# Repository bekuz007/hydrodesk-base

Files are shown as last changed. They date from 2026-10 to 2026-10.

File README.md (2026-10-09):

# 💧 HydroDesk Base

**Smarter Trinkmengen-Untersetzer für den Schreibtisch** – ESP32 mit Touch-Display, Wägezelle und LED-Lichtlinie.
Schulprojekt im Ausbildungsberuf Fachinformatiker/-in für Anwendungsentwicklung (FI-AE), 2 Auszubildende.

HydroDesk Base ist ein flaches, rechteckiges Gerät (180 × 100 × 25 mm), auf das man **jede beliebige Wasserflasche** stellt.
Eine 5-kg-Wägezelle misst das Gewicht und rechnet es in getrunkene Milliliter um.
Das eingebaute 2,8"-Touch-Display zeigt Tagesziel, Fortschritt und Erinnerungen – eine gleichmäßig leuchtende Lichtlinie an der Vorderkante (COB-LED-Streifen hinter einem gedruckten Diffusor) erinnert ans Trinken.

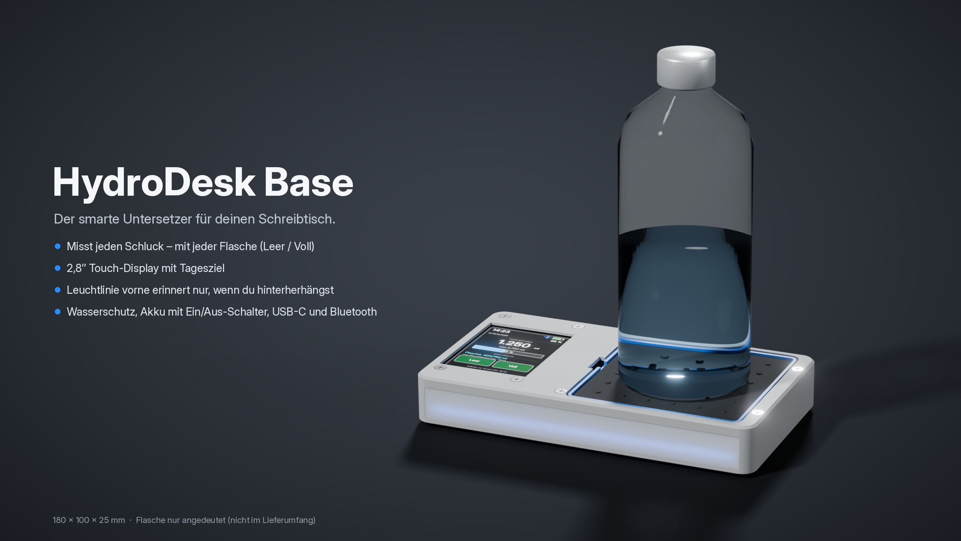
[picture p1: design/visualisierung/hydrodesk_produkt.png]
HydroDesk Base – Produktbild


## ✨ Funktionen

- **Jede Flasche passt** – keine teure Smart-Flasche nötig
- **Gewicht → ml**: 5-kg-Wägezelle + HX711 unter einem schwimmend gelagerten 90 × 90 mm Flaschen-Pad
- **Flaschen-Kalibrierung per Touch-Tasten „Leer“ und „Voll“**: leere Flasche auflegen → Leer, volle Flasche → Voll; Inhalt = aktuelles Gewicht − Leergewicht
- **Tagesziel, Fortschritt und nächste Erinnerung** immer sichtbar auf dem Display
- **LED-Lichtlinie** an der Vorderkante: COB-LED-Streifen WS2812B (26 einzeln ansteuerbare LEDs, 5 mm breit) hinter einer gedruckten Diffusor-Leiste – keine einzelnen Lichtpunkte, sondern eine durchgehende Linie:
  - 🔵 blau = trinken
  - 🟢 grün = Ziel erreicht
  - 🔴 rot = Akku niedrig / Fehler
  - bei Wasser bleibt der Streifen dunkel (ab V4 ohne Strom)
- **Wasser-Sicherheitsabschaltung**: Regensensor erkennt Nässe, ein P-MOSFET (AO3401A, High-Side) schaltet die 5 V des LED-Streifens ab → Sperrbildschirm **„WASSER ERKANNT · STROM AUS“**
- **Akkubetrieb**: LiPo 2000 mAh, Laden per USB-C (TC4056), 5-V-Wandler Pololu S13V10F5
- **Ein/Aus-Schalter (V4)** in der linken Wand (Gravur AN/AUS): schaltet über einen zweiten AO3401A den Akku wirklich ab; Laden geht in beiden Stellungen
- **Stromsparmodus (Firmware V4)**: Display dimmt nach 30 s und geht nach 2 min aus (nachts nach 15 s),
  Light-Sleep, Bluetooth nur in kurzen Fenstern, WLAN nur zum Uhr-Abgleich, Akku-Schutz bei 3,30 V;
  der LED-Streifen bekommt nur Strom, wenn er leuchtet
- **Akkulaufzeit (geschätzt, noch nicht gemessen)**: ca. 27–54 h im 24-h-Tag (vorher ca. 6–12 h) – Rechnung und Messplan im [Stromsparplan](doku/Stromsparplan_HydroDesk.md)
- **Optional: Telegram-Bot** für Erinnerungen und Status (`/status`, `/ziel`, `/hilfe`)
- **3D-gedrucktes Gehäuse** (OpenSCAD, parametrisch, sechs Druckdateien: Bodenwanne, Deckel, Pad, steckbare USB-Abdeckkappe, Diffusor-Leiste, 2 Klemmkeile für den Schalter; ohne Stützmaterial druckbar)
- **Android-App** ([`app-android/`](app-android/)): Login (Supabase), Bluetooth-LE-Verbindung zum Gerät,
  Tagesziel aus Körperdaten, Verlauf mit Wochendiagramm, offline-fähig mit Sync, Admin-Übersicht, Demo-Modus

## 📐 Aufbau / Layout

```
+----------------------------------------------------------+
|  [ DISPLAY  ]  |  Mittel-  |  [                       ]  |
|  [ Hochform.]  |  streifen |  [   FLASCHEN-PAD 90x90  ]  |
|  [  2,8"    ]  |           |  [   (schwimmend auf der ]  |
|  [  Touch   ]  |           |  [    Wägezelle)         ]  |
+----------------------------------------------------------+
|  Lichtlinie vorne: COB-LED-Streifen (26 LEDs) + Diffusor |
```

- **Links:** ESP32-Touch-Display („Cheap Yellow Display“ ESP32-2432S028R) im Hochformat, darunter Akku und 5-V-Wandler (Pololu S13V10F5)
- **Mitte:** TC4056-USB-C-Lader an der Rückwand, FET-Platine (30 × 24,5 mm, 2 × AO3401A + BC547B), Auswertemodul des Regensensors
- **Links außen:** Ein/Aus-Schiebeschalter (C&K OS102011MS2QN1) in einer Tasche der Seitenwand, gehalten von 2 Klemmkeilen
- **Rechts:** 90 × 90 mm Flaschen-Pad, liegt nur auf der Wägezelle (1 mm Spalt rundherum); darunter Wägezelle, HX711 und Regensensor
- **Hinten:** USB-Öffnungen – Programmier-Öffnung des CYD mit **steckbarer Abdeckkappe**, USB-C zum Laden offen; **vorne:** Lichtkammer über fast die ganze Breite – der COB-Streifen klebt an ihrer Rückwand, davor sitzt die 1 mm dünne Diffusor-Leiste in einem Falz

| Explosionsansicht | Innenansicht ohne Deckel |
|---|---|
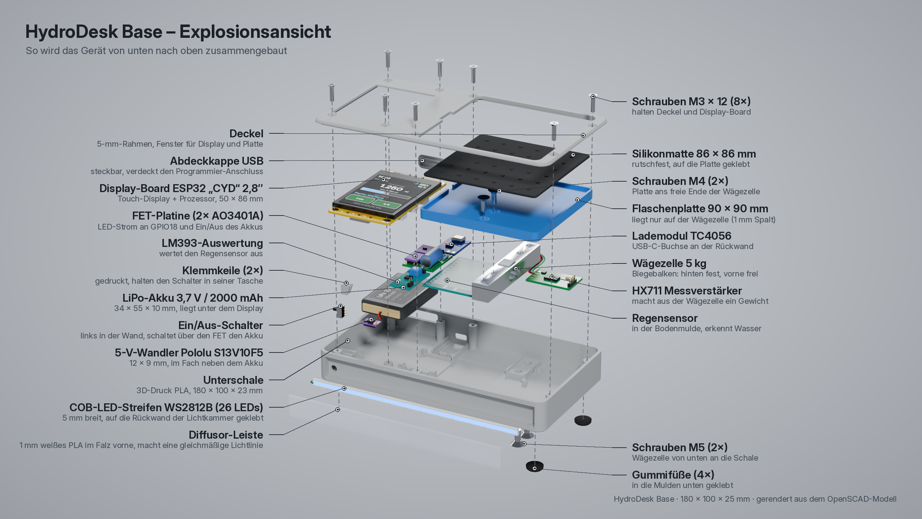
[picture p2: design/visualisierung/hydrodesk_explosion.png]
Explosionsansicht
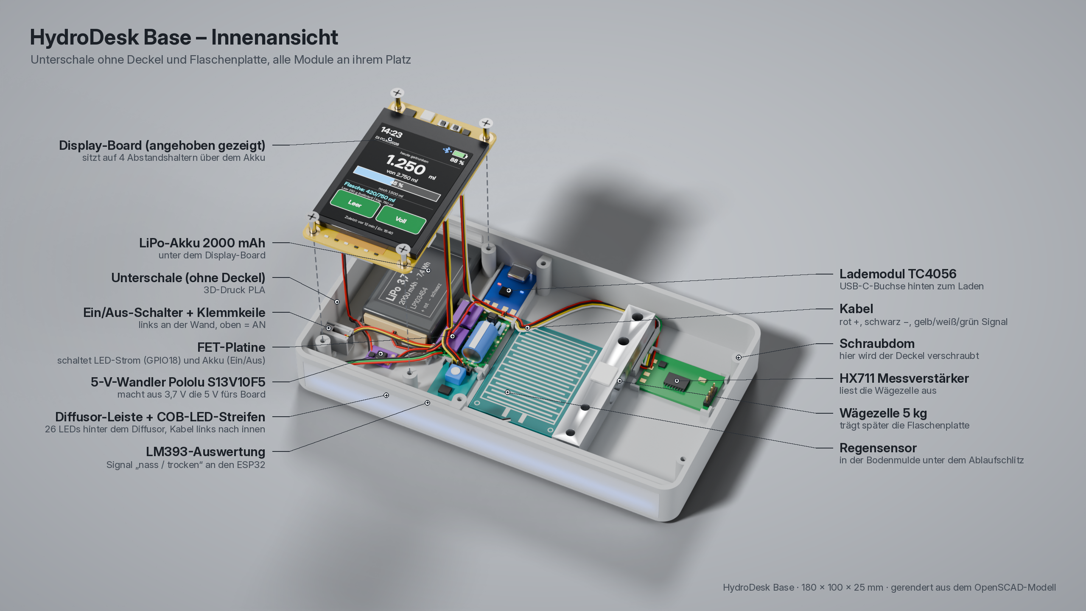
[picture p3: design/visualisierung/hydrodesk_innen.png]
Innenansicht ohne Deckel
|  |  |

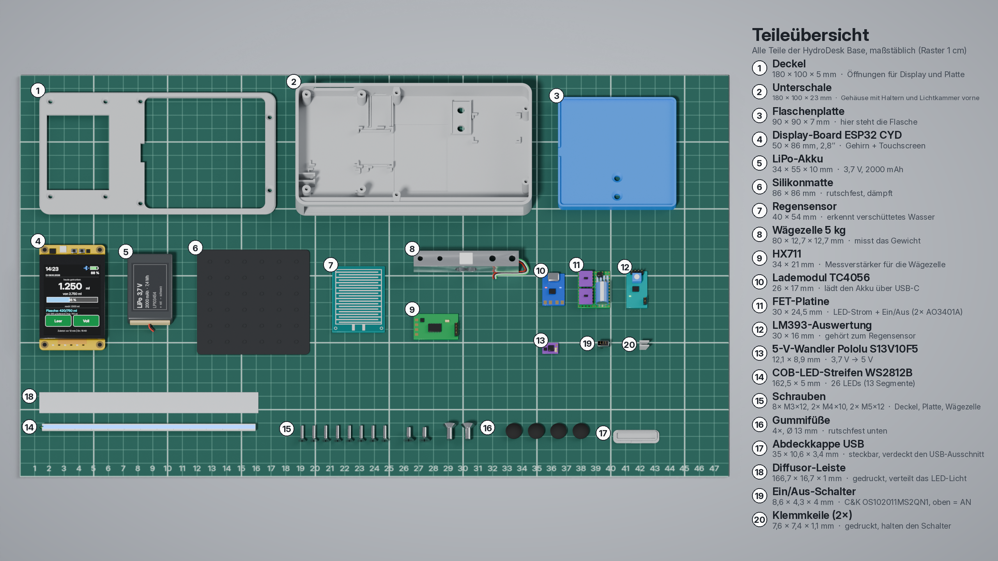
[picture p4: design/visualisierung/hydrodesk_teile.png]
Alle Einzelteile


| Abdeckkappe eingesteckt | Abdeckkappe herausgezogen |
|---|---|
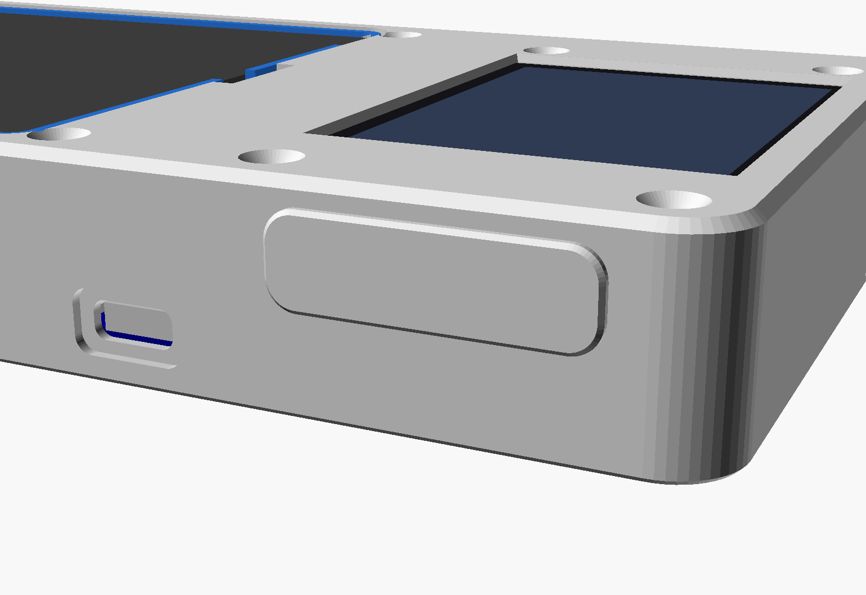
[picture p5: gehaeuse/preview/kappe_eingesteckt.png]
Abdeckkappe eingesteckt
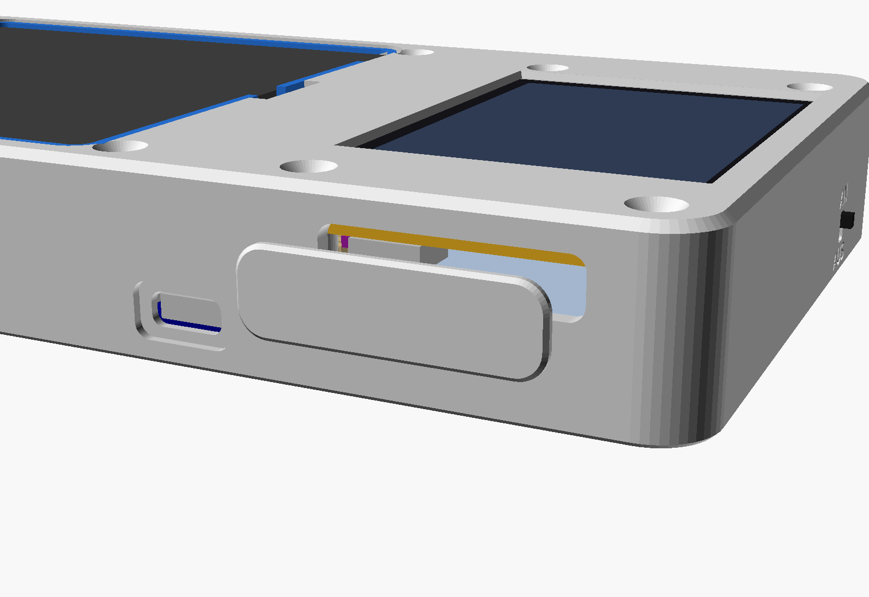
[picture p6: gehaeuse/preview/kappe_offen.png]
Abdeckkappe offen
|  |  |

| Diffusor-Leiste herausgezogen (COB-Streifen dahinter) | Schnitt durch die Lichtkammer |
|---|---|
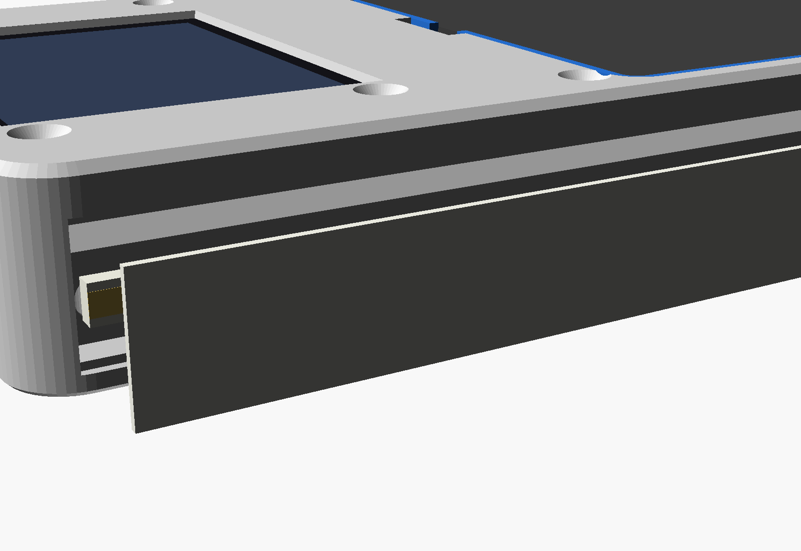
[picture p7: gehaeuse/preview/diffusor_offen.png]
Diffusor offen
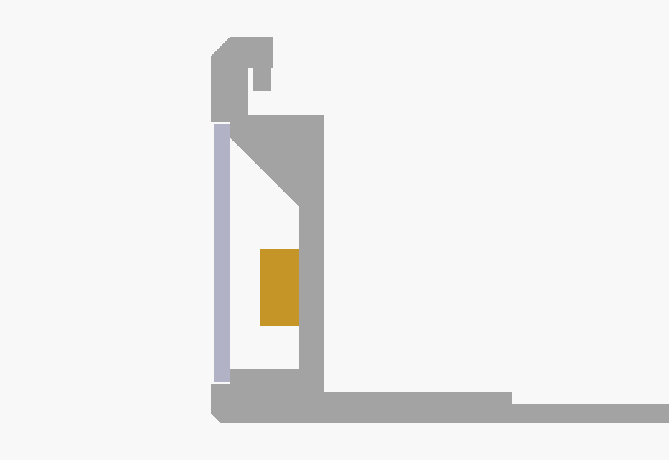
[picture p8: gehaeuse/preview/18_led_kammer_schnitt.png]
Schnitt Lichtkammer
|  |  |

| Ein/Aus-Schalter links (V4) | FET-Platine (V4) |
|---|---|
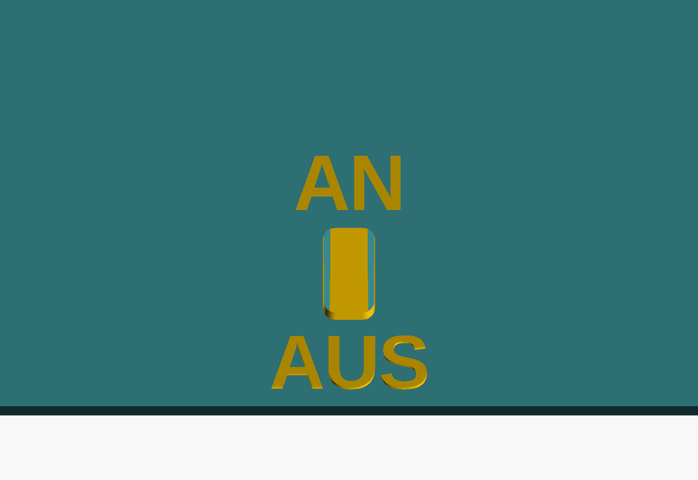
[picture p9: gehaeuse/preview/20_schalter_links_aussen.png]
Ein/Aus-Schalter
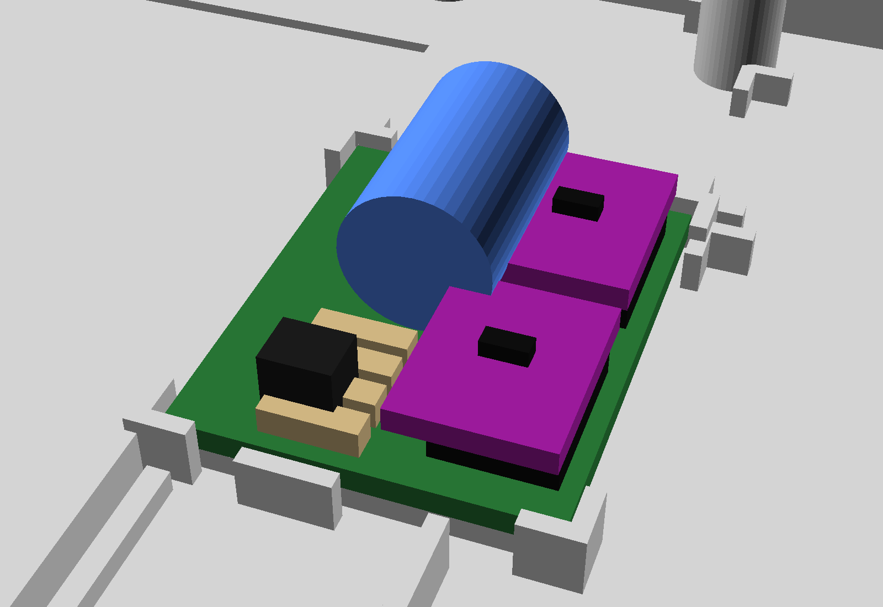
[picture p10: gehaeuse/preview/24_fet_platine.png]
FET-Platine
|  |  |

Renderbilder: [`design/visualisierung/`](design/visualisierung/) · 3D-Modell zum Drehen (GLB/STL/3MF): [`design/3d_modell/`](design/3d_modell/) · technische OpenSCAD-Vorschauen: [`gehaeuse/preview/`](gehaeuse/preview/)

Details zu Druck, Schrauben und Zusammenbau: [`gehaeuse/ANLEITUNG.md`](gehaeuse/ANLEITUNG.md)

## 🧰 Hardware / Stückliste

Zusammenfassung aus der [Vorkalkulation](doku/Vorkalkulation_HydroDesk_Base.xlsx). Die Preise sind inkl. MwSt. von Amazon.de, Berrybase.de, Reichelt.de, alleschrauben.de und AliExpress, Stand 08.10.2026 (neue V4-Teile Pos. 5 und 24–34: 09.10.2026), und können sich ändern. Der Preisvergleich mit allen Alternativen steht in der [Einkaufsliste](doku/Einkaufsliste_HydroDesk_guenstig.xlsx).

| Pos. | Bauteil | Produkt | Shop | Packung | Preis |
|---:|---|---|---|---|---:|
| 1 | ESP32 + Touch-Display | Fastsaw ESP32 mit 2,8" ILI9341 Touch (ESP32-2432S028R, ASIN B0G1N16Q16) | Amazon | 1 Stk. | 17,99 € |
| 2 | Wägezelle + Verstärker | DIYmalls Wägezelle 5 kg + HX711 | Amazon | 1 Set | 8,97 € |
| 3 | LED-Streifen (COB) | BTF-LIGHTING WS2812B FCOB, 1 m, 160 LED/m, 5 V, 5 mm (ASIN B0H41MCVSW; 26 LEDs werden gebraucht) | Amazon | 1 m | 16,99 € |
| 4 | Feuchtigkeitssensor | Regensensor LM393 (digital + analog) | Berrybase | 1 Set | 1,80 € |
| 5 | LED-Strom + Ein/Aus (P-MOSFET) | Alpha & Omega AO3401A, P-Kanal, −30 V, −4 A, SOT-23 | Reichelt | 2 Stk. | 0,34 € |
| 6 | Akku | EEMB LiPo 3,7 V 2000 mAh (LP103454) | Amazon | 1 Stk. | 10,99 € |
| 7 | Lademodul | TC4056 USB-C Lademodul mit Schutz | Amazon | 10 Stk. | 6,99 € |
| 8 | 5-V-Wandler | Pololu S13V10F5, 5 V 1 A Step-Up/Step-Down | Berrybase | 1 Stk. | 9,95 € |
| 9 | Gummifüße | FIX&FASTEN Ø10 mm, selbstklebend | Berrybase | 4 Stk. | 0,60 € |
| 10 | Flaschen-Pad | FICOFISE Silikonmatte 40 × 30 cm (auf 86 × 86 mm zuschneiden) | Amazon | 1 Stk. | 7,59 € |
| 11 | Schrauben | Senkkopf M3×12 DIN 7991 A2 | alleschrauben.de | 10 Stk. | 2,50 € |
| 12 | Schrauben | Senkkopf M4×10 DIN 7991 A2 | alleschrauben.de | 2 Stk. | 1,12 € |
| 13 | Schrauben | Senkkopf M5×12 DIN 7991 A2 | alleschrauben.de | 2 Stk. | 1,24 € |
| 14 | Widerstände | 10 kΩ Metallschicht (Akku-Spannungsteiler) | Berrybase | 2 Stk. | 0,10 € |
| 15 | Litze | Vierlingslitze 4 × 0,14 mm² | Berrybase | 5 m | 3,50 € |
| 16 | Schrumpfschlauch | Set 100-teilig | Berrybase | 1 Set | 2,80 € |
| 17 | Klebeband | TESA doppelseitig 12 mm | Berrybase | 1 Rolle | 2,90 € |
| 18 | Kabelbinder | 100 × 2,5 mm | Berrybase | 100 Stk. | 0,60 € |
| 19 | JST-Kabel CYD | Micro JST 1,25 mm, 4-polig (**nur AliExpress**, ab-Preis) | AliExpress | 1 Set | 1,49 € |
| 20 | microSD-Sniffer | für GPIO 18/19/23 am SD-Slot (**nur AliExpress**, ab-Preis) | AliExpress | 1 Stk. | 2,39 € |
| 21 | Gehäuse-Material | SUNLU PLA 1,75 mm | Amazon | 1 kg | 14,99 € |
| 22 | Abdeckkappe | gedruckt aus Pos. 21 (ca. 1 g) | – | 1 Stk. | 0,00 € |
| 23 | Diffusor-Leiste | gedruckt aus weißem PLA oder naturfarbenem PETG (ca. 4 g, 1 mm, 100 % Füllung) | – | 1 Stk. | 0,00 € |
| 24 | Treiber-Transistor | BC547B, NPN, TO-92 | Berrybase | 1 Stk. | 0,17 € |
| 25 | Widerstand | 470 Ω Metallschicht (Datenleitung DIN) | Berrybase | 1 Stk. | 0,05 € |
| 26 | Widerstand | 4,7 kΩ Metallschicht (GPIO18 → Basis) | Berrybase | 1 Stk. | 0,06 € |
| 27 | Widerstände | 47 kΩ Metallschicht (Basis→GND, Gate→Source Q2) | Berrybase | 2 Stk. | 0,10 € |
| 28 | Widerstand | 10 kΩ Metallschicht (Gate→Source Q1) | Berrybase | 1 Stk. | 0,05 € |
| 29 | SOT-23-Adapter | SMD-Breakout-Adapter SOT23/SSOP10/MSOP10 | Berrybase | 2 Stk. | 0,64 € |
| 30 | Elko | 470 µF / 25 V, radial Ø 10 × 16 mm | Berrybase | 1 Stk. | 0,10 € |
| 31 | Lochrasterplatine | einseitig Kupfer, auf 30 × 24,5 mm zuschneiden | Berrybase | 1 Stk. | 1,10 € |
| 32 | Ein/Aus-Schalter | Schiebeschalter C&K OS102011MS2QN1 (ON-ON, Printmontage) | Berrybase | 1 Stk. | 0,70 € |
| 33 | Klemmkeile | gedruckt aus Pos. 21 (unter 1 g) | – | 2 Stk. | 0,00 € |
| 34 | Stiftleiste | 1 × 20-polig, RM 2,54 mm (für die SOT-23-Adapter) | Berrybase | 1 Stk. | 0,20 € |
| | **Summe Bauteile** | | | | **119,01 €** |
| | Versand (Amazon 0,00 € ab 49 €, Berrybase 4,95 €, Reichelt 5,95 €) | | | | 10,90 € |
| | Puffer 10 % (Verschnitt, Ersatz, unbekannter Versand) | | | | 11,90 € |
| | **Gesamt geplant** | | | | **141,81 €** |
| | Gesamt ohne PLA (falls die Schule druckt) | | | | 125,32 € |

**Hinweise zur Stückliste**

- **Versand:** Die Versandkosten von alleschrauben.de und AliExpress werden erst im Warenkorb angezeigt und sind noch nicht eingepreist. Der Puffer deckt sie ab.
- **AliExpress-Teile (Pos. 19/20):** Lieferzeit 1–3 Wochen. Pos. 19 entfällt, wenn beim CYD Kabel dabei sind. Pos. 20 entfällt, wenn direkt an die Lötpunkte gelötet wird.
- **LED-Streifen (Pos. 3):** Seit 08.10.2026 ein COB-Streifen statt des WS2812-ECO-Streifens mit sichtbaren Einzelpunkten (9,49 €, jetzt in der Vorkalkulation unter „Gestrichen“). Bei Amazon die Variante „1M 160LEDs/m 5mm“ wählen. Günstigste Alternative: AliExpress ab 7,59 € (Preis der Variante nicht lesbar). In die Datenleitung gehört ein Widerstand 330–470 Ω direkt am Streifen.
- **V4 (Pos. 5, 24–34):** Das GERUI-FET-Modul (Low-Side, 6,49 €) ist gestrichen. Stattdessen eine kleine FET-Platine mit 2 × AO3401A: Q1 schaltet die 5 V des LED-Streifens (über BC547B an GPIO18), Q2 ist der Akku-Schalter. Berrybase führt keinen P-MOSFET, deshalb kommt der AO3401A von Reichelt (eigener Versand 5,95 €). Schaltplan und Aufbau: [`gehaeuse/ANLEITUNG.md`](gehaeuse/ANLEITUNG.md) Kapitel 7b/7c.
- **Einkaufskörbe** (Einkaufsliste): schnell (DE-Shops) **111,04 €** + Versand alleschrauben.de, günstig (mit AliExpress) **94,98 €** – jeweils inkl. bekanntem Versand, ohne Puffer.
- **Widerstände (Pos. 14):** 2 × 10 kΩ statt 100 kΩ, weil 100 kΩ bei Berrybase nicht lieferbar ist. Das Teilerverhältnis ist gleich, die Firmware muss nicht angepasst werden.
- **Optional, nicht in der Summe:**
  - Elegoo Jumperkabel-Set (6,99 €), nur für einen Testaufbau auf dem Breadboard.
  - JST-PH-Verlängerung für den Akku (0,90 €).
- Weitere Kleinteile stehen in der [Anleitung](gehaeuse/ANLEITUNG.md#4-einkaufsliste-schrauben-und-kleinteile).

## 📁 Ordnerstruktur

```
hydrodesk-base/
├── doku/
│   ├── Steckbrief_HydroDesk_Base.docx      # Projekt-Steckbrief
│   ├── Einkaufsliste_HydroDesk_guenstig.xlsx  # Preisvergleich DE-Shops / AliExpress
│   ├── Stromsparplan_HydroDesk.md          # Stromsparen: Plan, Umsetzung V4, Laufzeit, Messplan
│   └── Vorkalkulation_HydroDesk_Base.xlsx  # Kostenkalkulation / Stückliste
├── design/
│   ├── claude_design_prompt_aufbau.md      # Prompt für Aufbau-/Teile-Illustrationen
│   ├── visualisierung/                     # Gerenderte Bilder: Explosion, Innen, Teile, Produkt
│   └── 3d_modell/                          # Komplettes 3D-Modell (GLB/STL/3MF) zum Anschauen
├── gehaeuse/
│   ├── hydrodesk_base.scad                 # Parametrisches OpenSCAD-Modell
│   ├── ANLEITUNG.md                        # Druck- und Montageanleitung
│   ├── QUELLEN.md                          # Quellen der Bauteil-Maße
│   ├── render.sh                           # Erzeugt die Vorschaubilder neu
│   ├── stl/                                # Druckfertige Teile: base, cover, pad, kappe_usb, diffusor_led, schalter_keile
│   └── preview/                            # Vorschaubilder
├── firmware/                               # PlatformIO-Firmware (folgt)
│   └── secrets.example.h                   # Vorlage für Zugangsdaten
├── wokwi/                                  # Wokwi-Simulation (Sketch, Diagramm, Anleitung)
├── app-android/                            # Android-App (Kotlin, Compose) – eigene Anleitung
│   ├── README.md                           # Einrichtung Schritt für Schritt (Supabase, Android Studio)
│   └── supabase/schema.sql                 # Datenbank-Schema mit Row Level Security
├── LICENSE
└── README.md
```

## 🗺️ Status / Roadmap

| Schritt | Status |
|---|---|
| Steckbrief | ✅ fertig |
| Vorkalkulation | ✅ fertig |
| Gehäuse-CAD (OpenSCAD, STL) | ✅ Version 4 (Ein/Aus-Schalter, FET-Platine) |
| Wokwi-Simulation | ✅ Version 4 fertig (alle Varianten kompiliert, PC-Logiktest OK, auf wokwi.com testen) – inkl. Bluetooth-Symbol, LED-Status und Stromsparmodus |
| Android-App (Kotlin, Compose, Supabase) | ✅ Version 1.0 – baut (`assembleDebug`), Unit-Tests grün, Demo-Modus; BLE mit echtem Gerät noch zu testen – siehe [`app-android/README.md`](app-android/README.md) |
| Firmware (PlatformIO) | ⏳ offen |
| Bau / Integration / Tests | ⏳ offen (Strommessungen nach Stromsparplan stehen noch aus) |

## 🔐 Zugangsdaten

WLAN-Daten und der optionale Telegram-Bot-Token kommen in `firmware/secrets.h` – diese Datei ist per `.gitignore` ausgeschlossen.
Als Vorlage dient [`firmware/secrets.example.h`](firmware/secrets.example.h).

Supabase-URL und -Key der App kommen in `app-android/local.properties` (ebenfalls nicht im Git),
Vorlage: [`app-android/local.properties.example`](app-android/local.properties.example).

## 👥 Team

| Person | Schwerpunkt |
|---|---|
| Person A | Hardware, Verkabelung, Wägezelle (HX711), Feuchtigkeitssensor, Stromversorgung, Gehäuse (CAD + 3D-Druck), Zustandsautomat |
| Person B | Touch-Display und Bedienoberfläche, WLAN/NTP, optionale Telegram-Anbindung, Kalibrierungs- und Preset-Logik, Doku-Leitung |

Gemeinsam: Planung, Integration, Tests, Bericht, Präsentation.

## 📄 Lizenz




© 2026 bekuz007 – **nur für nicht-kommerzielle Nutzung**. Übersicht in [`LICENSE`](LICENSE).

| Teil | Lizenz |
|---|---|
| Code: Firmware (`wokwi/sketch.ino`, `firmware/`), Android-App (`app-android/`), Skripte (`.py`, `.sh`) | [PolyForm Noncommercial 1.0.0](LICENSE-CODE.md) |
| Hardware, Design und Doku: Gehäuse (`gehaeuse/`, `.scad`, STL), 3D-Modell, Renders, Texte und Bilder | [CC BY-NC-SA 4.0](LICENSE-HARDWARE-DOCS.md) |

- Nachbauen, Lernen und Verändern für private Zwecke, Schule und Forschung ist erlaubt – mit Nennung „HydroDesk Base von bekuz007“ und Link auf dieses Repository.
- **Kommerzielle Nutzung** (z. B. Verkauf von Geräten, Teilen, Druckdateien oder Code) nur mit vorheriger schriftlicher Erlaubnis – Kontakt über [GitHub](https://github.com/bekuz007).
- Fassungen bis Commit `e5ad237` (09.10.2026) wurden unter MIT veröffentlicht; wer sie schon hat, darf genau diese Fassung weiter nach MIT nutzen.

Die Maßzeichnungen und Datenblätter Dritter, die für die Konstruktion verwendet wurden, sind nicht Teil dieses Repositorys – siehe [`gehaeuse/QUELLEN.md`](gehaeuse/QUELLEN.md).

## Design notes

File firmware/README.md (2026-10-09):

# Firmware

> **Folgt.** Die Firmware wird mit **PlatformIO** (Arduino-Framework) für das ESP32-2432S028R
> („Cheap Yellow Display“) entwickelt.

Geplante Module:

* Wägezelle über HX711 (Tara, Kalibrierung, Umrechnung Gewicht → ml)
* Touch-Oberfläche (ILI9341, 320 × 240): Presets Leer / 300 / 500 / 750 / 1000 / 1500 ml / Voll, Tagesziel, Fortschritt
* COB-LED-Streifen WS2812B (26 LEDs) hinter der gedruckten Diffusor-Leiste (blau = trinken, grün = Ziel, rot = Akku/Fehler).
  Seit V4 bekommt der Streifen nur Strom, wenn er leuchtet (P-MOSFET AO3401A an GPIO18), bei Wasser ist er dunkel
* Nässe-Erkennung (Regensensor) → LED-Strom-FET aus, Sperrbildschirm „WASSER ERKANNT · STROM AUS“
* WLAN/NTP (V4: nur kurz zum Uhr-Abgleich), optional Telegram-Bot (`/status`, `/ziel`, `/hilfe`)
* Bluetooth Low Energy (BLE): Gerät „HydroDesk“, Status-Symbol neben dem Akku, LEDs weiß blinkend
  beim Suchen und 2× lila beim Verbinden (Logik schon fertig in [`../wokwi/sketch.ino`](../wokwi/sketch.ino), Version 4)
* Stromsparmodus (V4): Display dimmen/aus, Light-Sleep, Bluetooth in Fenstern, Akku-Schutz (siehe unten)

## Bluetooth (BLE) – Hinweise für die echte Firmware

Stand aus der Wokwi-Simulation V4 (dort hinter dem Schalter `#define HYDRO_BLE 1`):

* **Bibliothek:** [NimBLE-Arduino](https://github.com/h2zero/NimBLE-Arduino) (getestet 2.5.1 mit
  Arduino-ESP32-Kern 3.3.12). PlatformIO: `lib_deps = h2zero/NimBLE-Arduino@^2.5.1`.
  Die eingebaute Bluedroid-BLE-Bibliothek ist zu groß (schon ein Minimal-Test mit WLAN + BLE:
  1,62 MB = 123 % der Standard-App-Partition).
* **Partition (Pflicht seit V4):** WLAN + NimBLE + Display + Waage + Stromsparen ist **682 Byte
  zu groß** für die Standard-Partition (1 311 402 B von 1 310 720 B). Darum die Partition
  **Huge APP** nehmen (dann 41 %):
  * PlatformIO: `board_build.partitions = huge_app.csv`
  * Arduino-IDE: *Werkzeuge → Partition Scheme → Huge APP (3MB No OTA/1MB SPIFFS)*
  * Mit OTA-Updates: `min_spiffs.csv` (1,9 MB App)
* **GATT:** Dienst `4f9a0001-6c1e-4b8e-9d6a-2b7c1e0a4d10`, Characteristic
  `4f9a0002-6c1e-4b8e-9d6a-2b7c1e0a4d10` (lesen + notify, Text „heute/Ziel ml“, z. B. `1250/2750 ml`).
* **Ablauf (V4, Option A):** Bluetooth ist nur in **Fenstern** sichtbar: beim Start 2 min
  (`BT_SUCH_TIMEOUT_MS`), nach **Antippen des Bluetooth-Symbols** 2 min und **60 s still** nach jedem
  erkannten Trinken/Nachfüllen (`BT_SYNC_FENSTER_MS`). Bei Trennung startet ein Fenster derselben
  Art. Danach Werbung aus und **`NimBLEDevice::deinit(true)`**; das nächste Fenster legt Server,
  Dienst und Werbung neu an (nach `deinit(false)` registriert NimBLE 2.5.1 den GATT-Dienst nicht neu).
  Die Callbacks setzen nur einen Merker, ausgewertet wird im `loop()`.
  **Für die App:** verbinden, sobald „HydroDesk“ in der Werbung auftaucht, Wert lesen, wieder trennen.
* **Noch auf echter Hardware zu testen:** Verbinden mit Handy (z. B. nRF Connect), Notify, WLAN +
  BLE gleichzeitig (Coexistence), 20× `deinit`/`init` im Wechsel, Stromverbrauch.

## Stromsparen (V4) – Hinweise für die echte Firmware

Vollständig beschrieben in [`../wokwi/README.md`](../wokwi/README.md), Kapitel 18, und im
Stromsparplan (`doku/Stromsparplan_HydroDesk.md`). Kurz:

* **Kein automatischer Light-Sleep:** Der Arduino-Kern 3.3.12 ist ohne `CONFIG_PM_ENABLE` gebaut.
  Der Sketch schläft darum **von Hand** (`esp_light_sleep_start()`), nur in RUHE und nur mit
  `HYDRO_CYD 1` (`HYDRO_LIGHTSLEEP`). Vorher sind WLAN und BLE aus. Wecken: Timer bis zur nächsten
  Waagen-Messung (≤ 100 ms, die Waage misst weiter 10×/s), GPIO19 LOW (Nässe), GPIO36 LOW (Touch).
* **Pins im Schlaf:** GPIO18 (LED-Strom-FET), 21 (Licht), 22 (HX711-SCK), 23 (DIN) werden mit
  `gpio_hold_en()` gehalten (`RUHE_PINS_HALTEN`), nach dem Wecken freigegeben.
* **Display:** Licht per LEDC-PWM an GPIO21 (255 / 40 / 0), in RUHE `DISPOFF` + `SLPIN`.
* **Touch:** Die XPT2046-Bibliothek läuft **ohne** IRQ-Pin (`XPT2046_Touchscreen touch(33)`). Der
  Sketch liest GPIO36 selbst (HIGH = sicher nicht berührt) und bestätigt per Druckmessung (Errata
  GPIO36). Die erste Berührung im gedimmten/dunklen Zustand weckt nur.
* **WLAN:** nur zum Uhr-Abgleich (Start, alle 6 h, Befehl `sync`, Timeout 20 s), Abweichung im Protokoll.
  Telegram später: kurz verbinden, senden, wieder aus.
* **CPU:** 80 MHz (`setCpuFrequencyMhz(80)`).
* **Akku:** Prozent per LiPo-Tabelle (typische Kurve, nach eigener Entlademessung ersetzen),
  Schutz: 60 s unter 3,30 V → Meldung → Tiefschlaf (15-min-Timer), Neustart erst ab 3,60 V.
* **Hardware dazu:** LED-Strom-Schalter (AO3401A + BC547B an GPIO18) und Ein/Aus-Schalter in der
  Akku-Leitung, siehe `../gehaeuse/ANLEITUNG.md`.
* `stromsparen 0` (Serial) bzw. `#define STROMSPAREN 0` = Verhalten wie V3 zum Vergleichen.

## Zugangsdaten

Zugangsdaten gehören **niemals** ins Repository.
`secrets.example.h` nach `secrets.h` kopieren und dort die echten Werte eintragen –
`secrets.h` ist per `.gitignore` ausgeschlossen.

```bash
cp secrets.example.h secrets.h
```

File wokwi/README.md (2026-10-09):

# HydroDesk Base – Wokwi-Simulation (ESP32) · Version 4

Mit dieser Simulation könnt ihr die komplette Logik von **HydroDesk Base** im Browser testen,
**bevor** ihr Teile kauft. Ihr braucht nur einen Browser und die Seite **wokwi.com**.

**Neu in Version 4 (Stromsparen, Details in [Kapitel 18](#18-stromsparen-neu-in-version-4)):**

- **Display:** nach 30 s ohne Aktivität **gedimmt**, nach 2 min **aus** (RUHE), nachts (22–7 Uhr)
  schon nach 15 s aus. Die erste Berührung im gedimmten/dunklen Zustand **weckt nur** (sie löst
  keine Taste aus). In Wokwi zeigt die neue Hilfs-LED **„LICHT“** an GPIO21 die Helligkeit.
- **WLAN nur zum Uhr-Abgleich** (beim Start, alle 6 h, Befehl `sync`, höchstens 20 s), danach aus.
  Die Abweichung der Uhr steht im Protokoll.
- **Bluetooth nur in Fenstern:** beim Start 2 min, **Antippen des Bluetooth-Symbols** 2 min
  (behebt: Gerät war nach der Suche nicht mehr sichtbar zu machen), 60 s still nach jedem Trinken.
- **LED-Streifen:** bekommt nur Strom, wenn er leuchtet (P-MOSFET an GPIO18). Die Erinnerung
  leuchtet 2 min voll blau, danach ruhiges **Sparblau**. Bei Wasser ist der Streifen **dunkel**
  (kein Bernstein mehr, er hat dann keinen Strom).
- **CPU 80 MHz**, auf dem echten CYD **Light-Sleep** in RUHE (Waage weiter 10×/s).
- **Akku-Prozent per LiPo-Tabelle** (typische Kurve) und **Schutzabschaltung** bei leerem Akku.
- Serieller Befehl **`stromsparen 0`** = Verhalten wie Version 3 (zum Vergleichen).

**Neu in Version 3 (Erinnerung + Flaschen-Kalibrierung):**

- **Erinnerungslogik:** Nach einem Schluck von ≥100 ml (im ~10-min-Fenster) startet eine
  **75-min-Pause** (keine Erinnerung, kein blaues LED, kein Telegram-Stub). Schlucke unter
  40 ml zählen zum Tagesstand, setzen die Pause aber nicht. Erinnerung nur, wenn ihr
  **hinter dem Tagesplan** liegt, die Pause vorbei ist, der Mindestabstand (90 min) eingehalten
  ist, höchstens 6×/Tag, und **außerhalb der Ruhezeit 22:00–07:00**. Plan: bis 12:00 ≈40 %,
  bis 16:00 ≈70 %, bis 20:00 (ca. 2 h vor Ruhezeit) 100 % des Ziels.
- **Wokwi-Demo-Zeiten:** `#define WOKWI_DEMO_ERINNERUNG 1` (Standard in der Simulation) nutzt
  kurze Zeiten (Pause 90 s, Abstand 60 s, Fenster 20 s), damit Tests machbar sind. Auf dem
  echten Gerät: `WOKWI_DEMO_ERINNERUNG 0` → lange Zeiten. Der alte ~30-s-Trigger ist entfernt.
- **Flaschen-Kalibrierung mit sichtbaren Touch-Tasten „Leer“ und „Voll“** (Hauptbildschirm
  und Kalibrier-Bildschirm, FT6206). Ablauf: leere Flasche aufstellen → **Leer** tippen
  (Gewicht ~1 s ruhig) → volle Flasche → **Voll** tippen → Kapazität = voll − leer (1 g ≈ 1 ml).
  Anzeige „Flasche x/y ml“. Fehler (kein Leer, Voll ≤ Leer, unruhig) erscheinen **auf dem
  Display** auf Deutsch. Serial `kalib` / `leer` / `voll` funktioniert weiter. Werte in Preferences.
- **Bluetooth-Symbol** und LED-Status wie bisher (Suchen weiß, verbunden 2× lila). Wokwi:
  `bt suchen` / `bt verbunden` / `bt getrennt` / `bt aus`. Echtes BLE: `HYDRO_BLE 1`.

**Neu in Version 2:**

- Den Flascheninhalt rechnet das Gerät selbst aus; das Leergewicht **lernt** es automatisch,
  oder ihr kalibriert es mit den Tasten **Leer** / **Voll**.
- Das **Tagesziel** wird aus Körpergewicht und Körpergröße berechnet (Mosteller-Formel).
- **Neues Hochformat-Layout** mit Uhrzeit, Datum, Akku, Menge, Fortschritt, Flasche und Erinnerung.
- **Echte Uhrzeit** über WLAN + NTP, mit automatischem Reset um Mitternacht.
- **LEDs ruhig:** im Normalbetrieb aus, bei Ereignissen Dauerlicht. Nur die Akku-Warnung
  blitzt kurz (2× oder 4× rot). (Seit Version 3 blinken außerdem Bluetooth-Suche und -Verbindung.)
- Die Wasser-Sperre hebt sich nach **5 s trocken** von selbst auf. Die Flaschen-Kalibrierung
  läuft über die sichtbaren Tasten **Leer** / **Voll** (optional Langdruck → Kalibrier-Bildschirm).

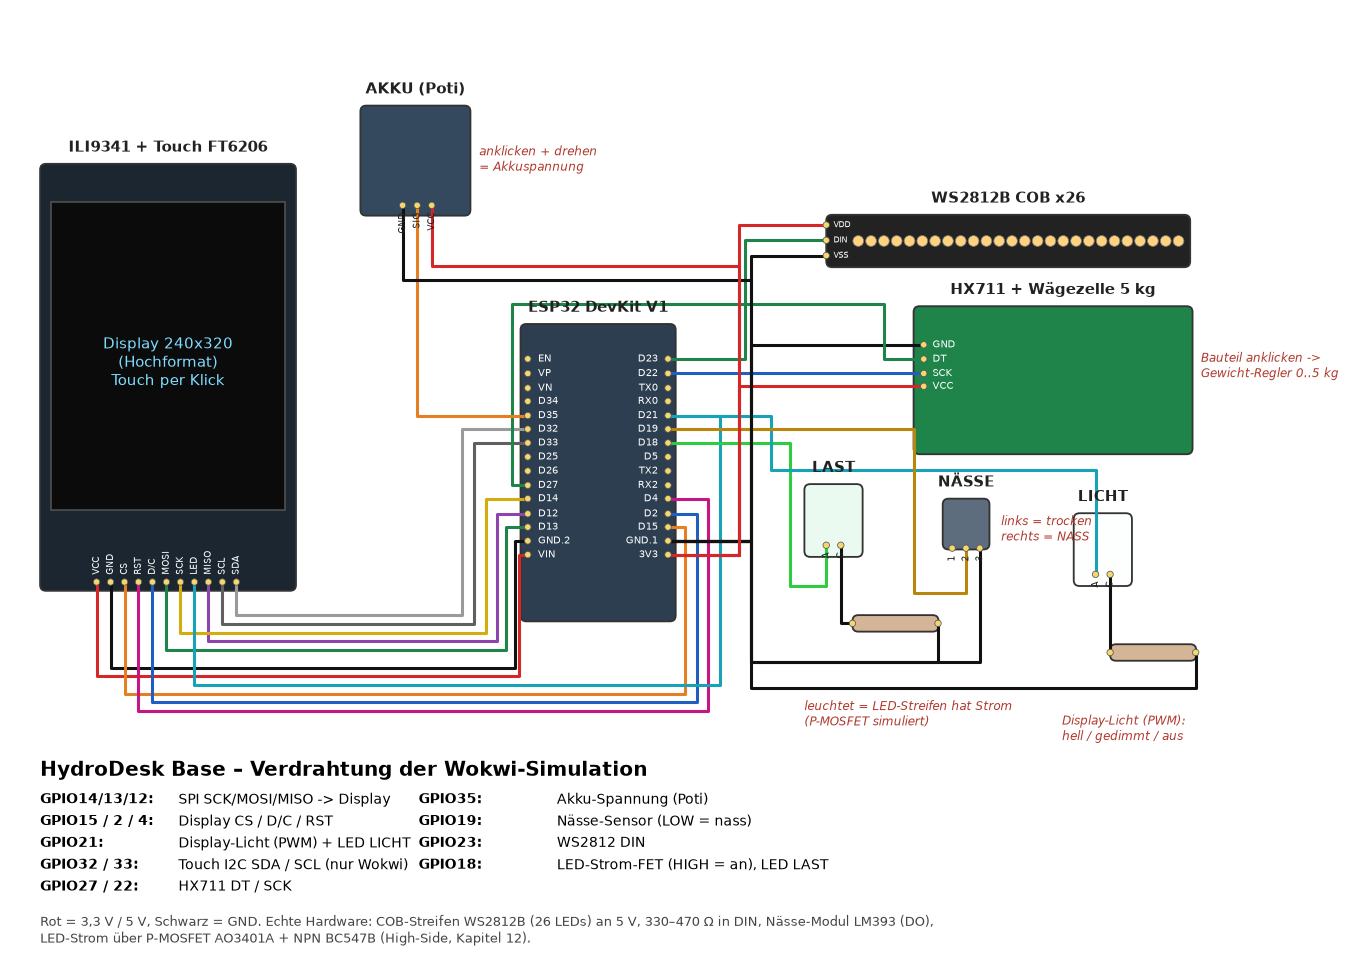
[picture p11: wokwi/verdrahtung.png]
Verdrahtung


---

## 1. Was zeigt die Simulation?

| Echtes Gerät | In der Simulation |
|---|---|
| CYD-Board (ESP32-2432S028R) mit 2,8"-Touch-Display | ESP32 DevKit + ILI9341-Display mit **kapazitivem** Touch (FT6206) |
| Wägezelle 5 kg + HX711 unter dem Flaschen-Pad | HX711-Bauteil, Gewicht per **Schieberegler** (0–5 kg) |
| Nässe-/Regensensor (LM393-Modul, Ausgang DO) | **Schiebeschalter** „NÄSSE“ (links = trocken, rechts = nass) |
| P-MOSFET AO3401A, schaltet die 5 V des LED-Streifens (GPIO18) | grüne **LED „LAST“** (leuchtet = Streifen hat Strom) |
| Hintergrundlicht des Displays (PWM an GPIO21) | weiße **LED „LICHT“** (hell / gedimmt / aus), neu in V4 |
| Akku-Spannung über Spannungsteiler 2 × 10 kΩ | **Drehregler** (Potentiometer) „AKKU“ (ganz links = 3,0 V, ganz rechts = 4,2 V) |
| COB-LED-Streifen WS2812B (BTF-LIGHTING FCOB, 26 LEDs, hinter der Diffusor-Leiste) | LED-Streifen mit 26 kleinen LEDs (`wokwi-led-strip`, `pixels` 26) |
| Heim-/Schul-WLAN + NTP | Wokwi-Gast-WLAN **„Wokwi-GUEST“** + `pool.ntp.org` |
| Telegram-Nachricht | nur Text im Seriellen Monitor: `[TELEGRAM-STUB] würde senden: ...` |

---

## 2. Der Bildschirm (240 × 320, Hochformat)

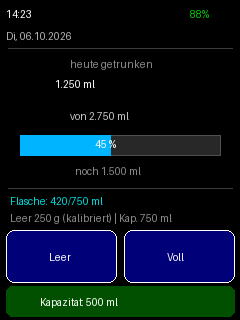
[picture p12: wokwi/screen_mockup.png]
Bildschirm-Entwurf


```
┌──────────────────────────────┐
│ 14:23             BT [▮▮▮ ]  │  Uhrzeit groß   Bluetooth + Akku-Symbol
│ Di, 06.10.2026          88%  │  Datum                Akku in %
│──────────────────────────────│
│        heute getrunken       │
│        1.250 ml              │  größtes Element
│        von 2.750 ml          │  Tagesziel
│ [██████████░░░░░░░░░] 45 %   │  Fortschrittsbalken
│         noch 1.500 ml        │  bzw. grün „Ziel erreicht ✓“
│──────────────────────────────│
│ Flasche: 420/750 ml          │  oder „Keine Flasche“ / ohne Kap. nur ml
│ Leer 250 g (kalibriert) | Kap. 750 ml │  oder „(gelernt)“ / „(Schätzwert)“
│ ┌──────────┐  ┌──────────┐   │
│ │   Leer   │  │   Voll   │   │  große Touch-Tasten (FT6206 / Wokwi)
│ └──────────┘  └──────────┘   │
│ ┌──────────────────────────┐ │
│ │ Zuletzt: vor 12 min | …  │ │  Status: Kalib-Meldung / Erinnerung / Warnung
│ └──────────────────────────┘ │
└──────────────────────────────┘
```

- **Uhrzeit:** weiß = NTP-Zeit, **gelb** = Ersatzuhr (ohne Internet), grau „--:--“ = noch keine Zeit.
  Bei der Ersatzuhr steht hinter dem Datum „(ohne NTP)“.
- **Akku oben rechts:** grün = ok, **orange unter 20 %**, **rot unter 10 %**.
  Seit V4 kommt die Prozentzahl aus einer **LiPo-Tabelle** (typische Kurve, Kapitel 18), nicht mehr
  aus einer geraden Linie 3,0–4,2 V.
- **Bluetooth-Symbol** (neu in V3) direkt **links neben dem Akku-Symbol**, aus Linien gezeichnet
  (klassische Bluetooth-Rune, 11 × 19 Pixel):

  | Zustand | Symbol |
  |---|---|
  | aus (`bt aus`) | wird **nicht gezeichnet** |
  | sucht | **blinkt** weiß/blau im Takt der LEDs (500 ms) |
  | stilles Sync-Fenster nach dem Trinken (V4) | **fest blau**, ohne Punkte |
  | verbunden | **fest blau**, links und rechts ein kleiner Punkt (siehe Bild oben) |
  | nicht verbunden (Suche nach 2 min beendet) | **grau** |

  Platz in der oberen Zeile: Uhrzeit x 6–126, Bluetooth x 168–191, Akku-Symbol x 196–231,
  Prozent darunter (y 28–43). Nichts überlappt, auch nicht bei „100%“ oder dem längsten Datum
  „Di, 06.10.2026 (ohne NTP)“ (endet bei x 158).

  **Antippen des Symbols** (Fläche x 162–193, y 0–29) macht das Gerät **2 min sichtbar** (V4).
- **Touch-Tasten „Leer“ / „Voll“** immer sichtbar auf dem Hauptbildschirm (große Treffflächen).
- **Statusfeld unten**, wichtigste Meldung zuerst:
  1. Kalibrier-Feedback / Fehler (z. B. „Zuerst Leer kalibrieren“, „Gewicht unruhig …“)
  2. „Kalib-Screen: noch X s“ (während des optionalen Langdrucks)
  3. roter Balken **„Bitte laden“**, solange der Akku unter 10 % ist (bleibt stehen)
  4. „Fehler: Waage antwortet nicht“ / „Gewicht negativ: Kalibrierung!“
  5. blau „Zeit zu trinken!“ (Erinnerung)
  6. orange „Akku unter 20 %“ (5 s nach dem Unterschreiten)
  7. sonst: zuletzt getrunken | Erinnerungs-Kurzinfo
- Es wird **nur neu gezeichnet, was sich geändert hat** (jeder Bereich merkt sich seinen letzten Text).
  Das verhindert Flackern.
- Bei Wasser erscheint weiterhin das **rote Vollbild** „WASSER ERKANNT · STROM AUS“, nach dem
  Abtrocknen mit dem Countdown „Freigabe in X s“.

---

## 3. Tagesziel aus Körpergewicht und Körpergröße

Das Tagesziel ist **nicht mehr fest**. Das Gerät berechnet es aus der **Körperoberfläche (KOF)**
nach der Formel von **Mosteller**:

```
KOF [m²]  = √( Größe [cm] × Gewicht [kg] / 3600 )
Ziel [ml] = KOF × 1500 ml/m²   → auf 50 ml gerundet → begrenzt auf 1500 … 3500 ml
```

**Beispiel (Standardwerte im Sketch: 70 kg, 175 cm):**

```
KOF  = √(175 × 70 / 3600) = √3,403 = 1,845 m²
Ziel = 1,845 × 1500 = 2767 ml  → gerundet 2750 ml
```

Weitere Beispiele (genau so im PC-Test geprüft):

| Gewicht | Größe | KOF | Ziel |
|---|---|---|---|
| 70 kg | 175 cm | 1,845 m² | **2750 ml** |
| 80 kg | 180 cm | 2,000 m² | **3000 ml** |
| 45 kg | 150 cm | 1,369 m² | **2050 ml** |
| 30 kg | 120 cm | 1,000 m² | **1500 ml** (Untergrenze) |
| 200 kg | 210 cm | 3,416 m² | **3500 ml** (Obergrenze) |

Werte ändern:
- dauerhaft im Sketch: `KOERPERGEWICHT_KG` und `KOERPERGROESSE_CM`, ganz oben;
- im laufenden Betrieb über den Seriellen Monitor: `gewicht 75` und `groesse 180`.
  Die Werte werden in `Preferences` gespeichert, das Ziel wird sofort neu berechnet.

> **Hinweis:** Das ist ein **Richtwert** für ein Schulprojekt und **keine medizinische Empfehlung**.
> Hitze, Sport, Krankheit oder ärztliche Vorgaben ändern den Bedarf.

---

## 4. Flascheninhalt und automatisch gelerntes Leergewicht

```
Flascheninhalt [ml] = ruhiges Gewicht auf dem Pad − Leergewicht der Flasche   (1 g Wasser ≈ 1 ml)
```

Das Leergewicht kennt das Gerät am Anfang nicht. Es startet mit **150 g**
(`LEERGEWICHT_START_G`; übliche Trinkflaschen wiegen leer etwa 100–400 g).
**Besser:** im Service-Modus kalibrieren (leere + volle Flasche). Kalibrierte Werte aus dem
Flash haben Vorrang; das automatische Lernen ist nur Fallback, solange nie kalibriert wurde.
Danach lernt es selbst:

| Regel | Was passiert |
|---|---|
| **1. Nachfüllen** | Wird nachgefüllt, war die Flasche davor meist (fast) leer. Das ruhige Gewicht **direkt vor dem Nachfüllen** ist ein Kandidat. Das Gerät nimmt den **kleinsten** Kandidaten als Leergewicht (Anzeige „(gelernt)“). |
| **2. Untergrenze** | Steht die Flasche einmal **leichter** da als das Leergewicht, ist dieses zu hoch. Es wird auf das gemessene Gewicht gesenkt. |
| **3. Andere Flasche** | Ist das Pad **länger als 60 s leer** und steht danach ein **deutlich anderes** Gewicht da (≥ 250 g Unterschied oder klar unter dem Leergewicht), gilt das als neue Flasche. Das Leergewicht geht zurück auf 150 g, die Referenz wird neu gesetzt, und es wird **nichts** als getrunken gezählt. |

Beispiel (echte Flasche wiegt leer 230 g, enthält 500 ml):
Abstellen 730 g → Anzeige „Flasche: 580 ml“ (mit dem Schätzwert 150 g, noch ungenau).
Austrinken bis 250 g, dann nachfüllen auf 780 g. Das Gerät lernt **250 g**, die Anzeige zeigt
„Flasche: 530 ml“. Später einmal bis 240 g ausgetrunken: Das Leergewicht sinkt auf **240 g**.

### Wie wird „getrunken“ berechnet? (unverändert)

Das Programm merkt sich das letzte **ruhige** Gewicht der Flasche („Referenz“). Wird die Flasche
abgehoben (Gewicht fast 0), werden alle Änderungen **ignoriert**. Steht sie wieder da und ist das
Gewicht **1,5 s ruhig**, wird verglichen:

- leichter als vorher (mind. 15 g) → Differenz zählt als **getrunken**
- schwerer als vorher (mind. 20 g) → **nachgefüllt**, zählt **nicht** (nicht negativ) → Regel 1
- kleine Schwankungen → werden ignoriert

---

## 5. LEDs (COB-LED-Streifen WS2812B, 26 LEDs)

Im Normalbetrieb sind **alle LEDs aus**. Sie leuchten in ruhigen Farben mit mittlerer Helligkeit
(`LED_HELLIGKEIT = 60` von 255, **höchstens 80** – Strombudget, siehe unten), immer **alle 26 gleich**.
**Dauerlicht, kein Blinken** – geblinkt wird **nur** in drei Fällen: Akku-Warnung (rot),
Bluetooth sucht (weiß) und Handy verbunden (2× lila). In der **Pause** eines Blinkmusters sind die
LEDs aus (keine Mischfarbe).

| Priorität | Farbe | Wann | Wie lange |
|---|---|---|---|
| 1 (höchste) | **aus, Streifen ohne Strom** (V4, vorher bernstein) | Wasser erkannt (`NAESSE_SPERRE`) | solange die Sperre aktiv ist |
| 2 | **rot, 2× blitzen** (300 ms an / 300 ms aus) | Akku fällt **unter 20 %** | einmal, dann aus |
| 2 | **rot, 4× blitzen** (650 ms an / 650 ms aus) | Akku fällt **unter 10 %** | einmal, dann aus (langsamer/normaler Takt) |
| 3 | **lila, 2× blinken** (300 ms an / 300 ms aus) | Handy hat sich per Bluetooth verbunden | einmal, dann normal |
| 4 | **weiß blinken, gedimmt** (500 ms an / 500 ms aus) | Bluetooth sucht das Handy (Start, `bt suchen`, Symbol antippen) | bis verbunden, höchstens **2 min**. Das stille 60-s-Fenster nach dem Trinken blinkt **nicht** |
| 5 | rot (Dauerlicht) | Fehler beginnt (Waage antwortet nicht / Gewicht negativ) | 5 s, dann aus |
| 6 | **blau**, nach 2 min **Sparblau** (V4: Helligkeit 15 statt 60) | Erinnerung („trink was!“) | bis getrunken wurde |
| 7 | **grün** | Tagesziel erreicht | 10 s, dann aus |
| – | aus | sonst | – |

**Akku-Warnung genauer:**

- Sie kommt **einmal beim Unterschreiten** der Schwelle, nicht dauernd.
- **Hysterese 2 %:** „unter 20 %“ gilt erst ab **22 %** als vorbei, „unter 10 %“ ab **12 %**.
  Wackelt der Wert um die Schwelle, blitzt es also nicht ständig.
- Solange der Akku unter der Schwelle bleibt, wiederholt sich das Blinkmuster **alle 10 min**
  (`AKKU_WIEDERHOLUNG_MS`, `0` = nie wiederholen).
- **Display unter 20 %:** Akku-Anzeige orange und 5 s lang ein oranger Hinweis „Akku unter 20 %“.
- **Display unter 10 %:** Akku-Anzeige rot und unten **dauerhaft** ein roter Balken
  **„Bitte laden“**. Er verschwindet erst, wenn der Akku wieder über 12 % liegt (geladen).
  Die 4 roten Blitze laufen im **normalen** Takt (650 ms an / 650 ms aus), nicht im schnellen
  300-ms-Takt der 20-%-Warnung.
- Fällt der Akku direkt von „ok“ auf unter 10 %, blitzt es nur **4×**, nicht 2× + 4×.
- Wasser hat Vorrang: Während der Sperre ist der Streifen dunkel (ohne Strom), das Blinkmuster läuft unsichtbar weiter.

**Bluetooth-Blinken genauer (neu in V3):**

- **Akku vor Bluetooth:** Während die Akku-Warnung blitzt, gibt es kein Weiß und kein Lila.
  Verbindet sich das Handy genau dann, **wartet** das 2× Lila, bis das Rot fertig ist.
- **Wasser vor allem:** Während der Wasser-Sperre ist der Streifen dunkel (ohne Strom). Danach
  blinkt er wieder weiß, falls die Suche noch läuft.
- **Weiß verdeckt blau/grün/rot (Fehler):** Solange die Suche läuft, sieht man die ruhigen Farben
  nicht. Darum endet die Suche nach `BT_SUCH_TIMEOUT_MS` (2 min). Danach erscheinen z. B. die
  blaue Erinnerung oder das Grün wieder.
- Das Weiß ist **gedimmt**: Farbwert `BT_WEISS_WERT = 90` je Kanal, zusätzlich `LED_HELLIGKEIT`.
- Der Serielle Monitor meldet nur, **wer** die LEDs gerade steuert (z. B.
  `[LED] weiß blinken (Bluetooth sucht)`), nicht jedes einzelne An/Aus.

### Echter Streifen: Bauteil, Verdrahtung, Strom

**Streifen:** BTF-LIGHTING WS2812B **FCOB** (COB = LEDs dicht unter einer durchgehenden Silikonschicht),
5 V, 160 LEDs/m, 5 mm breit, jede LED mit eigenem IC (einzeln ansteuerbar wie normale WS2812B, gleiche
Bibliothek Adafruit NeoPixel, `NEO_GRB + NEO_KHZ800`). Teilbar alle 12,5 mm (= 2 LEDs).
Verbaut: **13 Segmente = 162,5 mm = 26 LEDs** (`LED_ANZAHL = 26`), auf die Rückwand der Lichtkammer vorne
im Gehäuse geklebt. Davor sitzt die gedruckte **Diffusor-Leiste** (1 mm weißes PLA) – so sieht man eine
gleichmäßige Lichtlinie statt einzelner Punkte.

**Verdrahtung (echt):**

| Streifen | an | Hinweis |
|---|---|---|
| `5V` / `+` | **Drain** des P-MOSFET AO3401A (V4, H1). Source an 5 V vom Pololu S13V10F5 | nicht an 3,3 V |
| `GND` / `−` | GND | gemeinsame Masse mit dem CYD |
| `DIN` | GPIO23 | **330–470 Ω in Reihe** (verbaut: 470 Ω), direkt am Streifen-Eingang (DIN) eingelötet |
| – | Elko 470 µF/25 V zwischen 5 V und GND **vor** dem FET (Dauer-5-V-Seite) | fängt Lastsprünge ab, lädt nicht bei jedem Einschalten neu |

**LED-Strom-Schalter (V4, H1):** GPIO18 → 4,7 kΩ → Basis NPN **BC547B** (47 kΩ Basis→GND),
Emitter an GND, Kollektor an das **Gate** des P-MOSFET **AO3401A**. Gate→Source 10 kΩ (Pull-up
= standardmäßig **aus**). GPIO18 HIGH → Streifen hat 5 V, LOW/hochohmig (Reset, Booten, Flashen)
→ aus. Vor dem Ausschalten sendet der Sketch Schwarz (DIN danach LOW), nach dem Einschalten wartet
er 10 ms und sendet die Farbe neu. Details und Datenblattwerte: `gehaeuse/ANLEITUNG.md`.

Den **Eingang** des Streifens benutzen (Pfeil auf dem Streifen zeigt vom Eingang weg). Die Kabel gehen
am linken Streifenende durch das kleine Loch ins Gehäuse.

**Strom (Schätzung):** 26 LEDs voll weiß (255) ca. **0,49 A** – kommt im Programm nie vor.
Mit `LED_HELLIGKEIT = 60` höchstens ca. **0,12 A**, mit 80 ca. 0,15 A. Zusammen mit dem CYD
(ca. 0,25–0,35 A) bleibt das unter 0,5 A, der Pololu-Wandler liefert bis 1 A.
Darum `LED_HELLIGKEIT` **nicht über 80** stellen – der Sketch bricht das Kompilieren sonst mit
einer Meldung ab (`static_assert`).
In Wokwi wird kein Strom simuliert, und der Streifen hängt dort an 3,3 V.
**Ruhestrom (V4):** Ohne FET ziehen die 26 FCOB-Chips auch „schwarz“ dauernd Strom (Schätzung
ca. 12–16 mA, Stromsparplan). Mit dem FET ist der Streifen stromlos, solange er nicht leuchtet.

---

## 6. Bluetooth (neu in Version 3)

### Zustände

| Zustand | Bedeutung | Symbol | LEDs |
|---|---|---|---|
| `aus` | Bluetooth ausgeschaltet (`bt aus`) | nicht gezeichnet | – |
| `suchen` | Gerät ist sichtbar und wartet auf das Handy | blinkt weiß/blau | **weiß blinken** |
| `verbunden` | Handy verbunden | fest blau + 2 Punkte | **2× lila**, dann normal |
| `nicht verbunden` | Fenster vorbei, niemand hat sich verbunden | grau | – |

```
Start / "bt suchen" / Symbol antippen ──► suchen (laut, 2 min) ──Handy verbindet──► verbunden
Trinken/Nachfüllen erkannt (V4) ────────► suchen (still, 60 s)  ◄──Handy getrennt──┘ (gleiche Art)
                         │
       Fenster vorbei    ▼
                  nicht verbunden ──(V4: BLE-Stack aus)
jeder Zustand ──"bt aus"──► aus      (Symbol antippen schaltet wieder ein)
```

- Beim Einschalten sucht das Gerät sofort (`BT_START_SUCHEN = true`, für die Vorführung).
- Trennt sich das Handy, sucht das Gerät **wieder**, und zwar in **derselben Art** wie vorher:
  nach einer lauten Suche wieder weiß blinken (2 min), nach einem stillen Fenster wieder still (60 s).
- **V4 (Stromsparen, Option A):** Nach jedem erkannten Trinken oder Nachfüllen ist das Gerät
  **60 s still sichtbar** (kein Blinken, Symbol fest blau), damit die App den neuen Stand abholen
  kann. Läuft schon ein Fenster, wird es höchstens verlängert.
- **V4:** Ist kein Fenster offen und kein Handy verbunden, schaltet der Sketch den ganzen
  BLE-Stack aus (`NimBLEDevice::deinit(true)`). Erst dann darf das CYD in den Light-Sleep.
- `bt suchen` startet die Suche neu, auch wenn sie schon läuft (der 2-min-Timer beginnt von vorn).

### Simulation (Wokwi, `HYDRO_BLE 0` = Standard)

Wokwi kann **kein Bluetooth** simulieren. Den Zustand stellt ihr im Seriellen Monitor ein:

| Befehl | Wirkung |
|---|---|
| `bt suchen` | Suche starten (sichtbar, weiß blinken, max. 2 min) |
| `bt verbunden` | so tun, als hätte sich ein Handy verbunden → 2× lila, Symbol blau. Geht nur, wenn gerade gesucht wird. |
| `bt getrennt` | Handy weg → wieder suchen |
| `bt aus` | Bluetooth aus, Symbol weg |

`status` zeigt am Ende z. B. `BT=suchen (noch 87 s) [simuliert]`.

### Echtes Gerät (`HYDRO_BLE 1`)

- Bibliothek **NimBLE-Arduino** (h2zero, getestet mit 2.5.1) im Library Manager installieren.
  Sie braucht viel weniger Flash als die eingebaute ESP32-BLE-Bibliothek (Bluedroid).
- Ganz oben im Sketch `#define HYDRO_BLE 1` setzen (für das CYD zusätzlich `HYDRO_CYD 1`).
- Das Gerät wirbt als **„HydroDesk“** (Name in der Scan-Antwort) mit einem eigenen Dienst:

  | | UUID | Eigenschaft | Inhalt |
  |---|---|---|---|
  | Dienst | `4f9a0001-6c1e-4b8e-9d6a-2b7c1e0a4d10` | – | HydroDesk |
  | Werte | `4f9a0002-6c1e-4b8e-9d6a-2b7c1e0a4d10` | lesen + notify | Text, z. B. `1250/2750 ml` (heute/Ziel) |

  Testen z. B. mit der App **nRF Connect**: „HydroDesk“ verbinden, Werte lesen, Notify
  einschalten, trinken → der neue Wert kommt (höchstens 1× pro Sekunde, `BT_NOTIFY_MS`).
- Verbinden und Trennen melden die NimBLE-**Callbacks** (`onConnect`/`onDisconnect`). Sie laufen
  in einer eigenen Task und setzen nur einen Merker. Ausgewertet wird er in `btVerwalten()` im
  `loop()`. Am Fensterende wird die Werbung (Advertising) gestoppt und (V4) der Stack beendet.
- **V4:** `bleStarten()` legt bei **jedem** Fenster Server, Dienst und Werbung neu an. Grund:
  Nach `deinit(false)` würde NimBLE 2.5.1 den GATT-Dienst nicht neu registrieren, darum
  `deinit(true)` und alles neu. **Auf Hardware testen** (Stromsparplan Test H7: 20× im Wechsel).
- `bt suchen` und `bt aus` gehen auch am echten Gerät, `bt verbunden`/`bt getrennt` nicht
  (das meldet das Handy selbst).
- **Speicher / Partition (V4):** Mit WLAN + NimBLE + Stromsparen ist das echte Gerät (CYD + BLE)
  **682 Byte zu groß** für die Standard-Partition „Default 4MB with spiffs (1.2MB APP)“ (100 %).
  Fürs echte Gerät ist darum **„Huge APP (3MB No OTA/1MB SPIFFS)“ Pflicht** (dann 41 %).
  Die Wokwi-Display-Variante mit BLE passt noch knapp (99 %). Partition wählen:
  - Arduino-IDE: *Werkzeuge → Partition Scheme → Huge APP (3MB No OTA/1MB SPIFFS)*
  - arduino-cli: `-b esp32:esp32:esp32:PartitionScheme=huge_app`
  - PlatformIO: `board_build.partitions = huge_app.csv`
  - Wer Updates über WLAN (OTA) behalten will: „Minimal SPIFFS (1.9MB APP with OTA)“ (`min_spiffs`).

  Zum Vergleich: Mit der eingebauten Bluedroid-BLE-Bibliothek ist schon ein kleiner Test (nur
  WLAN + BLE-Dienst) **1,62 MB groß (123 %)** und passt nicht in die Standard-Partition.
- WLAN und Bluetooth teilen sich am ESP32 **eine Antenne** (Coexistence). Das geht, beide werden
  aber etwas langsamer. Am echten Gerät testen!

## 7. Uhrzeit, WLAN und Tageswechsel

- Der ESP32 verbindet sich mit **„Wokwi-GUEST“** (kein Passwort, Kanal 6) und holt die Zeit von
  `pool.ntp.org`. Die Zeitzone ist `CET-1CEST,M3.5.0,M10.5.0/3`, also Deutschland mit
  automatischer Sommer-/Winterzeit.
- **V4: WLAN nur zum Abgleich.** Nach dem NTP-Empfang schaltet der Sketch das WLAN aus
  (`WiFi.disconnect(true)` + `WIFI_OFF`). Neuer Abgleich alle **6 h** (`WLAN_ABGLEICH_ALLE_MS`),
  solange noch nie NTP kam alle **30 min**, und per Befehl `sync`. Nach **20 s** ohne NTP gibt
  er auf (`WLAN_ABGLEICH_TIMEOUT_MS`). Beim Abgleich steht im Protokoll z. B.
  `[UHR] Abgleich: Abweichung 1.8 s in 6.0 h (Uhr ging nach)`. Mit `stromsparen 0` bleibt das
  WLAN wie in V3 dauerhaft an.
- Die Zugangsdaten stehen in der Simulation als Konstanten im Sketch. **Beim echten Gerät** gehören
  sie in eine Datei `secrets.h`, die **nicht** ins Git kommt (`.gitignore`):
  ```cpp
  // secrets.h
  #define WLAN_SSID_GEHEIM "MeinWLAN"
  #define WLAN_PASS_GEHEIM "geheim"
  ```
- **Ohne NTP:** Kommt nach ca. **10 s** keine Zeit, startet eine **Ersatzuhr um 12:00**. Das Datum
  ist dann der Tag, an dem der Sketch kompiliert wurde. Die Uhrzeit ist gelb, hinter dem Datum
  steht „(ohne NTP)“. Bis dahin zeigt das Display „--:--“. Kommt NTP später doch noch, wird die
  Uhr korrigiert.
- **Mitternacht:** Beim Datumswechsel setzt sich der Tageszähler **automatisch auf 0**. Der Befehl
  `reset` geht weiterhin.
- Nach einem Neustart am **selben Tag** zählt das Gerät mit dem gespeicherten Stand weiter
  (Preferences-Schlüssel `heuteMl`/`heuteTag`).

---

## 8. Bedienung in der Simulation

| Was | Wie |
|---|---|
| **Gewicht** ändern (Flasche abstellen / abheben) | Auf das **HX711-Bauteil** klicken → Schieberegler. 0,70 kg = 700 g. **0 kg = Flasche abgehoben.** |
| **Touch / Kalibrierung** | Große Tasten **„Leer“** und **„Voll“** auf dem Hauptbildschirm. Leere Flasche → **Leer** tippen (Gewicht ~1 s ruhig) → volle Flasche → **Voll**. Optional: **3 s** Langdruck oder Serial `kalib` öffnet den Kalibrier-Bildschirm (gleiche Tasten + „Fertig“). |
| **Kalibrier-Bildschirm** | Tasten „Leer“, „Voll“, „Fertig“. Fehler/Erfolg auf Deutsch auf dem Display. |
| **Wasser** simulieren | Schiebeschalter **NÄSSE** nach **rechts** = nass. Nach links = trocken, nach **5 s** trocken gibt das Gerät **von selbst** frei (kein Quittieren mehr). |
| **Akku** | Auf den Drehregler **AKKU** klicken und drehen: ganz links = 3,0 V, ganz rechts = 4,2 V. Wegen der LiPo-Tabelle (V4) liegen 0–20 % eng beieinander: 20 % ≈ 3,73 V ≈ 61 % aufgedreht, 10 % ≈ 3,69 V ≈ 57 %. Genauer Wert: `status` (`Akku=3.72 V, 18 %`). **Unter 3,30 V (≈ 25 % aufgedreht) schaltet das Gerät nach 60 s ab** (Kapitel 18). |
| **Display-Licht** (V4) | Hilfs-LED **LICHT**: hell = AKTIV, schwach = GEDIMMT, aus = RUHE (Display dann schwarz). Erste Berührung weckt nur. |
| **Befehle** | Im Seriellen Monitor eintippen + Enter (siehe Tabelle) |

**Serielle Befehle (115200 Baud):**

| Befehl | Wirkung |
|---|---|
| `status` | eine Zeile mit allen Werten (inkl. Soll-Plan, Erinnerungen, leer/voll/Kapazität) |
| `reset` | Tageszähler auf 0 (auch Erinnerungszähler) |
| `gewicht 75` | Körpergewicht in kg (30–250, Komma oder Punkt), Ziel neu, wird gespeichert |
| `groesse 180` | Körpergröße in cm (120–230), Ziel neu, wird gespeichert |
| `zeit 23:59` | Uhr von Hand stellen, z. B. um den Mitternachts-Reset / die Ruhezeit zu testen |
| `kalib` | Service-Modus Flaschen-Kalibrierung öffnen |
| `leer` | leere Flasche bestätigen (speichert Leergewicht) |
| `voll` | volle Flasche bestätigen (Kapazität = voll − leer) |
| `bt suchen` | Bluetooth-Suche starten (weiß blinken, max. 2 min), siehe Abschnitt 6 |
| `bt verbunden` | (nur Simulation) Handy verbunden → 2× lila, Symbol fest blau |
| `bt getrennt` | (nur Simulation) Handy getrennt → wieder suchen |
| `bt aus` | Bluetooth aus, Symbol verschwindet |
| `sync` | (V4) Uhr-Abgleich: WLAN an, NTP holen, Abweichung protokollieren, WLAN aus |
| `stromsparen 0` / `stromsparen 1` | (V4) Stromsparen aus (wie Version 3) / wieder an; nicht gespeichert |
| `hilfe` | Befehlsliste |

**Erinnerung in Wokwi:** Mit `WOKWI_DEMO_ERINNERUNG 1` sind Pause **90 s** und Mindestabstand
**60 s** (echt: 75 min / 90 min). Zusätzlich müsst ihr **hinter dem Plan** liegen (z. B. mittags
mit 0 ml) und außerhalb 22:00–07:00. Nach ≥100 ml im Fenster startet die Pause.

### Simulation auf wokwi.com starten

1. **https://wokwi.com/projects/new/esp32** öffnen.
2. Tab `sketch.ino`: alles ersetzen durch unsere `sketch.ino`.
3. Tab `diagram.json`: alles ersetzen durch unsere `diagram.json` (LED-Streifen jetzt mit 26 Pixeln).
4. **Library Manager** → „+“ → `Adafruit GFX Library`, `Adafruit ILI9341`, `Adafruit FT6206 Library`,
   `Adafruit BusIO`, `Adafruit NeoPixel`, `HX711` (wie `libraries.txt`). WLAN und Zeit sind im
   ESP32-Kern enthalten, dafür braucht ihr **keine** weitere Bibliothek. NimBLE-Arduino braucht
   Wokwi **nicht** (nur das echte Gerät mit `HYDRO_BLE 1`).
5. ▶ drücken. Der Waagen-Regler muss beim Start auf **0** stehen (automatische Tara).
6. Im Seriellen Monitor erscheint u. a.:
   ```
   === HydroDesk Base – Wokwi-Simulation (V4) ===
   [+00:00] [ZIEL] Profil 70.0 kg, 175 cm -> KOF 1.845 m² -> Tagesziel 2750 ml (Richtwert)
   [+00:00] [UHR] Abgleich: WLAN an (Start), höchstens 20 s
   [+00:00] [UHR] Verbinde mit WLAN "Wokwi-GUEST" ...
   [+00:00] [BT] Bluetooth wird nur simuliert (Befehle: bt suchen | bt verbunden | bt getrennt | bt aus)
   [+00:00] [BT] aus -> suchen  (Start, max. 120 s)
   [+00:00] [ENERGIE] Stromsparen an: CPU 80 MHz, dimmen nach 30 s, Display aus nach 2 min (nachts 15 s), Wokwi: ohne echten Schlaf
   [+00:00] [LED] weiß blinken (Bluetooth sucht)
   [+00:00] [LAST] LED-Strom AN (weiß blinken (Bluetooth sucht))
   [+00:02] [UHR] WLAN verbunden
   [+00:02] [UHR] NTP-Anfrage an pool.ntp.org
   [14:23:05] [UHR] NTP-Zeit empfangen
   [14:23:05] [UHR] WLAN aus (Uhr abgeglichen)
   ```

---

## 9. Testfälle (zum Abhaken und für die Doku)

Startzustand: Simulation neu gestartet, Waage 0 kg, NÄSSE links, AKKU-Regler wie geladen
(Stellung 900 von 1023 = 4,06 V, seit V4 mit der LiPo-Tabelle **83 %**).

> **Seit V4 (Stromsparen):** Nach 30 s ohne Aktivität wird das Display gedimmt, nach 2 min
> schwarz. Die **erste Berührung weckt nur**, erst die zweite zählt als Taste. Wer T1–T36 ohne
> diese Pausen durchgehen will, gibt vorher `stromsparen 0` ein (Verhalten wie V3). Die neuen
> Stromspar-Tests stehen in Kapitel 18 (S1–S14).

> **Wichtig seit V3:** Nach dem Start sucht Bluetooth 2 min lang und die LEDs blinken weiß. Das
> Weiß verdeckt Blau, Grün und das Fehler-Rot. Für **T1–T24** deshalb zuerst `bt aus` eingeben
> (oder 2 min warten). Die Bluetooth-Tests stehen in **T25–T36**.

| Nr. | Aktion | Erwartet (Display / LEDs / Serieller Monitor) |
|---|---|---|
| T1 | Start abwarten | `Tagesziel 2750 ml`, `WLAN verbunden`, `NTP-Zeit empfangen`, oben links echte Uhrzeit (weiß) + Datum. LEDs **aus**. |
| T2 | (ohne Internet) 10 s warten | `keine NTP-Zeit nach 10 s -> Ersatzuhr ab 12:00`, Uhrzeit **gelb**, „(ohne NTP)“ |
| T3 | `gewicht 80`, dann `groesse 180` | `Tagesziel 3000 ml`, Anzeige „von 3.000 ml“. Danach `gewicht 70` + `groesse 175` → 2750 |
| T4 | Waage **0,73 kg** | `Flasche steht`, Anzeige „Flasche: 580 ml“, „Leer 150 g (Schätzwert)“ |
| T5 | Waage 0, dann **0,53 kg** | `+200 ml getrunken`, „200 ml“, „Zuletzt getrunken: vor 0 s“ |
| T6 | Waage 0 → 0,33 → 0 → **0,25 kg** | insgesamt ca. 480 ml getrunken (±2 g Auflösung der Wokwi-Waage) |
| T7 | Waage 0, dann **0,78 kg** (nachgefüllt) | `Nachgefüllt ... zählt nicht`, `Leergewicht gelernt: 250 g`, „Flasche: 530 ml“, „(gelernt)“ |
| T8 | Waage 0, dann **0,24 kg** | `Flasche leichter als Leergewicht -> Leergewicht = 240 g` |
| T9 | `bt aus`, Uhr z. B. 12:00, 0 ml, **>90 s** warten (Demo-Pause/Abstand) | `-> ERINNERUNG` (hinter Plan), LEDs **blau**, Status „Zeit zu trinken!“ |
| T10 | ≥100 ml trinken (z. B. zwei Schlucke ≥40 ml) | Pause startet, `ERINNERUNG -> MESSEN`, LEDs aus; für ~90 s (Demo) keine neue Erinnerung |
| T10b | nur ~30 ml trinken während Erinnerung | zählt zum Tag, **keine** Pause; Erinnerung endet trotzdem |
| T11 | `gewicht 30` + `groesse 120` (Ziel 1500) und trinken, bis Ziel erreicht | `-> ZIEL_ERREICHT`, LEDs **grün 10 s, dann aus**, grün „Ziel erreicht ✓“, Balken grün |
| T12 | Waage 0, **> 60 s warten**, dann **1,10 kg** | `andere Flasche, Leergewicht zurück auf 150 g`, nichts gezählt |
| T13 | NÄSSE **rechts** | sofort `NAESSE_SPERRE`, LED „LAST“ aus, LEDs **dunkel** (V4: Streifen ohne Strom, kein Bernstein mehr), rotes Vollbild. Langdruck tut nichts. |
| T14 | NÄSSE **links** | „Freigabe in 5 s ...“, nach 5 s automatisch `-> IDLE`, LEDs aus. V4: `[LAST] wieder freigegeben (5 s trocken) - Strom nur, wenn die LEDs leuchten` (LAST bleibt aus, bis etwas leuchtet); mit `stromsparen 0`: `[LAST] wieder AN` |
| T15 | AKKU auf **19 %** drehen (≈ 3,73 V, `status` zeigt den Wert) | `[AKKU] NIEDRIG ... -> LEDs 2x rot`: genau **2 rote Blitze**, dann aus. Akku-Anzeige **orange**, 5 s oranger Hinweis „Akku unter 20 %“ |
| T16 | AKKU bei 18–21 % hin und her | **keine** weiteren Blitze (Hysterese bis 22 %) |
| T17 | AKKU auf **9 %** | `KRITISCH ... -> LEDs 4x rot (650/650 ms)`: genau **4 rote Blitze** (langsamer Takt), dann aus. Akku **rot**, unten dauerhaft roter Balken **„Bitte laden“** |
| T18 | AKKU auf 11 %, dann 12 % | bei 11 % bleibt „Bitte laden“; ab 12 % verschwindet der Balken (ohne Blitzen) |
| T19 | 10 min unter 20 % lassen | Blinkmuster wiederholt sich (2× bzw. 4× unter 10 %) |
| T20 | AKKU auf 30 % | `wieder ok`, Akku-Anzeige grün |
| T21 | 1 s aufs Display (nicht auf Leer/Voll) drücken | unten „Kalib-Screen: noch 2 s“ |
| T22 | leere Flasche → Taste **Leer** → volle Flasche → Taste **Voll** (oder Serial `leer`/`voll` / 3 s → Kalib-Screen) | Leer/Voll gespeichert, „Flasche: x/y ml“, Status z. B. „Kapazität: 500 ml“; Fehler auf Display (z. B. „Zuerst Leer kalibrieren“) |
| T23 | etwas trinken, dann `zeit 23:59` und 1 min warten | um 00:00 `Tageszähler auf 0 (neuer Tag)`, Datum springt weiter |
| T24 | `status` | eine Zeile mit allen Werten |
| T25 | Simulation neu starten, nichts tun | `[BT] aus -> suchen  (Start, max. 120 s)`, Bluetooth-Symbol links neben dem Akku **blinkt weiß/blau**, LEDs **blinken weiß (gedimmt)** 500 ms an / 500 ms aus |
| T26 | `bt verbunden` | `suchen -> verbunden`, Symbol **fest blau mit 2 Punkten**, LEDs **genau 2× lila**, dann aus |
| T27 | `bt getrennt` | `verbunden -> suchen`, Symbol blinkt wieder, LEDs blinken wieder weiß |
| T28 | 2 min warten, ohne zu verbinden | `120 s kein Handy -> Suche beendet`, `suchen -> nicht verbunden`, Symbol **grau**, LEDs aus (oder blau, falls inzwischen die Erinnerung läuft) |
| T29 | `bt verbunden` (Suche ist beendet) | Meldung „Nicht sichtbar - erst "bt suchen" …“, nichts ändert sich |
| T30 | `bt suchen`, 1 min warten, nochmal `bt suchen`, `status` | `Suche neu gestartet`, `status` zeigt z. B. `BT=suchen (noch 118 s) [simuliert]` (Timer wieder fast 120 s) |
| T31 | während der Suche AKKU auf **19 %** | genau **2 rote Blitze ohne Weiß** dazwischen, danach wieder weiß blinken. AKKU zurück auf 88 %. |
| T32 | während der Suche AKKU auf **9 %**, sofort `bt verbunden` | erst **4× rot**, danach **2× lila**, dann aus. Unten „Bitte laden“. AKKU zurück auf 88 %. |
| T33 | `bt getrennt`, dann NÄSSE **rechts** | LEDs **durchgehend dunkel** (V4, kein Weiß). NÄSSE links: nach 5 s Freigabe, danach wieder weiß blinken |
| T34 | `bt aus` | `-> aus`, Symbol **verschwindet**, LEDs aus. `status` endet mit `BT=aus [simuliert]` |
| T35 | `hilfe` | zweite Zeile: `Bluetooth (simuliert):  bt suchen \| bt verbunden \| bt getrennt \| bt aus` |
| T36 | **nur echtes Gerät** (`HYDRO_BLE 1`): Handy-App nRF Connect, „HydroDesk“ verbinden, Werte lesen, Notify an, trinken, trennen | verbinden: 2× lila + Symbol blau. Werte `1250/2750 ml`, nach dem Trinken neuer Wert per Notify. Trennen: wieder weiß blinken. Nach 2 min ohne Handy: grau, „HydroDesk“ verschwindet aus der Liste. V4: Symbol antippen → wieder 2 min sichtbar; trinken → 60 s still sichtbar. |

---

## 10. Der Zustandsautomat

| Zustand | Bedeutung | LEDs |
|---|---|---|
| `IDLE` | Keine Flasche auf dem Pad (oder gerade abgehoben). Änderungen werden ignoriert. | aus |
| `MESSEN` | Flasche steht, Trinken wird gezählt. | aus |
| `ERINNERUNG` | Hinter Plan, Pause/Abstand ok, max. 6/Tag, nicht Ruhezeit, Ziel offen. | blau (Dauerlicht) |
| `ZIEL_ERREICHT` | Tagesziel erreicht, keine Erinnerungen mehr (zählt weiter). | 10 s grün, dann aus |
| `NAESSE_SPERRE` | Wasser erkannt: LED-Strom aus, Touch gesperrt, Display bleibt hell. | aus (ohne Strom) |
| `KALIBRIERUNG` | Service-Modus: leere → volle Flasche → Kapazität. Messung pausiert. | aus |

Akku-Warnung und Fehler sind **keine eigenen Zustände**. Auch der **Energie-Zustand** (V4:
AKTIV / GEDIMMT / RUHE, Kapitel 18) ist ein eigener kleiner Automat neben dem Haupt-Zustand. Sie werden zusätzlich angezeigt, weil
das Gerät dabei weiter messen soll. **Bluetooth** hat einen eigenen kleinen Automaten
(`btZustand`: aus / suchen / verbunden / nicht verbunden, siehe Abschnitt 6). Er läuft unabhängig
vom Haupt-Zustand weiter, auch während der Wasser-Sperre.

```mermaid
stateDiagram-v2
    [*] --> IDLE
    IDLE --> MESSEN : Flasche steht ruhig
    MESSEN --> IDLE : Flasche abgehoben
    IDLE --> ERINNERUNG : hinter Plan + Pause/Abstand ok
    MESSEN --> ERINNERUNG : hinter Plan + Pause/Abstand ok
    ERINNERUNG --> MESSEN : Schluck erkannt
    MESSEN --> ZIEL_ERREICHT : getrunken >= Ziel
    ZIEL_ERREICHT --> MESSEN : Ziel höher / neuer Tag
    IDLE --> KALIBRIERUNG : 3 s Langdruck
    MESSEN --> KALIBRIERUNG : 3 s Langdruck
    KALIBRIERUNG --> IDLE : Taste Fertig
    IDLE --> NAESSE_SPERRE : Wasser
    MESSEN --> NAESSE_SPERRE : Wasser
    ERINNERUNG --> NAESSE_SPERRE : Wasser
    ZIEL_ERREICHT --> NAESSE_SPERRE : Wasser
    KALIBRIERUNG --> NAESSE_SPERRE : Wasser
    NAESSE_SPERRE --> IDLE : 5 s trocken
```

Ablauf in `loop()` (Sicherheit zuerst):
`naesseLesen()` → `akkuLesen()` → `waageLesen()` → `uhrVerwalten()` → `btVerwalten()` → `touchAuswerten()` →
`zustandAktualisieren()` → `energieVerwalten()` (V4) → `ledsAktualisieren()` → `drawUI()` → `serielleBefehle()` →
`wlanVerwalten()` (V4) → auf dem CYD in RUHE `leichtSchlafen()`, sonst `delay(5)`.

---

## 11. Pin-Tabelle (V4: GPIO18 schaltet den LED-Strom, GPIO21 per PWM, GPIO36 als Weckquelle)

| Signal | Bauteil in Wokwi (Pin) | Wokwi-Pin (ESP32) | Vorschlag CYD-Pin | Bemerkung |
|---|---|---|---|---|
| Display SCK | Display `SCK` | GPIO14 | GPIO14 (fest verdrahtet) | gleich wie CYD |
| Display MOSI | Display `MOSI` | GPIO13 | GPIO13 (fest) | gleich wie CYD |
| Display MISO | Display `MISO` | GPIO12 | GPIO12 (fest) | gleich wie CYD |
| Display CS | Display `CS` | GPIO15 | GPIO15 (fest) | gleich wie CYD |
| Display D/C | Display `D/C` | GPIO2 | GPIO2 (fest) | gleich wie CYD |
| Display Reset | Display `RST` | GPIO4 | – (an EN, `TFT_RST = -1`) | am CYD ist GPIO4 die rote RGB-LED |
| Hintergrundlicht | Display `LED` + LED „LICHT“ | GPIO21 | GPIO21 (fest) | am CYD **belegt** (Backlight), obwohl auf P3 herausgeführt; V4: PWM (LEDC 5 kHz, 8 Bit) |
| Touch SDA | Display `SDA` | GPIO32 | – | nur Wokwi (FT6206 über I2C) |
| Touch SCL | Display `SCL` | GPIO33 | – | nur Wokwi |
| Touch (CYD) | – | – | CLK 25, MOSI 32, MISO 39, CS 33, IRQ 36 (fest) | XPT2046, eigener SPI-Bus; V4: IRQ (GPIO36) liest der Sketch selbst und nutzt ihn als Weckquelle |
| HX711 DT | HX711 `DT` | GPIO27 | **GPIO27** (Stecker CN1) | |
| HX711 SCK | HX711 `SCK` | GPIO22 | **GPIO22** (CN1 / P3) | |
| Akku-Spannung | Poti `SIG` | GPIO35 | **GPIO35** (P3) | nur Eingang, ADC1 (geht auch mit WLAN); echt über Spannungsteiler 2 × 10 kΩ |
| Nässe-Sensor DO | Schalter Mitte (`2`), rechts (`3`) an GND | GPIO19 | **GPIO19** (SD-Slot MISO) | LOW = nass; nur wenn SD-Karte nicht benutzt wird |
| WS2812 DIN | Streifen `DIN` | GPIO23 | **GPIO23** (SD-Slot MOSI) | nur ohne SD-Karte; COB-Streifen (26 LEDs) echt an **5 V**, **330–470 Ω in Reihe direkt am Streifen-DIN** |
| LED-Strom (FET) | LED „LAST“ (Anode) | GPIO18 | **GPIO18** (SD-Slot SCK) | HIGH = Streifen hat 5 V (über BC547B → AO3401A); kein Strapping-Pin, beim Reset hochohmig → Streifen aus; nur ohne SD-Karte |
| 3,3 V | HX711 VCC, Poti VCC, Streifen VDD | 3V3 | 3,3 V (CN1) | Streifen nur in Wokwi an 3,3 V, echt an 5 V |
| 5 V | Display VCC | VIN | 5 V (P1 VIN) | |
| GND | alle GND | GND.1 / GND.2 | GND | |
| Serieller Monitor | – | TX0/RX0 (GPIO1/3) | GPIO1/3 (P1) | |

**Hinweis CYD-Pins:** Frei herausgeführt sind am CYD nur GPIO22, GPIO27 (CN1) und GPIO35 (P3).
GPIO21 auf P3 ist das Display-Licht. Für die restlichen drei Signale (Nässe, WS2812, MOSFET)
nutzen wir die **SD-Karten-Pins 19/23/18** (z. B. mit einem microSD-„Sniffer“-Adapter im SD-Slot
oder an den Lötpunkten). GPIO5 (SD-CS) lassen wir frei, weil er beim Booten HIGH sein muss.
Alternativen: GPIO16/17 (RGB-LED-Pads, die LED leuchtet dann mit) oder RX/TX (dann kein Serieller Monitor).
In Wokwi sind die Pin-Nummern **gleich** gewählt wie am CYD (außer Display-RST und Touch).

---

## 12. Unterschiede zur echten Hardware (CYD ESP32-2432S028R)

| Thema | Simulation | Echt (CYD) |
|---|---|---|
| Touch | kapazitiv, FT6206 über **I2C** (`Adafruit_FT6206`), liefert direkt Pixel | **resistiv**, XPT2046 über eigenen **SPI-Bus**, liefert Rohwerte 0–4095 → muss **kalibriert** werden |
| Display-Bibliothek | `Adafruit_ILI9341` | meist `TFT_eSPI` (schneller, Pins in `User_Setup.h`) |
| Display-Reset | GPIO4 | an EN, also `TFT_RST = -1` |
| Waage | Rohwert 0–2100 für 0–5 kg (0,42 pro Gramm, ca. 2,4 g Auflösung), kein Rauschen | viel größere Rohwerte (Hunderte pro Gramm), Rauschen, Temperaturdrift → **Kalibrieren** (Service-Modus) |
| Nässe | Schiebeschalter | LM393-Modul: DO an GPIO19, Empfindlichkeit am Poti des Moduls einstellen |
| LED-Strom (V4) | LED „LAST“ | P-MOSFET **AO3401A** (High-Side in der 5-V-Leitung des Streifens), Treiber NPN **BC547B** (4,7 kΩ an der Basis, 47 kΩ Basis→GND), 10 kΩ Gate→Source |
| Display-Licht (V4) | LED „LICHT“ (PWM) + Display schwarz gezeichnet | PWM am Backlight-Transistor des CYD, in RUHE zusätzlich `DISPOFF`/`SLPIN` |
| Schlaf (V4) | kein echter Schlaf (gleicher Energie-Automat) | Light-Sleep in RUHE, Wecken: Timer bis zur nächsten Waagen-Messung (≤ 100 ms), GPIO36 LOW (Touch), GPIO19 LOW (Nässe) |
| Akku | Poti 0–4095 = 3,0–4,2 V | Spannungsteiler 2 × 10 kΩ an GPIO35, `analogReadMilliVolts()` × 2 (8× gemittelt); Prozent per LiPo-Tabelle |
| LED-Streifen | `wokwi-led-strip` mit 26 Pixeln, an 3,3 V, Strom wird nicht simuliert | COB-Streifen WS2812B (26 LEDs) an 5 V vom Pololu S13V10F5: voll weiß ca. 0,49 A, mit `LED_HELLIGKEIT` 60 höchstens ca. 0,12 A (max. 80 erlaubt); 330–470 Ω in DIN, 470–1000 µF am Streifen (Abschnitt 5) |
| Uhrzeit / Tageswechsel | WLAN „Wokwi-GUEST“ + NTP (im Browser meist nach wenigen Sekunden) | Heim-/Schul-WLAN aus `secrets.h` + NTP |
| Einstellungen | werden in `Preferences` (NVS) gespeichert, gehen beim Neustart der Simulation verloren | bleiben nach Stromausfall erhalten |
| Telegram | nur `[TELEGRAM-STUB]`-Text | WLAN + Bot (z. B. Bibliothek „UniversalTelegramBot“) in `telegramSenden()` |
| Bluetooth | nicht simulierbar → Befehle `bt suchen/verbunden/getrennt/aus` (`HYDRO_BLE 0`) | echtes BLE mit NimBLE-Arduino (`HYDRO_BLE 1`), Partition „Huge APP“ **Pflicht** (V4) |

---

## 13. Umstieg auf das CYD (später)

Das Programm ist so gebaut, dass sich nur **ein Block** ändert:
„HARDWARE-ABSTRAKTION DISPLAY + TOUCH“ mit `anzeigeInit()` und `readTouch()`.
Alles andere (Zustandsautomat, Waage, LEDs, Zeichnen) bleibt gleich, weil nur Zeichenfunktionen
benutzt werden, die **Adafruit_GFX und TFT_eSPI beide** kennen
(`fillScreen`, `fillRect`, `drawRect`, `fillRoundRect`, `drawRoundRect`, `drawLine`,
`drawFastHLine`, `setCursor`, `setTextSize`, `setTextColor`, `print`).

1. In der Arduino-IDE die Bibliotheken **TFT_eSPI** und **XPT2046_Touchscreen** installieren
   (dazu HX711 und Adafruit NeoPixel wie oben).
2. In `TFT_eSPI/User_Setup.h` für das CYD einstellen:
   ```cpp
   #define ILI9341_2_DRIVER
   #define TFT_WIDTH  240
   #define TFT_HEIGHT 320
   #define TFT_MISO 12
   #define TFT_MOSI 13
   #define TFT_SCLK 14
   #define TFT_CS   15
   #define TFT_DC    2
   #define TFT_RST  -1
   #define TFT_BL   21
   #define TFT_BACKLIGHT_ON HIGH
   #define USE_HSPI_PORT
   #define LOAD_GLCD
   #define SPI_FREQUENCY  55000000
   #define SPI_READ_FREQUENCY 20000000
   #define SPI_TOUCH_FREQUENCY 2500000
   ```
   (Manche CYD-Versionen mit zwei USB-Buchsen haben einen ST7789 statt ILI9341 → dort
   `ST7789_DRIVER` und ggf. `TFT_INVERSION_ON`.)
3. Im Sketch oben `#define HYDRO_CYD 1` setzen und als Board „ESP32 Dev Module“ wählen.
4. **Touch kalibrieren:** In `readTouch()` stehen `TOUCH_X_MIN/MAX`, `TOUCH_Y_MIN/MAX`
   (Startwerte 200/3700 und 240/3800). Die vier Ecken antippen, die Koordinaten im Seriellen Monitor
   (`[TOUCH] x=.. y=..`) ansehen und die Werte anpassen, bis die Tasten im Service-Modus stimmen.
   Evtl. `touch.setRotation(...)` ändern, wenn x/y vertauscht oder gespiegelt sind.
5. **Flasche kalibrieren:** 3 s auf das Display drücken (oder Serial `kalib`) → leere Flasche
   aufstellen → bestätigen → volle Flasche aufstellen → bestätigen → Kapazität wird gespeichert.
6. **WLAN:** Zugangsdaten in `secrets.h` (siehe Abschnitt 7), nicht in den Sketch.
7. **Bluetooth:** Bibliothek **NimBLE-Arduino** installieren, `#define HYDRO_BLE 1` setzen und als
   Partition **„Huge APP (3MB No OTA/1MB SPIFFS)“** wählen (Pflicht seit V4, siehe Abschnitt 6).
8. **Stromsparen (V4):** Light-Sleep ist mit `HYDRO_CYD 1` automatisch an (`HYDRO_LIGHTSLEEP`).
   CPU-Takt setzt der Sketch selbst auf 80 MHz. Erst die Hardware-Tests aus Kapitel 18 machen.

Die CYD-Variante und die BLE-Variante wurden **nur kompiliert** (siehe Abschnitt 16), nicht auf
echter Hardware getestet.

---

## 14. Einstellungen im Sketch (ganz oben)

| Konstante | Standard | Bedeutung |
|---|---|---|
| `KOERPERGEWICHT_KG` / `KOERPERGROESSE_CM` | 70 / 175 | Profil für das Tagesziel (Serial überschreibt) |
| `ML_PRO_M2`, `ZIEL_MIN_ML` / `ZIEL_MAX_ML` | 1500, 1500 / 3500 | Formel und Grenzen für das Tagesziel |
| `WOKWI_DEMO_ERINNERUNG` | 1 (Wokwi) | 1 = kurze Demo-Zeiten, 0 = Geräte-Zeiten (75 min / 90 min) |
| `ERINNERUNG_PAUSE_MS` | 90 s / 75 min | Pause nach ≥100 ml (keine Erinnerung/LED/Telegram) |
| `ERINNERUNG_MIN_ABSTAND_MS` | 60 s / 90 min | Mindestabstand zwischen Erinnerungen |
| `TRUNK_FENSTER_MS` | 20 s / 10 min | Fenster, in dem ≥100 ml die Pause auslösen |
| `TRUNK_RESET_MIN_ML` / `SCHLUCK_OHNE_PAUSE_ML` | 100 / 40 ml | Pause-Schwelle / Schluck ohne Pause |
| `ERINNERUNG_MAX_PRO_TAG` | 6 | höchstens so viele Erinnerungen pro Tag |
| `RUHE_START_STUNDE` / `RUHE_ENDE_STUNDE` | 22 / 7 | Ruhezeit ohne Erinnerungen |
| `WLAN_SSID` / `WLAN_PASS` / `WLAN_KANAL` | Wokwi-GUEST / „“ / 6 | WLAN (echt: `secrets.h`) |
| `ZEITZONE` / `NTP_SERVER` / `NTP_WARTEZEIT_MS` | CET/CEST / pool.ntp.org / 10 s | Uhrzeit, danach Ersatzuhr |
| `LEERGEWICHT_START_G` | 150 g | Startwert Leergewicht |
| `PAD_LEER_RESET_MS` / `ANDERE_FLASCHE_G` | 60 s / 250 g | Erkennung „andere Flasche“ |
| `TROCKEN_FREIGABE_MS` | 5 s | automatische Freigabe nach Wasser |
| `AKKU_WARN_PROZENT` / `AKKU_KRITISCH_PROZENT` / `AKKU_HYSTERESE_PROZENT` | 20 / 10 / 2 % | Akku-Schwellen |
| `AKKU_BLINK_WARN` / `AKKU_BLINK_KRITISCH` | 2 / 4 | Anzahl roter Blitze |
| `AKKU_BLINK_AN_MS` / `AKKU_BLINK_AUS_MS` | 300 / 300 ms | Blinktakt unter 20 % |
| `AKKU_BLINK_KRITISCH_AN_MS` / `AKKU_BLINK_KRITISCH_AUS_MS` | 650 / 650 ms | Blinktakt unter 10 % (langsamer) |
| `AKKU_WIEDERHOLUNG_MS` | 10 min | Blinkmuster wiederholen (0 = nie) |
| `AKKU_HINWEIS_MS` | 5 s | oranger Hinweis „Akku unter 20 %“ |
| `LED_ANZAHL` | 26 | LEDs im COB-Streifen (13 Segmente à 2 LEDs) |
| `LED_HELLIGKEIT` / `LED_GRUEN_MS` / `LED_ROT_MS` | 60 (höchstens 80) / 10 s / 5 s | LED-Streifen; über 80 bricht das Kompilieren ab (Strombudget) |
| `LANGDRUCK_MS` | 3 s | Langdruck für den Service-Modus |
| `HYDRO_BLE` | 0 | 0 = Bluetooth simuliert (Wokwi), 1 = echtes BLE (NimBLE-Arduino) |
| `BT_START_SUCHEN` | true | beim Einschalten gleich suchen (Demo) |
| `BT_SUCH_TIMEOUT_MS` | 2 min | so lange suchen, dann „nicht verbunden“ (Symbol grau, LEDs aus) |
| `BT_WEISS_AN_MS` / `BT_WEISS_AUS_MS` | 500 / 500 ms | weißes Such-Blinken |
| `BT_WEISS_WERT` | 90 | Helligkeit des Weiß je Farbkanal (0–255, gedimmt) |
| `BT_LILA_ANZAHL` / `BT_LILA_AN_MS` / `BT_LILA_AUS_MS` | 2 / 300 / 300 ms | lila Blinken beim Verbinden |
| `BT_NOTIFY_MS` | 1 s | echtes BLE: Werte höchstens 1× pro Sekunde senden |
| `BT_NAME` / `BT_SERVICE_UUID` / `BT_WERTE_UUID` | HydroDesk / … | Name und UUIDs des BLE-Dienstes |
| `WOKWI_FAKTOR` | 0.42 | Rohwert pro Gramm (Wokwi-HX711 „5kg“) |
| `FLASCHE_DA_G` / `FLASCHE_WEG_G` | 40 / 25 g | ab wann die Flasche als „steht“ / „abgehoben“ gilt |
| `STABIL_MS` / `STABIL_TOLERANZ_G` | 1500 ms / 6 g | wann das Gewicht als „ruhig“ gilt |
| `MIN_SCHLUCK_G` / `MIN_NACHFUELL_G` | 15 / 20 g | Mindeständerung für „getrunken“ / „nachgefüllt“ |
| `TOUCH_SPIEGELN` | true | Touch-Koordinaten spiegeln (nur Wokwi) |
| `STROMSPAREN` | 1 | V4: 1 = Stromsparen, 0 = wie Version 3 (auch per Serial `stromsparen 0/1`) |
| `ANZEIGE_DIMMEN_NACH_MS` / `ANZEIGE_AUS_NACH_MS` / `ANZEIGE_AUS_NACH_MS_NACHT` | 30 s / 2 min / 15 s | Display gedimmt / aus / nachts (22–7 Uhr) aus |
| `LCD_HELL` / `LCD_GEDIMMT` | 255 / 40 | PWM-Wert des Display-Lichts (0–255) |
| `LCD_PWM_FREQ_HZ` / `LCD_PWM_BITS` | 5000 / 8 | LEDC an GPIO21 |
| `RUHE_WECKTAKT_MS` | 100 ms | Waage 10×/s, Light-Sleep höchstens bis zur nächsten Messung |
| `CPU_MHZ` | 80 | CPU-Takt mit Stromsparen (sonst 240) |
| `WLAN_ABGLEICH_ALLE_MS` / `WLAN_ABGLEICH_OHNE_NTP_MS` / `WLAN_ABGLEICH_TIMEOUT_MS` | 6 h / 30 min / 20 s | Uhr-Abgleich per WLAN |
| `BT_SYNC_FENSTER_MS` | 60 s | stilles Bluetooth-Fenster nach Trinken/Nachfüllen |
| `LED_ERINNERUNG_HELL_MS` / `LED_HELLIGKEIT_SPAR` | 2 min / 15 | Erinnerung voll blau, danach Sparblau |
| `LED_STROM_EINSCHWING_MS` | 10 ms | nach dem Einschalten des LED-Stroms warten, dann Farbe senden |
| `AKKU_TABELLE_V` / `AKKU_TABELLE_P` | 21 Stützstellen | LiPo-Kurve (typisch, Kapitel 18), nach der Entlademessung ersetzen |
| `AKKU_ABSCHALT_V` / `AKKU_ABSCHALT_MS` | 3,30 V / 60 s | Schutz: so lange darunter → Meldung → Tiefschlaf |
| `AKKU_LEER_MELDUNG_MS` / `AKKU_LEER_SCHLAF_MIN` / `AKKU_WIEDERANLAUF_V` | 10 s / 15 min / 3,60 V | Meldung, Prüfabstand im Tiefschlaf, Spannung für den Neustart |
| `RUHE_PINS_HALTEN` / `TOUCH_IRQ_NUTZEN` | true / true | CYD: Pins 18/21/22/23 im Light-Sleep halten / GPIO36 als Touch-Hinweis und Weckquelle |

---

## 15. Grenzen / Problemlösung

- **Andere Flasche (Regel 3) ist eine Schätzung:** Trinkt oder füllt jemand mehr als 250 g
  nach, während die Flasche länger als 60 s weg ist, hält das Gerät das für eine **andere
  Flasche**. Der Schluck wird dann **nicht** gezählt, das Leergewicht wird neu gelernt.
  Kleinere Änderungen nach langer Pause zählen normal.
- **Leergewicht vor dem ersten Nachfüllen** ist nur ein Schätzwert (150 g). Der angezeigte
  Flascheninhalt kann dann um bis zu ±250 g danebenliegen. Die **getrunkene Menge** stimmt
  trotzdem, weil sie nur aus Differenzen berechnet wird.
- Wird die Flasche nie ganz leer getrunken, ist das gelernte Leergewicht etwas zu hoch
  (Rest in der Flasche). Es wird kleiner, sobald einmal weniger drin ist.
- **Ersatzuhr:** Ohne Internet stimmt die Uhrzeit erst nach `zeit HH:MM`. Das Datum ist der
  Kompiliertag. `zeit` wird von der nächsten NTP-Meldung (SNTP-Intervall ca. 1 h) wieder
  überschrieben.
- Wechselt das Datum zwischen Ersatzuhr und später ankommender NTP-Zeit, wird der Zähler dabei
  **nicht** zurückgesetzt (nur echte Mitternacht setzt zurück).
- **Akku in Wokwi:** Das Poti liefert 3,0–4,2 V, die Prozentzahl kommt (V4) aus der LiPo-Tabelle.
  Die Tabelle ist eine **typische** Kurve aus der Literatur, nicht am eigenen Akku gemessen. Unter
  Last liegt die Spannung niedriger als in Ruhe → die Anzeige ist am echten Gerät nur grob. Die
  Hysterese von 2 % verhindert Flackern bei ADC-Rauschen.
- **Poti ganz links (< 3,30 V) in Wokwi:** nach 60 s „Akku leer“, 10 s Meldung, dann Tiefschlaf
  (15 min). Das ist gewollt (Akku-Schutz). Simulation neu starten oder Poti vorher hochdrehen.
- **Display in Wokwi „hängt schwarz“:** Das ist RUHE (V4). Einmal tippen weckt. Zum Arbeiten ohne
  Pausen: `stromsparen 0`.
- **Einstellungen (NVS)** wie Profil, Leergewicht, Faktor und Tageszähler gehen beim Neustart der
  Simulation auf wokwi.com verloren. Am echten Gerät bleiben sie erhalten.
- Wokwi-Waage: 0,42 Rohwert pro Gramm, also ca. 2,4 g Auflösung. 730 g können als 731 g angezeigt
  werden.
- **Touch reagiert im Service-Modus falsch:** `TOUCH_SPIEGELN = false` setzen. Koordinaten stehen
  im Monitor (`[TOUCH] x=.. y=..`).
- **„HX711.h not found“:** Bibliothek `HX711` im Library Manager hinzufügen (funktioniert mit
  Rob Tillaart „HX711“ und bogde „HX711 Arduino Library“).
- **„Gewicht negativ: Kalibrierung!“:** Waage auf 0, Service-Modus (3 s drücken) → „1. Pad leer: Tara“.
- Das erste Kompilieren dauert durch WLAN länger (ca. 1 min). Das Display baut sich in der
  Simulation langsamer auf als in echt.
- **Bluetooth in Wokwi:** wird nur über die `bt`-Befehle simuliert. Ob ein echtes Handy sich
  verbindet, Notify ankommt und WLAN + BLE gleichzeitig stabil laufen, kann nur das echte Gerät
  zeigen (Test T36).
- **„NimBLEDevice.h not found“** (nur mit `HYDRO_BLE 1`): Bibliothek „NimBLE-Arduino“ installieren.
  Für Wokwi (`HYDRO_BLE 0`) wird sie **nicht** gebraucht.
- **„Sketch too big“** mit `HYDRO_BLE 1`: Partition „Huge APP“ wählen (Abschnitt 6). Seit V4 ist
  das für CYD + BLE Pflicht.
- Falls `wokwi-led-strip` fehlt: in `diagram.json` durch `wokwi-led-ring` ersetzen (`VDD`→`VCC`,
  `VSS`→`GND`, `pixels` bleibt 26, `pixelSize` weglassen).

---

## 16. Nachweis: Kompilieren und PC-Test (Stand 09.10.2026, Version 4)

`arduino-cli 1.5.1`, Kern `esp32:esp32 3.3.12`, Board `esp32:esp32:esp32`, `--warnings all`:

```
Sketch uses 1044610 bytes (79%) of program storage space. Maximum is 1310720 bytes.
Global variables use 50780 bytes (15%) of dynamic memory, leaving 276900 bytes for local variables. Maximum is 327680 bytes.
```

**0 Fehler, 0 Warnungen** (Wokwi-Build, `HYDRO_BLE 0`, `STROMSPAREN 1`).

| Variante | Partition | Flash | RAM (global) | Ergebnis |
|---|---|---|---|---|
| Wokwi (Standard) | Default (1,25 MB App) | 1 044 610 B = **79 %** | 50 780 B (15 %) | ok |
| CYD (`HYDRO_CYD=1`, mit Light-Sleep) | Default | 1 057 638 B = **80 %** | 50 108 B (15 %) | ok |
| CYD + BLE (`HYDRO_CYD=1`, `HYDRO_BLE=1`) | Default | 1 311 402 B = **100 %** | 60 256 B (18 %) | **zu groß (682 B)** → Huge APP nehmen |
| CYD + BLE = **echtes Gerät** | **Huge APP** (3 MB App) | 1 311 402 B = **41 %** | 60 256 B (18 %) | ok |
| Wokwi-Display + BLE (`HYDRO_BLE=1`) | Default | 1 298 578 B = **99 %** | 60 928 B (18 %) | ok (knapp) |
| Wokwi-Display + BLE | **Huge APP** | 1 298 578 B = **41 %** | 60 928 B (18 %) | ok |

Gegenüber V3 (CYD + BLE 1 275 243 B) ist das Programm ca. 36 KB größer: Stromspar-Code im Sketch
(ca. 16 KB), LEDC-Treiber für das Display-Licht (ca. 7 KB), Light-Sleep/GPIO-Wecken
(ca. 10 KB), Rest ADC/HAL. Darum ist **„Huge APP“ für das echte Gerät jetzt Pflicht**.

Die BLE-Varianten nutzen NimBLE-Arduino 2.5.1. Sketch und NimBLE kompilieren ohne Warnungen. Bibliotheken: Adafruit GFX 1.12.6, Adafruit ILI9341 1.6.4, Adafruit FT6206 1.1.1,
Adafruit BusIO 1.17.4, Adafruit NeoPixel 1.15.5, HX711 (Rob Tillaart) 0.6.5. WiFi, Preferences,
SNTP, LEDC und Sleep gehören zum ESP32-Kern.

CYD-Variante (`HYDRO_CYD=1`, TFT_eSPI 2.5.43 + XPT2046_Touchscreen 1.4): kompiliert, keine Warnung
aus dem Sketch. Die einzige Meldung `TOUCH_CS pin not defined` kommt aus der unveränderten
`User_Setup.h` von TFT_eSPI (wir nutzen für den Touch die XPT2046-Bibliothek, nicht TFT_eSPI). Sie
verschwindet mit der CYD-`User_Setup.h` aus Abschnitt 13.

**PC-Logiktest (09.10.2026, Version 4):** Der Sketch wird auf dem PC mit nachgebauten Bauteilen
(Stubs) übersetzt, die Zeit wird simuliert (Ordner `wokwi_tools/logiktest_v4` im Arbeitsordner).

- **Teil 1 – Regression V3** (übersetzt mit `STROMSPAREN 0`): Zielformel, Leergewicht-Regeln 1–3,
  NTP vs. Ersatzuhr, Erinnerung blau, Ziel grün 10 s, Wasser (Streifen ohne Strom) + Freigabe nach
  5 s, Akku 2×/4× rot inkl. Hysterese, „Bitte laden“, 10-min-Wiederholung, Langdruck, Kalibrierung,
  Mitternacht, alle Bluetooth-Fälle. Ergebnis: **85 von 85 Prüfungen OK**.
  Angepasst gegenüber V3 (nicht die Logik, nur der Test): ADC-Werte für die LiPo-Tabelle,
  4× rot dauert 5,2 s (650/650 ms), Erinnerung erst nach der 90-s-Demo-Pause, Nässe ohne Bernstein.
- **Teil 2 – Stromsparen E1–E18** (Sketch wie ausgeliefert): Start (80 MHz, LED-Strom aus),
  Uhr-Abgleich + WLAN aus, Dimmen nach 30 s / RUHE nach 2 min / Bildschirm schwarz, Weck-Berührung
  ohne Tastenwirkung, BT-Symbol antippen (auch nach `bt aus`), Finger liegt auf, stilles
  Sync-Fenster ohne Blinken, Trennen im stillen Fenster, Erinnerung → Sparblau → RUHE erlaubt,
  Abheben weckt, Nacht 15 s, Mitternacht in RUHE, Nässe/Kalibrierung halten wach, `sync` +
  Abweichung, 6-h-Abgleich + 20-s-Timeout, `stromsparen 0/1`, LiPo-Tabelle, kurzer Einbruch ohne
  Abschaltung, Abschaltung nach 60 s + 10 s, Pins im Tiefschlaf, Neustart erst ab 3,60 V.
  Ergebnis: **101 von 101 Prüfungen OK**.

Nicht im PC-Test prüfbar: echter Light-Sleep, GPIO-Wecken, Display-Schlaf, BLE-`deinit`/`init`
(nur kompiliert) → Hardware-Tests in Kapitel 18. Ein Lauf im echten Wokwi-Simulator (wokwi-cli)
war nicht möglich (kein Wokwi-Token). Bitte einmal auf wokwi.com mit T1–T36 und S1–S14 prüfen.

---

## 17. VS Code (optional)

Mit der Erweiterung „Wokwi Simulator“: Ordner `sketch` mit `sketch.ino`, daneben `diagram.json` und
`wokwi.toml`, dann `arduino-cli compile -b esp32:esp32:esp32 --output-dir build sketch` und
F1 → „Wokwi: Start Simulator“. Das WLAN „Wokwi-GUEST“ funktioniert auch in VS Code (über das
öffentliche Wokwi-Gateway), NTP also ebenfalls.

---

## 18. Stromsparen (neu in Version 4)

Grundlage ist der freigegebene **Stromsparplan** (`Stromsparplan_HydroDesk.md`, Maßnahmen M1–M9,
Hardware H1 + H2). Alle Zeiten sind benannte Konstanten (Abschnitt 14).

### 18.1 Energie-Automat

| Zustand | Display | Wann |
|---|---|---|
| `AKTIV` | Licht 255, wird gezeichnet | nach jeder Aktivität |
| `GEDIMMT` | Licht 40 (≈ 16 %), wird gezeichnet | 30 s ohne Aktivität (nachts entfällt die Stufe) |
| `RUHE` | Licht 0, nichts wird gezeichnet (Wokwi: schwarz; CYD: `DISPOFF` + `SLPIN`) | 2 min ohne Aktivität, nachts (22–7 Uhr) 15 s |

**Aktivität** (→ `AKTIV`): Berührung, Flasche abgehoben/abgestellt, Trinken/Nachfüllen, Wechsel
nach ERINNERUNG/ZIEL_ERREICHT/NAESSE_SPERRE/KALIBRIERUNG, Handy verbindet/trennt, erste
Akku-Warnung, serieller Befehl. Der Mitternachts-Reset und Wiederholungen der Akku-Warnung wecken
**nicht**.

**Bleibt AKTIV** (kein Dimmen): Nässe-Sperre, Kalibrierung, Finger liegt noch auf.
**Kein Schlaf** (CYD), solange: Nässe, Kalibrierung, Finger auf dem Display, ein Blinkmuster
(Akku rot, lila, Bluetooth weiß), ein Bluetooth-Fenster oder eine Verbindung, der BLE-Stack noch
läuft, ein WLAN-Abgleich läuft oder Zeichen im Seriellen Puffer warten.

**Weck-Berührung (M8):** Ist das Display gedimmt oder aus, weckt die erste Berührung nur. Sie zählt
weder als Taste (Leer/Voll/Fertig/BT-Symbol) noch als Langdruck, bis der Finger wieder weg ist.

### 18.2 Was sonst noch Strom spart

| Nr. | Maßnahme | Umsetzung im Sketch |
|---|---|---|
| M1 | Display-Licht per PWM | `ledcAttach(21, 5000, 8)` nach `tft.init()`, `hintergrundlichtSetzen()` |
| M2 | WLAN nur zum Abgleich | `wlanAbgleichStarten()` / `wlanVerwalten()` / `wlanAusschalten()` (Abschnitt 7) |
| M2b | Uhr-Abweichung ins Protokoll | `ntpVerarbeiten()`: `[UHR] Abgleich: Abweichung x s in y h` |
| M3 | Display-Schlaf in RUHE | CYD: `0x28` + `0x10` (5 ms), Wecken `0x11` + 120 ms + `0x29` |
| M4 | CPU 80 MHz | `setCpuFrequencyMhz(80)` in `setup()` |
| M5 | Light-Sleep in RUHE (nur CYD) | `leichtSchlafen()`: Timer bis zur nächsten Waagen-Messung (≤ 100 ms), Wecken auch über GPIO19 LOW (Nässe) und GPIO36 LOW (Touch, nur wenn der Pin vorher HIGH war). Vorher werden GPIO18/21/22/23 gehalten (`gpio_hold_en`), danach freigegeben. Die Waage misst weiter 10×/s. |
| M6 | Bluetooth nur in Fenstern | Start 2 min, Symbol antippen 2 min, 60 s still nach Trinken/Nachfüllen; danach `deinit(true)` (Abschnitt 6) |
| M7 | Sparblau | Erinnerung 2 min voll blau, dann Blauwert 64 (= Helligkeit 15 bei `LED_HELLIGKEIT` 60), Dauerlicht |
| M8 | Touch weckt nur | siehe oben |
| M9 | Akku-Tabelle + Schutz | siehe 18.3 |
| H1 | LED-Strom per FET | `ledStromSetzen()`: an = GPIO18 HIGH + 10 ms, aus = erst Schwarz senden, dann LOW. Strom nur, solange eine LED-Quelle aktiv ist (auch in Blinkpausen). Nässe = immer aus. |

**Nicht umgesetzt** (laut Plan optional/Priorität 3): M10 (Akku seltener messen), M11
(HX711 nachts drosseln), Bluetooth-Optionen B/C, UART-Wecken.

### 18.3 Akku: Prozent-Tabelle und Schutz

Prozent aus der **Ruhespannung** einer typischen LiPo-Zelle (lineare Interpolation dazwischen).
**Quelle:** https://voltagebasics.com/lithium-polymer-battery-voltage-chart/ – das ist eine
**typische Kurve**, nicht am eigenen Akku gemessen. Nach dem Entladetest (Stromsparplan, Test H5)
ersetzen.

| % | 0 | 5 | 10 | 15 | 20 | 25 | 30 | 35 | 40 | 45 | 50 |
|---|---|---|---|---|---|---|---|---|---|---|---|
| V | 3,27 | 3,61 | 3,69 | 3,71 | 3,73 | 3,75 | 3,77 | 3,79 | 3,80 | 3,82 | 3,84 |

| % | 55 | 60 | 65 | 70 | 75 | 80 | 85 | 90 | 95 | 100 |
|---|---|---|---|---|---|---|---|---|---|---|
| V | 3,85 | 3,87 | 3,91 | 3,95 | 3,98 | 4,02 | 4,08 | 4,11 | 4,15 | 4,20 |

**Echt (CYD):** Teiler 2 × 10 kΩ an GPIO35, 8× `analogReadMilliVolts()` gemittelt, × 2, leicht
geglättet (80 % alt / 20 % neu).

**Schutz:** Liegt die Spannung **60 s** ununterbrochen unter **3,30 V** (`AKKU_ABSCHALT_V`, Schätzwert),
dann: Telegram-Stub, LED-Strom aus, WLAN aus, BLE aus, Bildschirm „Akku leer – bitte laden“ für
10 s, Licht aus, Tiefschlaf mit **15-min-Timer**. GPIO18 (FET), GPIO23 (DIN) und GPIO21 (Licht)
bleiben dabei LOW gehalten. Nach jedem Timer-Wecken prüft `setup()` die Spannung: unter **3,60 V**
sofort wieder schlafen, sonst normal starten. Kurze Einbrüche (< 60 s) lösen nichts aus.
**Grenze:** Im Tiefschlaf laufen Pololu-Ruhestrom und CYD-Grundlast weiter. Wirklich „aus“ ist das
Gerät nur mit dem neuen **Ein/Aus-Schalter** (H2, `gehaeuse/ANLEITUNG.md`).

### 18.4 `stromsparen 0` (zum Vergleichen)

Schaltet zurück auf das Verhalten von Version 3: Display immer hell, kein Dimmen/RUHE/Schlaf, WLAN
dauerhaft an, BLE-Stack dauerhaft an (nur die Werbung endet nach 2 min), keine stillen Fenster,
kein Sparblau, CPU 240 MHz, LED-Strom dauerhaft an (außer bei Nässe).
**Bleibt auch mit `stromsparen 0` wie in V4:** Akku-Tabelle und -Schutz, BT-Symbol antippen,
Nässe ohne Bernstein (der Streifen hat dann keinen Strom). Die Einstellung wird nicht gespeichert;
dauerhaft: `#define STROMSPAREN 0`.

### 18.5 Testfälle Stromsparen (Wokwi, `WOKWI_DEMO_ERINNERUNG 1`)

| Nr. | Aktion | Erwartet |
|---|---|---|
| S1 | Start, 30 s nichts tun | `[ENERGIE] AKTIV -> GEDIMMT  (30 s ohne Aktivität)`, LED „LICHT“ deutlich dunkler |
| S2 | weitere 90 s warten | `-> RUHE  (120 s ohne Aktivität)`, Display **schwarz**, LICHT aus |
| S3 | in RUHE auf die Taste **Leer** tippen | `[TOUCH] ... (nur Wecken)`, Display wieder an, **keine** Kalibrier-Meldung, Leergewicht unverändert |
| S4 | in RUHE Flasche abheben (Waage 0), leichter zurückstellen | Display wird beim Abheben AKTIV, Schluck wird gezählt (wie immer) |
| S5 | Uhr 12:00 (hinter Plan), Erinnerung abwarten, nichts tun | Display AKTIV, LEDs **blau**; nach 2 min `Sparblau`, Display aus, Sparblau bleibt |
| S6 | in RUHE NÄSSE **rechts** | sofort NAESSE_SPERRE, LAST aus, Display hell; bleibt hell, solange nass |
| S7 | Start mit Wokwi-GUEST | `NTP-Zeit empfangen`, gleich danach `[UHR] WLAN aus (Uhr abgeglichen)` |
| S8 | `sync` | `Abgleich: WLAN an (Befehl sync)`, NTP, `Abgleich: Abweichung x s in y h`, `WLAN aus` |
| S9 | `zeit 23:00`, 15 s warten | ohne Dimmstufe direkt `-> RUHE  (15 s ohne Aktivität (Nacht))` |
| S10 | `zeit 23:59`, Display aus lassen | um 00:00 `Tageszähler auf 0`, Display bleibt aus |
| S11 | Flasche trinken (nach Ende der Start-Suche) | `suchen ... 60 s, still (ohne Blinken)`, Symbol **fest blau**, LEDs **kein** Weiß, LAST bleibt aus; nach 60 s `Sync-Fenster vorbei`, Symbol grau |
| S12 | Display wach: Bluetooth-Symbol antippen; dann `bt aus` und Symbol erneut antippen | jeweils `suchen (Bluetooth-Symbol angetippt, max. 120 s)`, LEDs blinken weiß |
| S13 | `stromsparen 0`, 3 min warten; `stromsparen 1` | kein Dimmen, LAST an, `status`: `WLAN=dauerhaft`, `CPU=240 MHz`; danach wieder 80 MHz, WLAN aus, dimmt nach 30 s |
| S14 | AKKU-Poti auf ca. 20 % Drehung (< 3,30 V), 70 s warten | nach 60 s „Akku leer – bitte laden“ (10 s), dann Tiefschlaf (Serieller Monitor still). Poti zurückdrehen, Simulation neu starten |

### 18.6 Tests auf der echten Hardware (noch offen, Messung nötig)

Aus dem Stromsparplan Kapitel 9.2 (H1–H8): Strom in AKTIV / GEDIMMT / RUHE / RUHE+BLE / Abgleich
messen (USB-Messgerät 5 V und Multimeter am Akku), Ruhestrom von FCOB-Streifen (mit und ohne FET),
HX711 und Nässe-Modul, 50× Touch-Wecken und 20× Trinken in RUHE (keine verpasste Menge, keine
Fehl-Taste), Entladetest für die echte Akku-Tabelle, Uhr-Drift über 24 h, 20× BLE `deinit`/`init`,
Pin-Pegel im Light-Sleep (GPIO18 bleibt HIGH, wenn die LEDs leuchten; DIN LOW), Abschaltspannung
3,30 V prüfen. Erst danach steht eine **gemessene** Laufzeit fest. Schätzung laut Plan mit H1:
**ca. 27–54 h** im 24-h-Tag.

---

## Dateien

| Datei | Inhalt |
|---|---|
| `sketch.ino` | Programm (Arduino, ESP32), Version 4 (Stromsparen), mit deutschen Kommentaren |
| `diagram.json` | Schaltung für Wokwi (LED-Streifen mit 26 Pixeln; V4: Hilfs-LED „LICHT“ an GPIO21 mit 220 Ω) |
| `libraries.txt` | Bibliotheksliste für den Wokwi Library Manager |
| `wokwi.toml` | nur für Wokwi in VS Code |
| `verdrahtung.png` | Verdrahtungsplan als Bild |
| `screen_mockup.png` | Entwurf des Hauptbildschirms (mit Bluetooth-Symbol „verbunden“) |
| `README.md` | diese Anleitung |

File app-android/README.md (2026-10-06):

# 📱 HydroDesk App (Android)

Begleit-App zum **HydroDesk Base**: Das ESP32-Gerät misst mit einer Wägezelle, wie viel du aus deiner
Flasche trinkst, und schickt den Tagesstand per **Bluetooth Low Energy (BLE)** ans Handy.
Die App speichert jeden Schluck, zeigt Fortschritt und Verlauf und synchronisiert alles mit **Supabase**
(Login + Cloud-Datenbank).

> Schulprojekt FI-AE · Kotlin · Jetpack Compose (Material 3) · MVVM · Room · WorkManager · Supabase

---

## Inhalt

1. [Was kann die App?](#1-was-kann-die-app)
2. [Architektur](#2-architektur)
3. [Projektstruktur](#3-projektstruktur)
4. [Einrichtung Schritt für Schritt](#4-einrichtung-schritt-für-schritt)
5. [Testen mit dem ESP32](#5-testen-mit-dem-esp32)
6. [Testen ohne Hardware: Demo-Modus](#6-testen-ohne-hardware-demo-modus)
7. [Admin: zentrale Verwaltung](#7-admin-zentrale-verwaltung)
8. [So funktioniert es (Erklärungen)](#8-so-funktioniert-es-erklärungen)
9. [Test-Checkliste](#9-test-checkliste)
10. [Fehlerbehebung](#10-fehlerbehebung)
11. [Versionen](#11-versionen)

---

## 1. Was kann die App?

| Bildschirm | Inhalt |
|---|---|
| **Anmelden / Registrieren** | E-Mail + Passwort (Supabase Auth). Die Sitzung bleibt gespeichert – nach dem Neustart ist man weiter angemeldet. Zusätzlich „Ohne Konto testen“ (nur lokal, ohne Supabase). |
| **Heute** | Große Anzeige *heute getrunken / Tagesziel* mit Fortschrittsring, „noch … ml“ bzw. „Ziel erreicht ✓“, Bluetooth-Status (**Suchen … / Verbunden / Getrennt**), Taste *Verbinden/Trennen*, letzter Schluck und Liste der heutigen Schlucke, Sync-Status. |
| **Verlauf** | Balkendiagramm der letzten 7 Tage (selbst gezeichnet mit Compose `Canvas`, gestrichelte Ziel-Linie) und Liste pro Tag (30 Tage) mit Summe, Anzahl Schlucke, Fortschrittsbalken. |
| **Profil** | Name, Gewicht (kg), Größe (cm) → **Tagesziel wird live berechnet** (gleiche Formel wie die Firmware). Demo-Modus-Schalter, „Jetzt synchronisieren“, Abmelden. |
| **Admin** (nur Rolle `admin`) | Alle Nutzer mit heutiger Trinkmenge und Ziel. |

**Tagesziel** (wie in `wokwi/sketch.ino`, Funktion `zielBerechnen()`):

```
Körperoberfläche (Mosteller)  KOF = √(cm × kg / 3600)
Tagesziel                    = KOF × 1500 ml, auf 50 ml gerundet, Grenzen 1500 … 3500 ml
Beispiel: 70 kg, 175 cm  →  KOF 1,845 m²  →  2767 ml  →  2750 ml
```

*Richtwert, keine medizinische Empfehlung.*

---

## 2. Architektur

Einfaches **MVVM** (Model – View – ViewModel) mit Repositories und „manueller Dependency Injection“
(`AppContainer` erzeugt alle Objekte genau einmal – kein Hilt nötig).

```mermaid
flowchart LR
    ESP["ESP32 HydroDesk<br/>BLE notify: 1250/2750 ml"] -- Bluetooth LE --> BLE[HydroBleManager]
    DEMO[DemoGeraet<br/>simuliert Werte] -. Demo-Modus .-> GM
    BLE --> GM[GeraeteManager]
    GM --> DR["DrinkRepository<br/>Schluck-Erkennung"]
    DR --> ROOM[("Room<br/>hydrodesk.db")]
    ROOM --> VM[ViewModels]
    VM --> UI["Compose UI<br/>Heute · Verlauf · Profil · Admin"]
    DR -- SyncWorker / WorkManager --> SB[("Supabase<br/>Postgres + RLS")]
    AUTH[AuthRepository] -- Login --> SB
    PR[ProfileRepository] -- profiles --> SB
    AR[AdminRepository] -- View user_today --> SB
```

**Datenfluss bei einem Schluck:**

```mermaid
sequenceDiagram
    participant G as HydroDesk (ESP32)
    participant B as HydroBleManager
    participant R as DrinkRepository
    participant DB as Room (Handy)
    participant W as SyncWorker
    participant S as Supabase
    G->>B: notify "1450/2750 ml"
    B->>R: DeviceReading(heute=1450)
    R->>R: 1450 − letzter Wert 1250 = +200 ml
    R->>DB: DrinkEntry(200 ml, synced=false)
    R->>W: Sync anstoßen
    W->>S: upsert drink_entries (sobald Internet da ist)
    W->>DB: synced = true
```

---

## 3. Projektstruktur

```
app-android/
├── README.md                     ← diese Anleitung
├── local.properties.example      ← Vorlage für Supabase-URL + Key
├── supabase/schema.sql           ← Tabellen, RLS, Trigger, Views (im SQL Editor ausführen)
├── build.gradle.kts, settings.gradle.kts, gradle/libs.versions.toml  ← Build + Versionen
├── gradlew, gradle/wrapper/      ← Gradle-Wrapper (Android Studio nutzt ihn automatisch)
└── app/
    ├── build.gradle.kts          ← liest local.properties → BuildConfig
    └── src/main/java/de/hydrodesk/app/
        ├── HydroDeskApp.kt       ← Application, erzeugt den AppContainer
        ├── AppContainer.kt       ← „manuelle DI“: alle Repositories an einer Stelle
        ├── MainActivity.kt
        ├── domain/               ← GoalCalculator (Tagesziel), Formatierung
        ├── ble/                  ← BLE-Verbindung, Parser, Demo-Gerät, Berechtigungen
        ├── data/local/           ← Room: DrinkEntry, DailySummary, DrinkDao, AppDatabase
        ├── data/remote/          ← Supabase-Client + DTOs
        ├── data/repository/      ← Auth-, Profile-, Drink-, Admin-Repository
        ├── data/settings/        ← kleine Einstellungen (SharedPreferences)
        ├── sync/SyncWorker.kt    ← Hochladen im Hintergrund (WorkManager)
        └── ui/                   ← Compose-Bildschirme + ViewModels (auth, today, history, profile, admin)
    └── src/test/                 ← Unit-Tests (Tagesziel, BLE-Parser)
```

---

## 4. Einrichtung Schritt für Schritt

### Voraussetzungen

* **Android Studio** in einer aktuellen Version (mindestens **Quail 4 | 2026.1.4**, empfohlen die neueste),
  Download: <https://developer.android.com/studio> – auf dem MacBook Air M2 die Version **„Mac with Apple chip“**.
  Ein JDK ist in Android Studio schon enthalten.
* Ein **echtes Android-Handy** (Android 8.0 oder neuer) mit USB-Kabel.
  ⚠️ Der Android-Emulator kann **kein Bluetooth LE** – dort nur der Demo-Modus.
* Ein kostenloses **Supabase**-Konto: <https://supabase.com>

### Schritt 1 – Supabase-Projekt anlegen

1. Auf <https://supabase.com> anmelden (z. B. mit GitHub) → **New project**.
2. Name z. B. `hydrodesk`, ein **Datenbank-Passwort** vergeben (gut aufheben), Region **Frankfurt (eu-central-1)**.
3. **Create new project** – nach ca. 1–2 Minuten ist das Projekt bereit.

### Schritt 2 – Datenbank-Schema einspielen

1. Im Projekt links **SQL Editor** öffnen → **New query**.
2. Den kompletten Inhalt von [`supabase/schema.sql`](supabase/schema.sql) hineinkopieren → **Run**.
3. Kontrolle: links **Table Editor** → es gibt die Tabellen `profiles` und `drink_entries`
   (beide mit „RLS enabled“) und die Views `daily_totals` und `user_today`.

Das Skript darf man gefahrlos mehrmals ausführen.

### Schritt 3 – E-Mail-Bestätigung (wichtig!)

Supabase verlangt standardmäßig, dass neue Nutzer ihre E-Mail über einen Link bestätigen.

* **Für das Schulprojekt / Tests einfacher:** *Authentication → Sign In / Providers → Email* →
  **„Confirm email“ ausschalten** → Save. Dann ist man nach dem Registrieren sofort angemeldet.
* **Lässt man es an:** Nach dem Registrieren zeigt die App „Bitte den Bestätigungslink in der E-Mail öffnen“.
  Link öffnen (die Seite danach darf ruhig „localhost“ anzeigen), dann in der App **anmelden**.
  Hinweis: Der kostenlose Supabase-Mailversand ist auf wenige Mails pro Stunde begrenzt.

### Schritt 4 – URL und Key in `local.properties` eintragen

1. In Supabase: **Project Settings → API Keys** (bzw. **Data API**):
   * **Project URL**, z. B. `https://abcdefghijkl.supabase.co`
   * **anon / public** Key (beginnt mit `eyJ…`) **oder** der neue **Publishable key** (`sb_publishable_…`) – beide funktionieren.
   * ⚠️ **Niemals** den `service_role`- bzw. *Secret*-Key in die App eintragen!
2. Im Ordner `app-android/` die Datei `local.properties.example` kopieren und `local.properties` nennen:

   ```bash
   cd app-android
   cp local.properties.example local.properties
   ```
3. `local.properties` öffnen und die Werte eintragen:

   ```properties
   SUPABASE_URL=https://abcdefghijkl.supabase.co
   SUPABASE_ANON_KEY=eyJhbGciOi...
   ```

`local.properties` steht in der `.gitignore` und landet **nicht** auf GitHub. Android Studio ergänzt dort
beim ersten Öffnen selbst die Zeile `sdk.dir=…` – die eigenen Zeilen bleiben erhalten.
Nach jeder Änderung an `local.properties` die App **neu bauen** (die Werte werden beim Bauen in `BuildConfig` geschrieben).

### Schritt 5 – Projekt in Android Studio öffnen

1. Android Studio starten → **Open** → den Ordner **`app-android`** auswählen (nicht den ganzen Repo-Ordner!).
2. Android Studio führt automatisch den **Gradle Sync** aus (beim ersten Mal einige Minuten, lädt Gradle und Bibliotheken).
3. Falls Android Studio fehlende SDK-Pakete meldet (z. B. *Android SDK Platform 37*): auf den Link
   **„Install missing …“** klicken.
4. Fehlerfrei? Unten in der Leiste steht „Gradle sync finished“.

### Schritt 6 – App auf dem Handy starten

1. Am Handy die **Entwickleroptionen** freischalten: *Einstellungen → Über das Telefon → 7× auf „Build-Nummer“ tippen*.
2. *Einstellungen → System → Entwickleroptionen →* **USB-Debugging** einschalten.
3. Handy per USB an den Mac, Abfrage „USB-Debugging zulassen?“ mit **Zulassen** bestätigen.
4. In Android Studio oben das Handy auswählen und auf ▶ **Run 'app'** klicken.
5. In der App **Registrieren** (Name, E-Mail, Passwort ≥ 6 Zeichen).
6. **Profil** öffnen: Gewicht und Größe eintragen → **Speichern** → das Tagesziel erscheint auf „Heute“.

Alternativ ohne Android Studio: `./gradlew assembleDebug` erzeugt `app/build/outputs/apk/debug/app-debug.apk`.

---

## 5. Testen mit dem ESP32

1. Firmware mit **echtem BLE** bauen: in `wokwi/sketch.ino` (bzw. der späteren PlatformIO-Firmware)
   `HYDRO_CYD 1` und `HYDRO_BLE 1`, Bibliothek **NimBLE-Arduino**, Partition **Huge APP**
   (Details: [`../firmware/README.md`](../firmware/README.md)).
2. ESP32 einschalten – er ist **2 Minuten lang sichtbar** (LEDs blinken weiß, BT-Symbol blinkt).
3. In der App auf **Heute → Verbinden**. Beim ersten Mal fragt Android nach der Berechtigung
   **„Geräte in der Nähe“** (Android 12+) bzw. **Standort** (Android 8–11) → erlauben.
   Bei Android 8–11 muss außerdem der **Standort (GPS) eingeschaltet** sein, sonst findet der Scan nichts.
4. Status wechselt **Suchen … → Verbinden … → Verbunden**, der ESP32 blinkt 2× lila.
5. Flasche anheben, trinken, zurückstellen → nach ca. 2 s erscheint der Schluck in der App.

**Technische Daten (müssen zur Firmware passen):**

| | Wert |
|---|---|
| Gerätename | `HydroDesk` |
| Dienst (Service) UUID | `4f9a0001-6c1e-4b8e-9d6a-2b7c1e0a4d10` |
| Characteristic UUID | `4f9a0002-6c1e-4b8e-9d6a-2b7c1e0a4d10` (read + notify) |
| Inhalt | Text `heute/Ziel ml`, z. B. `1250/2750 ml` – notify bei Änderung, höchstens 1× pro Sekunde |
| Ebenfalls verstanden | JSON `{"heute":1250,"ziel":2750,"akku":88}` (für eine mögliche spätere Firmware) |

Die App scannt nach der Dienst-UUID **oder** dem Namen. Wird nichts gefunden, versucht sie es alle 15 s
erneut; nach einer Trennung verbindet sie nach 3 s automatisch neu (solange man nicht „Trennen“ gedrückt hat).
Ist das 2-Minuten-Fenster des ESP32 abgelaufen: ESP32 kurz neu starten oder per Serial `bt suchen` senden.

---

## 6. Testen ohne Hardware: Demo-Modus

Für Vorführungen in der Schule oder im Emulator:

1. **Profil → Demo-Modus** einschalten.
2. Auf **Heute** steht „Verbunden (Demo)“. Alle 15–40 s wird zufällig ein Schluck (50–300 ml) simuliert,
   zusätzlich gibt es die Taste **„Schluck simulieren (+200 ml)“**.
3. Die Demo-Werte laufen durch **denselben Parser und dieselbe Schluck-Erkennung** wie echte BLE-Daten
   und werden mit Quelle `Demo` gespeichert und synchronisiert.

Ganz ohne Supabase: auf dem Login-Bildschirm **„Ohne Konto testen“** – dann werden die Daten nur
auf dem Handy gespeichert (kein Sync, kein Admin).

---

## 7. Admin: zentrale Verwaltung

**Alles verwalten im Supabase-Dashboard:**

* **Table Editor → `profiles`**: Nutzer, Körperdaten, Tagesziel, Rolle ansehen und ändern.
* **Table Editor → `drink_entries`**: alle Trink-Einträge ansehen, korrigieren, löschen.
* **Authentication → Users**: Konten anlegen, sperren, löschen, Passwort-Reset schicken
  (beim Löschen eines Kontos werden Profil und Einträge automatisch mitgelöscht – `on delete cascade`).
* Das Dashboard umgeht die Row Level Security – dort sieht man immer alles.

**Sich selbst zum Admin machen** (SQL Editor, E-Mail anpassen):

```sql
update public.profiles set role = 'admin' where email = 'deine@mail.de';
```

Danach in der App unter **Profil** (evtl. App neu starten) die Taste **„Admin: alle Nutzer anzeigen“** →
Liste aller Nutzer mit heutiger Trinkmenge. Zurück zum normalen Nutzer: `set role = 'user'`.

**Sicherheit (Row Level Security, siehe `schema.sql`):**

| Wer | `profiles` | `drink_entries` |
|---|---|---|
| nicht angemeldet (`anon`) | nichts | nichts |
| Nutzer | eigene Zeile lesen/anlegen/ändern | eigene Zeilen lesen/anlegen/ändern/löschen |
| Admin | **alle lesen**, eigene ändern | **alle lesen**, eigene ändern |
| Dashboard / SQL Editor | alles | alles |

* Die Funktion `is_admin()` ist `security definer` – sonst würde die Policy auf `profiles` beim Prüfen
  der Rolle wieder `profiles` lesen (Endlos-Rekursion).
* Ein Trigger verhindert, dass sich ein Nutzer selbst `role = 'admin'` setzt.
* Die Views `daily_totals` und `user_today` sind `security_invoker` – sie halten sich an dieselben Regeln.
* Das Schema wurde vor dem Commit mit PostgreSQL 17 getestet (Supabase-`auth` nachgebildet):
  Selbst-Beförderung geblockt, fremde Einträge geblockt, doppeltes Hochladen ignoriert, Admin sieht alle.

---

## 8. So funktioniert es (Erklärungen)

### Schluck-Erkennung

Das Gerät schickt immer nur den **Tagesstand** („heute 1450 ml“). Die App merkt sich den letzten Wert:

* **Wert steigt** (1250 → 1450): neuer Eintrag mit **+200 ml**.
* **Erster Wert des Tages / nach dem Verbinden:** Vergleich mit der Summe, die für dieses Gerät heute schon
  gespeichert ist. Was ohne Verbindung getrunken wurde, wird so **als ein Eintrag nachgetragen**.
* **Wert sinkt** (Gerät zurückgesetzt, z. B. Serial-Befehl `reset`): nur neuer Ausgangswert, kein Eintrag.
* Änderungen unter 5 ml werden ignoriert.

### Offline-first + Synchronisierung

1. Jeder Schluck wird **zuerst lokal** in Room gespeichert (`synced = false`) – funktioniert auch ohne Internet.
2. Danach wird der **SyncWorker** (WorkManager) angestoßen. Er läuft, **sobald Internet da ist**, lädt alle
   offenen Einträge hoch (`upsert` mit derselben UUID → keine Duplikate) und setzt `synced = true`.
3. Außerdem holt er die Einträge der letzten 30 Tage aus Supabase (z. B. nach einem Handywechsel).
4. Zusätzlich läuft der Abgleich stündlich im Hintergrund.

Auf „Heute“ zeigt ein ⟳ hinter einem Eintrag, dass er noch nicht hochgeladen ist.

### Geheimnisse

`SUPABASE_URL` und `SUPABASE_ANON_KEY` stehen nur in `local.properties` (nicht im Git) und werden beim Bauen
nach `BuildConfig` geschrieben (`app/build.gradle.kts`). Der anon-Key darf in einer App stehen –
geschützt werden die Daten durch die **Row Level Security**, nicht durch den Key.

---

## 9. Test-Checkliste

**Build**
- [ ] Projekt in Android Studio geöffnet, Gradle Sync ohne Fehler
- [ ] `./gradlew test` – Unit-Tests (Tagesziel, BLE-Parser) grün
- [ ] App startet auf dem Handy

**Login / Konto**
- [ ] Registrieren mit neuer E-Mail → angemeldet (bzw. Bestätigungs-Hinweis)
- [ ] In Supabase *Table Editor → profiles* gibt es die neue Zeile mit Name und E-Mail
- [ ] Falsches Passwort → Meldung „E-Mail oder Passwort ist falsch.“
- [ ] App schließen und neu öffnen → weiterhin angemeldet
- [ ] Abmelden → Login-Bildschirm

**Profil**
- [ ] 70 kg / 175 cm → Vorschau „Tagesziel: 2.750 ml“
- [ ] Speichern → Meldung, Ziel erscheint auf „Heute“, in Supabase `daily_goal_ml = 2750`
- [ ] Ungültige Werte (z. B. 20 kg) → Fehlermeldung

**Demo-Modus**
- [ ] Demo an → „Verbunden (Demo)“, „Schluck simulieren“ → +200 ml auf „Heute“
- [ ] Neuer Eintrag erscheint in Supabase `drink_entries` (Quelle `Demo`)
- [ ] Flugmodus an → Schluck simulieren → ⟳ beim Eintrag → Flugmodus aus → ⟳ verschwindet

**Bluetooth (echtes Gerät)**
- [ ] Erste Verbindung fragt nach Berechtigung; nach „Zulassen“ Status „Suchen …“
- [ ] Status „Verbunden“, „Gerät meldet: …“ zeigt den Text vom ESP32
- [ ] Trinken am Gerät → neuer Eintrag mit der richtigen Menge
- [ ] ESP32 ausschalten → „Getrennt“, wieder einschalten → automatisch „Verbunden“
- [ ] Bluetooth am Handy aus → „Bluetooth ist aus“, Taste „Bluetooth einschalten“ funktioniert
- [ ] Ohne Verbindung trinken, dann verbinden → Menge wird nachgetragen

**Verlauf**
- [ ] Balken für heute passt zur Anzeige auf „Heute“, Ziel-Linie sichtbar, grün bei erreichtem Ziel
- [ ] Liste zeigt Tage mit Summe und Anzahl

**Admin**
- [ ] Normaler Nutzer: keine Admin-Taste
- [ ] Nach `update profiles set role='admin' …` + App-Neustart: Admin-Taste, Liste zeigt alle Nutzer
- [ ] Zweites Konto sieht die Einträge des ersten **nicht**

---

## 10. Fehlerbehebung

| Problem | Lösung |
|---|---|
| „Supabase ist noch nicht eingerichtet“ | `local.properties` fehlt oder enthält noch die Platzhalter. Eintragen, dann **Build → Rebuild Project**. |
| „Keine Verbindung zum Server“ | Internet am Handy prüfen; URL in `local.properties` korrekt (mit `https://`)? |
| „E-Mail noch nicht bestätigt“ | Link in der Mail öffnen oder in Supabase „Confirm email“ ausschalten (Schritt 3). |
| Profil speichern: „nicht in Supabase“ | `schema.sql` ausgeführt? Fehlermeldung genau lesen (z. B. „relation profiles does not exist“). |
| Status bleibt „Suchen …“ | ESP32 erst nach dem Einschalten 2 min sichtbar → neu starten. Firmware mit `HYDRO_BLE 1` gebaut? Android 8–11: Standort einschalten. |
| „Keine Berechtigung“ | Taste „App-Einstellungen öffnen“ → Berechtigungen → „Geräte in der Nähe“ erlauben. |
| Gradle Sync: „requires a newer Android Studio“ | Android Studio aktualisieren (mind. Quail 4 / 2026.1.4). |
| Gradle Sync: SDK fehlt | Den angebotenen Link „Install missing SDK package(s)“ anklicken. |

Logs ansehen: Android Studio → **Logcat**, Filter `tag:HydroBle | tag:DrinkRepository`.

---

## 11. Versionen

Stand Oktober 2026 (jeweils aktuelle stabile Versionen, alle in `gradle/libs.versions.toml`):

| Komponente | Version |
|---|---|
| Android Gradle Plugin | 9.4.1 (Kotlin ist eingebaut) |
| Gradle (Wrapper) | 9.8.0 |
| Kotlin / Compose-Compiler | 2.4.20 |
| KSP (für Room) | 2.3.12 |
| Compose BOM | 2026.09.00 (Material 3 1.4.0) |
| Room | 2.8.5 |
| WorkManager | 2.12.0 |
| Navigation Compose | 2.10.2 |
| Lifecycle | 2.11.0 |
| supabase-kt (auth-kt, postgrest-kt) | 3.8.0 |
| Ktor Client (OkHttp) | 3.6.0 |
| kotlinx.serialization | 1.11.0 |
| compileSdk / targetSdk / minSdk | 37 / 37 / 26 (Android 8.0) |
| JDK | 17 (oder das in Android Studio enthaltene JDK) |

### Bekannte Grenzen / Ideen für später

* Die BLE-Verbindung lebt, solange die App läuft (kein Vordergrund-Dienst). Das ist unkritisch:
  Der ESP32 zählt selbst weiter, beim nächsten Verbinden werden fehlende ml nachgetragen.
* Das Tagesziel wird (noch) nicht ans Gerät übertragen – dafür bräuchte die Firmware eine
  beschreibbare Characteristic.
* Einträge können in der App nicht gelöscht werden (geht im Supabase-Dashboard).

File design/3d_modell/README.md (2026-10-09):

# HydroDesk Base – komplettes 3D-Modell

Das ganze Gerät als 3D-Modell: Gehäuse **und** Elektronik, Schrauben, Gummifüße, COB-LED-Streifen mit Diffusor-Leiste und Silikonmatte.
Maßstab 1:1 (180 × 100 × 25 mm, mit Gummifüßen 27,2 mm hoch, mit eingesteckter Abdeckkappe 101,2 mm tief; der Schieber des Ein/Aus-Schalters steht links 1,6 mm aus der Wand).

| Datei | Inhalt |
|---|---|
| `hydrodesk_komplett.glb` | Zusammengebautes Gerät mit Farben und Display-Bild. 22 einzeln benannte Teile (Abdeckkappe eingesteckt) |
| `hydrodesk_komplett.stl` | Dasselbe Gerät als ein einziges Netz ohne Farben, Einheit mm. Nur zum Anschauen |
| `hydrodesk_komplett.3mf` | Zusammengebautes Gerät, 22 Teile, Einheit mm, Farben pro Fläche |
| `hydrodesk_explosion.glb` | Explosionsansicht (Teile auseinandergezogen wie im Bild `design/visualisierung/hydrodesk_explosion.png`, Abdeckkappe nach hinten herausgezogen) |
| `hydrodesk_explosion.stl` | Explosionsansicht als ein Netz, Einheit mm |
| `vorschau_komplett.png` | Kontrollbild: die GLB-Datei neu importiert und gerendert |

**Teile (Objektnamen):** Unterschale, Deckel, Abdeckkappe_USB, Flaschenplatte, Silikonmatte, Display-Board, Akku, Pololu-5V-Wandler, TC4056,
FET-Platine, Ein-Aus-Schalter, Klemmkeile, LM393, Regensensor, Waegezelle, HX711, COB-LED-Streifen, Diffusor, Schrauben_M3, Schrauben_M4, Schrauben_M5, Gummifuesse.

## Öffnen

- **Mac:** `.glb` und `.stl` im Finder markieren und Leertaste drücken (Quick Look), oder mit **Vorschau** öffnen.
- **Browser:** <https://gltf-viewer.donmccurdy.com>, dann die `.glb`-Datei hineinziehen. Drehen geht mit der Maus.
- **Blender:** Datei → Importieren → glTF 2.0 (`.glb`) oder STL. Jedes Teil ist ein eigenes Objekt.
- `.3mf` öffnet z. B. in PrusaSlicer, Bambu Studio oder Windows 3D-Viewer.

## Wichtig

- Die **Elektronik ist vereinfacht** nachgebaut: richtige Größe, Lage und Farbe, aber keine echten Bauteil-CAD-Daten.
  Platinenfarben sind zur Unterscheidung gewählt.
- Diese Dateien sind **keine Druckdateien**. Zum 3D-Drucken nur `gehaeuse/stl/` verwenden
  (`base.stl`, `cover.stl`, `pad.stl`, `kappe_usb.stl`, `diffusor_led.stl`, `schalter_keile.stl`, dort schon richtig auf dem Druckbett ausgerichtet).

## Neu erzeugen

```bash
cd design/visualisierung/src
HD_NO_RENDER=1 HD_OUT=../../3d_modell/hydrodesk_komplett  blender -b -P export.py -- produkt   /tmp/x.png 1 10
HD_NO_RENDER=1 HD_OUT=../../3d_modell/hydrodesk_explosion blender -b -P export.py -- explosion /tmp/x.png 1 10
python3 make_3mf.py ../../3d_modell/hydrodesk_komplett.glb ../../3d_modell/hydrodesk_komplett.3mf
```

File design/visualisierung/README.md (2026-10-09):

# HydroDesk Base – Visualisierung

Gerenderte Bilder der HydroDesk Base, im Stil einer technischen Explosionszeichnung.
Alle Maße kommen direkt aus dem OpenSCAD-Modell `gehaeuse/hydrodesk_base.scad`.

| Datei | Inhalt |
|---|---|
| `hydrodesk_explosion.png` | Explosionsansicht von unten nach oben: Gummifüße, davor Diffusor-Leiste und COB-LED-Streifen (26 LEDs) nach vorne unten herausgezogen → Unterschale → Akku + 5-V-Wandler Pololu S13V10F5 → Wägezelle, HX711, Lader, FET-Platine (2× AO3401A), LM393, Regensensor, links der Ein/Aus-Schalter mit den 2 Klemmkeilen → Display-Board (etwas höher gezeichnet, damit alle Hinweislinien frei bleiben) mit der nach hinten herausgezogenen USB-Abdeckkappe → Flaschenplatte → Silikonmatte → Deckel |
| `hydrodesk_innen.png` | Innenansicht ohne Deckel und Platte. Alle Module mit Kabeln (auch FET-Platine und Ein/Aus-Schalter in der linken Wand), das Display-Board ist angehoben gezeichnet |
| `hydrodesk_teile.png` | Teileübersicht: alle 20 Teile (inkl. USB-Abdeckkappe, Diffusor-Leiste, Ein/Aus-Schalter und Klemmkeilen) maßstäblich auf einer Schneidematte (Raster 1 cm) mit nummerierter Legende |
| `hydrodesk_produkt.png` | Produktbild: geschlossenes Gerät, Display mit Tagesfortschritt, vorne eine gleichmäßig blau leuchtende Lichtlinie (COB-LED-Streifen hinter dem milchigen Diffusor, keine einzelnen Lichtpunkte), Flasche nur angedeutet |

## So entstehen die Bilder

1. **OpenSCAD** exportiert Unterschale, Deckel, Flaschenplatte, USB-Abdeckkappe, Diffusor-Leiste und die 2 Klemmkeile des Schalters als STL in Einbaulage (`src/w_*.scad`).
2. **Blender 4.5 (Cycles)** baut die Elektronik als vereinfachte 3D-Modelle in Originalgröße nach
   (`src/scene.py`), lädt die STL-Dateien und rendert jede Ansicht.
3. **Python/PIL** setzt die Bilder auf den Hintergrund und zeichnet die deutschen Beschriftungen
   mit Hinweislinien (`src/final.py`). Die Linien zeigen genau auf die 3D-Punkte der Bauteile.

Neu rendern (nach einer Änderung am Modell):

```bash
cd design/visualisierung/src
for p in base cover pad cap diff keil; do openscad -o stl/$p.stl w_$p.scad; done   # STL in Einbaulage
./render_all.sh            # braucht Blender 4.x mit Cycles (Pfad über BLENDER=... setzen)
```

Auflösung: 2560 × 1440 px, 128 Samples. Rendern dauert auf 8 CPU-Kernen ca. 15 Minuten.

Hinweis: Elektronik-Bauteile sind vereinfacht (richtige Größe, Lage und Farbe, aber keine echten Bauteil-CAD-Daten).
Die Farben der Platinen sind zur Unterscheidung gewählt, die echten Module können andere Farben haben.

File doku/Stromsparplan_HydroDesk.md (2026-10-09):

# HydroDesk Base – Stromsparplan (umgesetzt in Version 4)

Stand: 08.10.2026 · Grundlage: `wokwi/sketch.ino` (Version 3, identisch in `/workspace/HydroDesk/wokwi` und im Repo `hydrodesk-base/wokwi`), Arduino-ESP32-Kern 3.3.12, NimBLE-Arduino 2.5.1, XPT2046_Touchscreen 1.4, HX711 (Rob Tillaart) 0.6.5.

> **Status 09.10.2026: umgesetzt (V4).** Deine Entscheidung: Software-Stromsparmodus + H1 (LED-FET, High-Side) + H2 (Schiebeschalter). Firmware: Commit `9e66c64`, Gehäuse/Schaltung: Commit `71570e4`, Doku/Kosten: siehe Kapitel 11. Was gebaut wurde und **was noch gemessen werden muss**, steht in **Kapitel 11**. Die Kapitel 0–10 sind der ursprüngliche Plan (Stand 08.10.2026) und bleiben als Begründung stehen.
>
> **Hinweis zum Plan:** Alle Stromwerte ohne Quelle sind **Schätzungen**. Alle Stromwerte ohne Quelle sind **Schätzungen** und mit „(S)“ markiert. Werte mit Quelle sind mit [Nummer] belegt (Liste am Ende). Die echten Werte liefert erst die Messung am Gerät (Kapitel 9).

---

## 0. Kurzfassung

- **Heute** laufen Display (immer volle Helligkeit), WLAN (immer verbunden) und CPU (240 MHz, kein Schlaf) ununterbrochen. Neu und grob von unten gerechnet ergibt das **ca. 6 bis 12 h** Laufzeit (S).
  - Die früheren „3–4 h“ beruhten auf 0,25–0,35 A für das CYD. Das war der **Spitzenwert fürs Strombudget** des Wandlers (WLAN-Sendespitzen eingerechnet), nicht der Durchschnitt.
  - Der einzige veröffentlichte Gesamtwert für das CYD liegt bei **ca. 115 mA** [9][10], allerdings ohne Angabe der Bedingungen.
- **Plan (nur Software):**
  - 4 Energiezustände: AKTIV → GEDIMMT (nach 30 s) → RUHE (Display aus, nach 2 min), dazu eine optionale NACHT-Variante.
  - WLAN nur noch zum Uhr-Abgleich (beim Start, dann alle 6 h).
  - Bluetooth nur in kurzen Fenstern.
  - CPU auf 80 MHz.
  - In RUHE manueller Light-Sleep mit Aufwachen alle 100 ms, damit die Waage weiter 10× pro Sekunde gelesen wird und die Trink-Erkennung **unverändert** bleibt.
  - → **ca. 18–32 h** bei Dauernutzung am Schreibtisch, **ca. 20–36 h** im 24-h-Tag (S). Damit hält das Gerät sicher einen ganzen Tag. Laden etwa jede Nacht bis jeden zweiten Tag.
- **Plan + 1 Hardware-Änderung** (5 V des LED-Streifens per FET abschalten, solange er dunkel ist): **ca. 24–47 h** bei Dauernutzung bzw. **ca. 27–54 h** im 24-h-Tag (S).
- **Wichtigste Entdeckung:** Der Pololu S13V10F5 braucht laut Hersteller selbst bei 3,7 V Eingang schon **ca. 9–10 mA ohne Last** [6]. Er hat **keinen Enable-Eingang** [6]. Ein echtes „Aus“ ist per Software also unmöglich. Dafür braucht es einen **Schalter** (offene Entscheidung, Kapitel 7).

---

## 1. Ist-Analyse: Wer verbraucht Strom und wie steuert der Sketch ihn?

| # | Verbraucher | So steuert der Sketch ihn heute (Zeilen in `sketch.ino`) | Bewertung |
|---|---|---|---|
| 1 | **Hintergrundlicht** (GPIO21) | `pinMode(21, OUTPUT); digitalWrite(21, HIGH)` in `anzeigeInit()` (Z. 498–499). **Kein PWM**, wird **nie** gedimmt oder ausgeschaltet. | größter Einzelverbraucher (S) |
| 2 | **CPU** | Keine Einstellung im Sketch → Board-Standard „ESP32 Dev Module“ = **240 MHz** (`boards.txt`: `esp32.build.f_cpu=240000000L`). `loop()` endet mit `delay(5)` (Z. 2011), **kein Schlafmodus**. | |
| 3 | **Display-Neuzeichnen** | `drawUI()` höchstens 5× pro Sekunde (Z. 1776), zeichnet nur geänderte Bereiche (`geaendert()`, Z. 1476). Läuft immer, auch wenn niemand hinschaut. | wenig Strom, aber unnötig, solange das Display aus ist |
| 4 | **WLAN** | `uhrStarten()` (Z. 646–652): `WIFI_STA` + `WiFi.begin()`, wird **nie abgeschaltet**. Standard im Kern: Modem-Sleep `WIFI_PS_MIN_MODEM` (WiFiGeneric.cpp). SNTP gleicht alle **3 h** ab (`CONFIG_LWIP_SNTP_UPDATE_DELAY=10800000`). Ohne erreichbares WLAN versucht der Kern immer wieder neu zu verbinden (Auto-Reconnect). | dauerhafter Verbrauch, ohne WLAN noch höher (S) |
| 5 | **Bluetooth (NimBLE)** | Nur bei `HYDRO_BLE 1`: `bleStarten()` beim Start (Z. 1308–1329). 120 s Werbung (Advertising) beim Start und nach jeder Trennung (Z. 1347–1358, 1389–1394). **Danach bleibt der BLE-Stack eingeschaltet**, er wirbt nur nicht mehr. | blockiert Light-Sleep (Kap. 2) |
| 6 | **Waage HX711** | `waageLesen()` liest 10× pro Sekunde (Z. 788), sobald `is_ready()`. **Nie `power_down()`**. | laut Datenblatt < 1,5 mA [7] plus Speisestrom der Wägezelle (S) |
| 7 | **LED-Streifen (26 × WS2812-COB)** | Im Normalbetrieb schwarz (`setup()` Z. 1948–1951). Sendet nur bei Farbwechsel (Z. 1465). **Erinnerung = Dauer-Blau, bis getrunken wird** (Z. 1142–1147, 1457), das kann Stunden dauern. | auch „aus“ braucht jeder LED-Chip Ruhestrom: ca. 0,45–0,6 mA pro LED [8] |
| 8 | **Akku-Messung** (GPIO35) | `analogRead` alle 500 ms (Z. 966–969). Prozent **linear** 3,0–4,2 V (Z. 973–974), dadurch kommt die Warnung „unter 20 %“ erst bei ca. 3,24 V. Echt: Teiler aus 2 × 10 kΩ (Einkaufsliste Pos. 14) zieht dauerhaft ca. 0,19 mA aus dem Akku (3,7 V / 20 kΩ). | Prozentanzeige bei LiPo zu optimistisch (Kap. 5) |
| 9 | **Nässe-Sensor** (GPIO19) | `digitalRead` in jeder Schleife (Z. 951–964). Das Modul (Komparator + Power-LED) ist immer an. | ca. 1–4 mA (S) |
| 10 | **Touch XPT2046** | `XPT2046_Touchscreen touch(33, 36)`, IRQ an **GPIO36** (Z. 484). Die Bibliothek hängt einen FALLING-Interrupt an GPIO36 und schaltet den Chip nach jeder Messung wieder in Power-down **mit aktivem PENIRQ** (letzter Befehl `0xD0`, XPT2046_Touchscreen.cpp Z. 143). | Grundlage für „Touch weckt auf“ |
| 11 | **CYD-Platine selbst** | AMS1117-3,3-V-Regler (Ruhestrom 5 mA typ., 10 mA max [11]), CH340C (USB-Seriell), Verstärker SC8002B, LDR-Teiler, Logik von ILI9341 und XPT2046 [12]. Der Sketch beeinflusst sie nicht. | Grundlast ca. 8–20 mA (S), **muss gemessen werden** |
| 12 | **Pololu S13V10F5** | – | Ruhestrom ca. 8–13 mA bei 2,8–4,0 V Eingang (Herstellergrafik) [6], Wirkungsgrad bei 3,3–5 V Eingang und 0,1–0,3 A ca. 88–93 % [6] |

**Nebenbefund, ohne Stromsparen schon ein Fehler:** Nach den 2 min Suche gibt es am echten Gerät **keinen Weg**, Bluetooth erneut sichtbar zu schalten. Das geht nur über den Seriellen Befehl `bt suchen`. Ohne Laptop kann sich die App danach nicht mehr verbinden. Der Plan löst das mit (Kap. 3, M6).
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

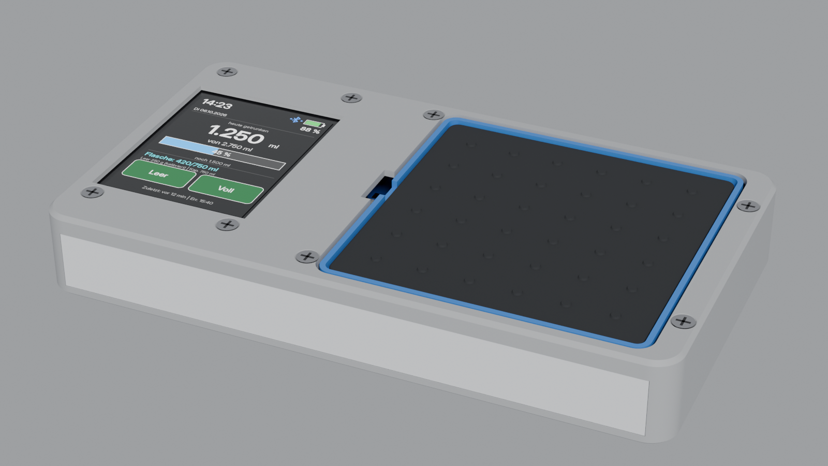
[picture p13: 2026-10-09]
design/3d_modell/vorschau_komplett.png

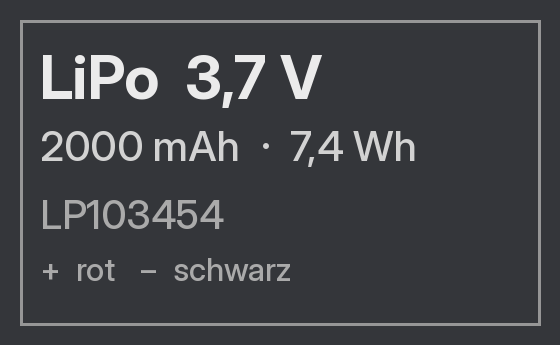
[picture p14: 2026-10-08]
design/visualisierung/src/tex/battery_label.png

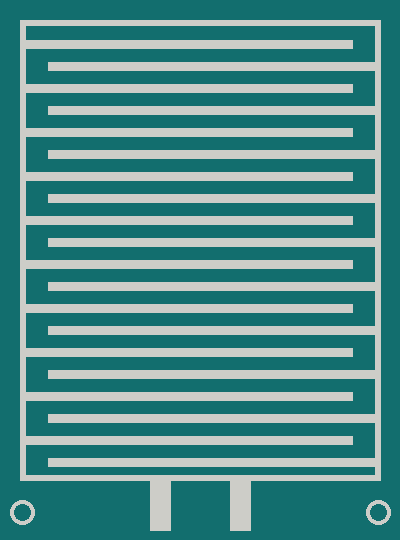
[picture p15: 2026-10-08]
design/visualisierung/src/tex/rain_plate.png

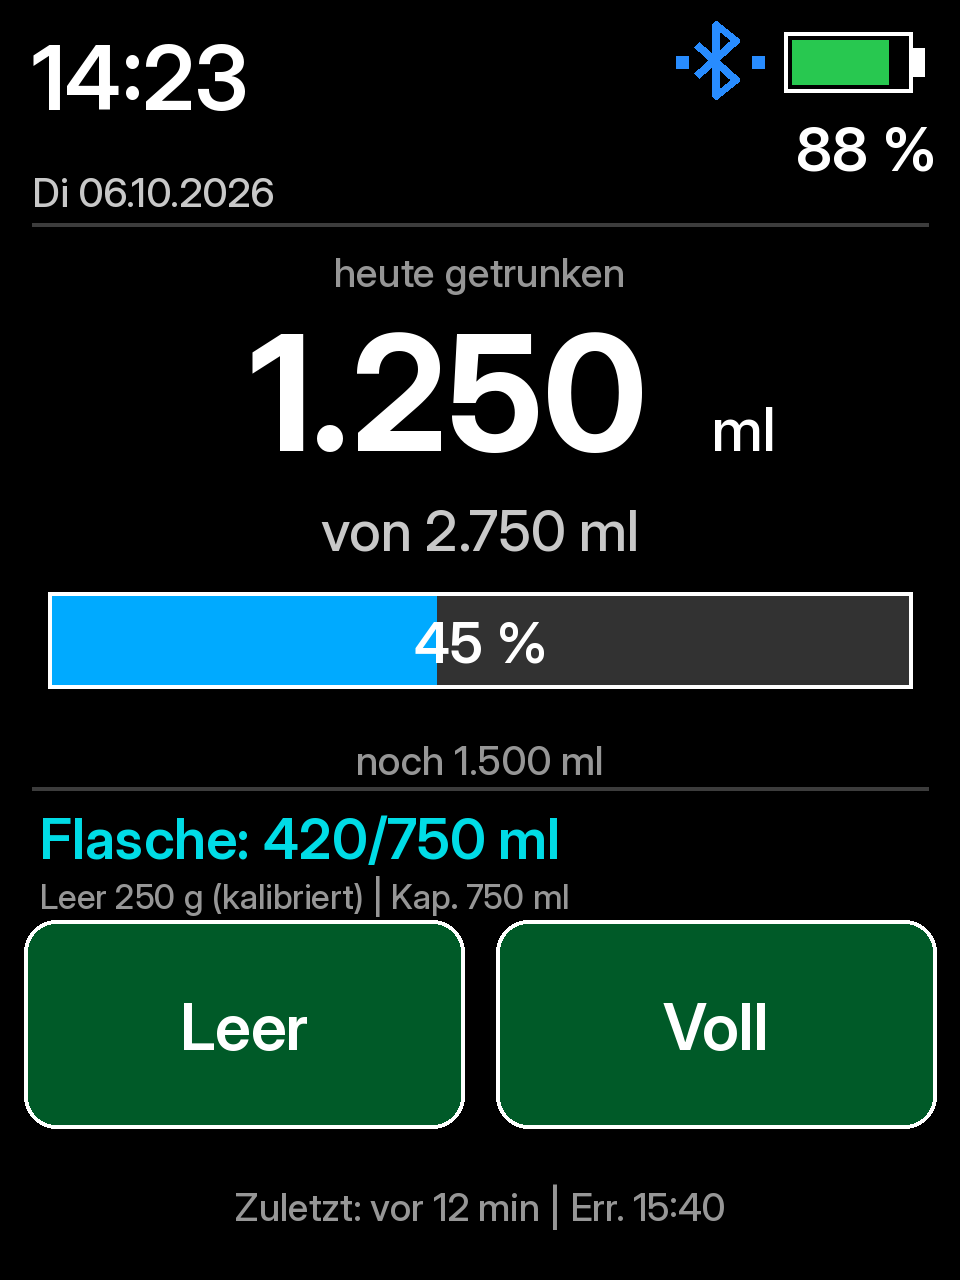
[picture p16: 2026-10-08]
design/visualisierung/src/tex/screen_ui.png

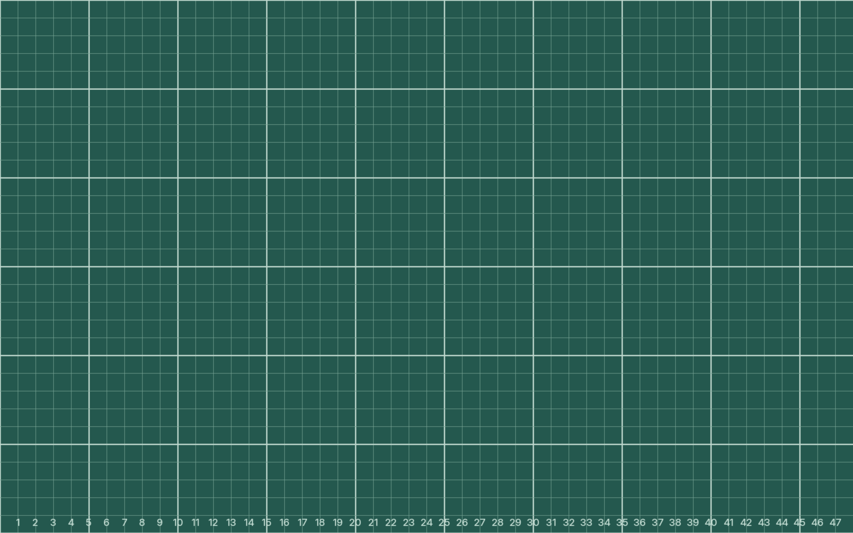
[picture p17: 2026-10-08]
design/visualisierung/src/tex/cutting_mat.png

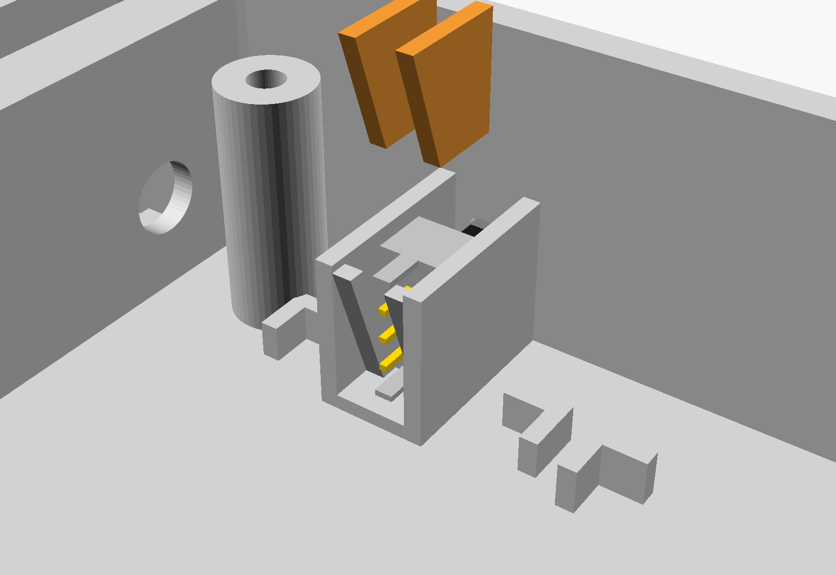
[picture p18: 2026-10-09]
gehaeuse/preview/23_schalter_einsetzen.png

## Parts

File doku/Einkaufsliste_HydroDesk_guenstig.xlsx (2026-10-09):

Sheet: Teileliste
Pos | Bauteil | benötigte Menge | Einheit | Spezifikation | Pflicht/Optional
1 | CYD ESP32-2432S028R (2,8" ILI9341, resistiver Touch) | 1 | Stk | ESP32-2432S028R, 2,8" 240×320, Touch, Platine 50×86 mm; JST-1,25-4-Pin an CN1/P3 | Pflicht
2 | Wägezelle 5 kg + HX711 | 1 | Set | Alu-Biegebalken 80×12,7×12,7 mm, 2×M4 / 2×M5 (TAL220-Bauform), HX711-Modul | Pflicht
3 | COB-LED-Streifen WS2812B (FCOB), 160 LED/m, 5 mm | 26 | LEDs | 26 LEDs = 13 Segmente à 12,5 mm = 162,5 mm; 5 V; 5 mm breit; jede LED mit eigenem IC; hinter gedruckter Diffusor-Leiste; 330–470 Ω in DIN | Pflicht
4 | Regensensor LM393 (FC-37/YL-83) | 1 | Set | Sensorplatte ca. 40×54 mm + Komparator-Modul ca. 16×30 mm | Pflicht
5 | P-MOSFET AO3401A (SOT-23): Q1 LED-Strom, Q2 Akku-Schalter | 2 | Stk | P-Kanal −30 V / −4 A, U_GS(th) −0,5…−1,3 V, High-Side; auf SOT-23-Adapter löten (V4, statt FET-Modul) | Pflicht
6 | LiPo 3,7 V (EEMB LP103454 oder gleiche Maße) | 1 | Stk | Muss in 34,5×56×10,3 mm Fach; mit Schutzschaltung (PCM); JST-PH-2.0 | Pflicht
7 | Lademodul TC4056/TP4056 USB-C mit Schutz | 1 | Stk | Fach 17×26 mm (Anschlag!), USB-C, mit DW01-Schutz, OUT+/OUT- | Pflicht
8 | 5-V-Wandler (Step-Up) | 1 | Stk | Fach 37×17 mm; Eingang 3,0–4,2 V; 5 V, ≥1 A (Last ca. 0,5–0,8 A) | Pflicht
9 | Senkkopfschraube M3×12 (DIN 7991/965) | 8 | Stk | selbstschneidend in 2,5-mm-Kernloch; Senkung Ø6,8 | Pflicht
10 | Senkkopfschraube M4×10 (DIN 7991) | 2 | Stk | Wägezelle Seite M4 | Pflicht
11 | Senkkopfschraube M5×12 (DIN 7991) | 2 | Stk | Wägezelle Seite M5 | Pflicht
12 | Gummifüße selbstklebend | 4 | Stk | Ø ≤ 13 mm (Tasche Ø13, 1 mm tief) | Pflicht
13 | Silikon-Matte (Pad) | 1 | Stk | 86×86 mm zuschneiden, 1–1,5 mm dick | Pflicht
14 | Widerstand 100 kΩ (Akku-Spannungsteiler GPIO35) | 2 | Stk | 100k/100k; Alternative 2×10 kΩ (gleiches Verhältnis, mehr Ruhestrom) | Pflicht
15 | Litze dünn (AWG 24–26) | 1 | Set | ca. 1–2 m; für 5 V/LED min. 0,14 mm² | Pflicht
16 | Kabel JST 1,25 mm 4-polig (CYD CN1/P3) | 2 | Stk | Oft liegt dem CYD 1 Kabel bei – prüfen; sonst anlöten | Pflicht*
17 | microSD-Sniffer (SD-Slot-Pins 18/19/23) | 1 | Stk | Nur nötig, wenn nicht an die SD-Pins gelötet wird | Pflicht*
18 | Schrumpfschlauch-Set | 1 | Set | für Lötstellen | Pflicht
19 | Doppelseitiges Klebeband (oder Heißkleber) | 1 | Rolle | Module fixieren | Pflicht
20 | Kabelbinder 100×2,5 | 1 | Pack | Kabel bündeln | Pflicht
21 | JST-PH-2.0-Verlängerung 2-pol. (Akku steckbar) | 1 | Stk | Optional: Akku nicht abschneiden | Optional
22 | PLA-Filament 1,75 mm | 128 | g | nur falls Schule kein PLA stellt (Base ca. 80 + Deckel 16 + Pad 27 + Kappe 1 + Diffusor ca. 4 g + 2 Klemmkeile < 1 g; Diffusor in Weiß) | Optional
23 | Jumper-Kabel-Set (Prototyp auf Breadboard) | 1 | Set | nur für Testaufbau | Optional
24 | Treiber-Transistor BC547B (NPN, TO-92) | 1 | Stk | I_C 100 mA, h_FE 200–450; zieht das Gate von Q1 auf GND | Pflicht
25 | Widerstand 470 Ω | 1 | Stk | in DIN direkt am LED-Streifen | Pflicht
26 | Widerstand 4,7 kΩ | 1 | Stk | GPIO18 → Basis BC547B | Pflicht
27 | Widerstand 47 kΩ | 2 | Stk | Basis→GND (BC547B), Gate→Source Q2 | Pflicht
28 | Widerstand 10 kΩ | 1 | Stk | Gate→Source Q1 (zusätzlich zu Pos. 14) | Pflicht
29 | SOT-23-Adapter (Breakout auf 2,54 mm) | 2 | Stk | je ein AO3401A | Pflicht
30 | Stiftleiste 1×20, RM 2,54 | 1 | Stk | für die SOT-23-Adapter | Pflicht
31 | Elko 470 µF / 25 V (Ø 10 × 16 mm) | 1 | Stk | 5 V → GND vor Q1, liegend | Pflicht
32 | Lochrasterplatine (Zuschnitt 30 × 24,5 mm) | 1 | Stk | FET-Platine | Pflicht
33 | Ein/Aus-Schiebeschalter C&K OS102011MS2QN1 | 1 | Stk | 1× Um (ON-ON), 8,6 × 4,3 × 4 mm, Schieber 2 mm, in der linken Wand | Pflicht
34 | Klemmkeile für den Schalter (3D-Druck) | 2 | Stk | aus PLA gedruckt (stl/schalter_keile.stl), 0 € | Pflicht
* Pflicht, sofern nicht gelötet wird bzw. Kabel nicht beim CYD dabei ist. Ein/Aus-Schalter ab V4 (Pos. 33, schaltet über den P-MOSFET Q2 den Akku). Keine Einpressmuttern/Muttern nötig (M3 schneidet selbst ins 2,5-mm-Loch).

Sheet: Preisvergleich
Pos | Bauteil | Shop | Produkt | Packung | Stk/Packung | Preis € (inkl. MwSt.) | Preis pro Stück € | benötigt | Kosten für Bedarf € | Versand | Lieferzeit | Link | Datum geprüft | Hinweis / Status | günstigste
1 | CYD | Amazon | Fastsaw ESP32-2432S028R 2,8" Touch, USB-C | 1 Stk | 1 | 17.99 € | 17.990 € | 1 | 17.99 € | frei ab 49 € (Versand durch Amazon), sonst 3,99 € | 1–3 Tage | https://www.amazon.de/dp/B0G1N16Q16 | 08.10.2026 | Verkauf Fastsaw, Versand durch Amazon; ILI9341, Touch geprüft
1 | CYD | AliExpress | ESP32-2432S028R 2,8" Touch ILI9341 (1/2/4 Stk) | 1 Stk | 1 | 15.39 € | 15.390 € | 1 | 15.39 € | laut Suchliste kostenlos | 1–3 Wochen | https://de.aliexpress.com/item/1005009535167188.html | 08.10.2026 | ab-Preis lt. Suchliste (günstigste Variante); Variante im Warenkorb prüfen; erst 10 verkauft | ✔ günstigste
1 | CYD | AliExpress | ESP32-2432S028R 2,8" Touch (Bestseller, 4,8★, 1.000+ verkauft) | 1 Stk | 1 | 17.89 € | 17.890 € | 1 | 17.89 € | nicht lesbar | 1–3 Wochen | https://de.aliexpress.com/item/1005007708576179.html | 08.10.2026 | ab-Preis lt. Suchliste; Versand nicht lesbar
1 | CYD | Berrybase / Reichelt / AZ-Delivery | — | — | 1 | — |  | 1 |  | — | — |  | 08.10.2026 | nicht im Sortiment
2 | Wägezelle+HX711 | Amazon | DIYmalls 5 kg Wägezelle + HX711 | 1 Set | 1 | 8.97 € | 8.970 € | 1 | 8.97 € | frei ab 49 € (Versand durch Amazon), sonst 3,99 € | 1–3 Tage | https://www.amazon.de/dp/B0B9H3YMT2 | 08.10.2026 | keine Schrauben dabei; HX711-Stiftleiste nicht gelötet
2 | Wägezelle+HX711 | AliExpress | Wägezelle 1–20 kg + HX711 (Set, Variante wählbar) | 1 Set | 1 | 4.89 € | 4.890 € | 1 | 4.89 € | AliExpress Choice: frei ab 10 € Bestellwert | 1–3 Wochen | https://de.aliexpress.com/item/1005009230467552.html | 08.10.2026 | ab-Preis = günstigste Variante; Preis der 5-kg-Variante NICHT lesbar | ✔ günstigste
2 | Wägezelle+HX711 | Berrybase | Wägezelle 5 kg (5,40 €) + HX711 (1,25 €) | 1+1 | 1 | — |  | 1 |  | 4,95 € DHL, frei ab 150 € | — | https://www.berrybase.de/dehnungsmessstreifen-waegezelle-5kg | 08.10.2026 | beide aktuell NICHT lieferbar
2 | Wägezelle+HX711 | Reichelt | Joy-IT SEN-HX711-05 | 1 Set | 1 | 6.40 € | 6.400 € | 1 | 6.40 € | 5,95 € DHL | 1–2 Tage |  | 08.10.2026 | PASST NICHT: Zelle 80×15×14,2 mm, nur M4 – Gehäuse müsste geändert werden
3 | WS2812B COB | Amazon | BTF-LIGHTING WS2812B FCOB 1 m 160 LED/m 5 V, 5 mm | 1 m | 1 | 16.99 € | 16.990 € | 1 | 16.99 € | frei ab 49 € (Versand durch Amazon), sonst 3,99 € | 1–3 Tage | https://www.amazon.de/dp/B0H41MCVSW | 08.10.2026 | GEWÄHLT (Design-Änderung): Variante „1M 160LEDs/m 5mm“ wählen; jede LED eigener IC, teilbar alle 12,5 mm → 26 LEDs (162,5 mm)
3 | WS2812B COB | AliExpress | WS2812B FCOB COB-Streifen (Variante wählbar) | Rolle (Variante) | 1 | 7.59 € | 7.590 € | 1 | 7.59 € | nicht lesbar | 1–3 Wochen | https://de.aliexpress.com/item/1005006422072860.html | 08.10.2026 | ab-Preis = günstigste Variante; Preis für 1 m / 160 LED/m / 5 mm NICHT lesbar | ✔ günstigste
3 | WS2812B (alt) | Amazon | BTF-Lighting WS2812B ECO 1 m 60 LED/m IP30, 10 mm | 1 m | 1 | 9.49 € | 9.490 € | 1 | 9.49 € | frei ab 49 € (Versand durch Amazon), sonst 3,99 € | 1–3 Tage | https://www.amazon.de/dp/B088BRY2SH | 08.10.2026 | GESTRICHEN 08.10.2026: einzelne LED-Punkte sichtbar, 10 mm breit → ersetzt durch COB-Streifen
3 | WS2812B (alt) | AliExpress | WS2812B 30/60/74/96/144 LED/m, schwarz/weiß | Rolle (Variante) | 1 | 6.19 € | 6.190 € | 1 | 6.19 € | laut Suchliste kostenlos | 1–3 Wochen | https://de.aliexpress.com/item/1005008750140385.html | 08.10.2026 | GESTRICHEN 08.10.2026: normaler Punkt-Streifen statt COB
4 | Regensensor | Berrybase | Regensensor mit digitalem und analogem Ausgang | 1 Set | 1 | 1.80 € | 1.800 € | 1 | 1.80 € | 4,95 € DHL, frei ab 150 € | 1–3 Tage | https://www.berrybase.de/regensensor-mit-digitalem-und-analogem-ausgang | 08.10.2026 | lieferbar
4 | Regensensor | Reichelt | Regentropfen-/Feuchtigkeits-Sensormodul | 1 Set | 1 | 3.15 € | 3.150 € | 1 | 3.15 € | 5,95 € DHL | 1–2 Tage | https://www.reichelt.de/de/de/shop/produkt/entwicklerboards_-_regentrofpen-_feuchtigkeits-sensormodul-282565 | 08.10.2026
4 | Regensensor | Amazon | Aihasd Regensensor (2 Stk) | 2 Sets | 2 | 5.99 € | 2.995 € | 1 | 5.99 € | frei ab 49 € (Versand durch Amazon), sonst 3,99 € | 1–3 Tage | https://www.amazon.de/dp/B017M1NJR0 | 08.10.2026 | Platte 5×4 cm; Rezensionen: Korrosion
4 | Regensensor | AliExpress | Regentropfen-Sensormodul 3,3–5 V (1/5/10 Stk) | 1 Set | 1 | 1.59 € | 1.590 € | 1 | 1.59 € | AliExpress Choice: frei ab 10 € Bestellwert | 1–3 Wochen | https://de.aliexpress.com/item/1005007987689565.html | 08.10.2026 | ab-Preis lt. Suchliste | ✔ günstigste
5 | FET-Modul (alt) | Amazon | GERUI Dual-MOS Schaltmodul (8 Stk) | 8 Stk | 8 | 6.49 € | 0.811 € | 1 | 6.49 € | frei ab 49 € (Versand durch Amazon), sonst 3,99 € | 1–3 Tage | https://www.amazon.de/dp/B0DG8B58PM | 08.10.2026 | GESTRICHEN 09.10.2026 (V4): Low-Side und mit 3,3 V am Gate unsicher → P-MOSFET AO3401A (High-Side) mit BC547B-Treiber
6 | LiPo | Amazon | EEMB LP103454 3,7 V, PCM, JST-PH 2.0 | 1 Stk | 1 | 10.99 € | 10.990 € | 1 | 10.99 € | frei ab 49 € (Versand durch Amazon), sonst 3,99 € | 1–3 Tage | https://www.amazon.de/dp/B08214DJLJ | 08.10.2026 | 34,5×56×10,6 mm → passt (ca. 1,1 mm Luft unter CYD); POLARITÄT prüfen | ✔ günstigste
6 | LiPo | Berrybase / Reichelt | — | — | 1 | — |  | 1 |  | — | — |  | 08.10.2026 | kein passendes Format gefunden
7 | TC4056 USB-C | Amazon | TC4056 USB-C Lademodul mit Schutz (10 Stk) | 10 Stk | 10 | 6.99 € | 0.699 € | 1 | 6.99 € | frei ab 49 € (Versand durch Amazon), sonst 3,99 € | 1–3 Tage | https://www.amazon.de/dp/B0F67KYB4F | 08.10.2026 | Maß 'Standard' – vor Einbau messen (Fach 26 mm); evtl. fehlende CC-Widerstände
7 | TC4056 USB-C | AliExpress | TP4056 Typ-C/Micro mit Schutz (2/5 Stk) | 2 Stk (Variante) | 2 | 1.55 € | 0.775 € | 1 | 1.55 € | nicht lesbar | 1–3 Wochen | https://de.aliexpress.com/item/1005013255677257.html | 08.10.2026 | ab-Preis = günstigste Variante (evtl. Micro-USB) – Typ-C wählen | ✔ günstigste
7 | TC4056 USB-C | Berrybase | Ladeplatine mit Ausgang, Micro-USB | 1 Stk | 1 | 1.30 € | 1.300 € | 1 | 1.30 € | 4,95 € DHL, frei ab 150 € | 1–3 Tage | https://www.berrybase.de/ladeplatine-fuer-3-7v-liion-lipo-akkus-mit-ausgang-micro-usb-loetpads-1000ma | 08.10.2026 | Micro-USB – Gehäuse ist für USB-C gebaut; USB-C-Version nicht lieferbar
8 | Step-Up 5 V | Berrybase | Pololu S13V10F5 5 V 1 A Step-Up/Step-Down | 1 Stk | 1 | 9.95 € | 9.950 € | 1 | 9.95 € | 4,95 € DHL, frei ab 150 € | 1–3 Tage | https://www.berrybase.de/pololu-s13v10f5-5v-1a-step-up-step-down-converter | 08.10.2026 | GEWÄHLT in beiden Körben (08.10.2026): fest 5 V, 1 A, UVLO, Softstart, Überstromschutz; klein (ca. 9×12 mm) → im 37×17-Fach fixieren. Vergleich: Botland 7,90 € + Versand ab 4,99 € (eigener Shop, https://botland.de/aufwarts-abwartswandler/21022-s13v10f5-aufwarts-abwartswandler-5v-1a-pololu-4083.html), Eckstein 11,80 € – Berrybase ist im Korb am günstigsten, weil der Berrybase-Versand ohnehin anfällt | ✔ günstigste
8 | Step-Up 5 V | Berrybase | Pololu S13V20F5 5 V 2 A | 1 Stk | 1 | 17.95 € | 17.950 € | 1 | 17.95 € | 4,95 € DHL, frei ab 150 € | 1–3 Tage | https://www.berrybase.de/pololu-s13v20f5-5v-2a-step-up-step-down-spannungsregler | 08.10.2026 | mehr Reserve
8 | Step-Up 5 V | AliExpress | MT3608 Step-Up einstellbar (2 Stk) | 2 Stk | 2 | 2.04 € | 1.020 € | 1 | 2.04 € | lt. Liste '3+, kein Zollaufschlag' | 1–3 Wochen | https://de.aliexpress.com/item/1005009806778521.html | 08.10.2026 | GESTRICHEN 08.10.2026 (auch im günstigen Korb): bei 3,7→5 V real nur ca. 0,5 A – zu wenig für CYD (0,25–0,35 A) + 26 COB-LEDs (bis ca. 0,49 A); Poti, Ripple, heiß
8 | Step-Up 5 V | Amazon | AZDelivery 3× MT3608 | 3 Stk | 3 | — |  | 1 |  | — | — | https://www.amazon.de/dp/B07YWKN9NW | 08.10.2026 | derzeit nicht verfügbar; außerdem zu schwach (siehe Zeile darüber)
9 | M3×12 | alleschrauben.de | Senkkopfschraube M3×12 Innensechskant DIN 7991 A2 | ab 10 Stk | 10 | 2.50 € | 0.250 € | 8 | 2.50 € | nicht lesbar (erst im Warenkorb), frei ab 79 € | 1–3 Tage | https://alleschrauben.de/Schrauben/Senkkopf/Senkkopfschrauben-DIN-7991/Senkkopfschrauben-M3x12-mit-Innensechskant-DIN-7991-Edelstahl-A2 | 08.10.2026 | 0,25 €/Stk ab 10 | ✔ günstigste
10 | M4×10 | alleschrauben.de | Senkkopfschraube M4×10 Innensechskant DIN 7991 A2 | Stück | 1 | 0.56 € | 0.560 € | 2 | 1.12 € | nicht lesbar (erst im Warenkorb), frei ab 79 € | 1–3 Tage | https://alleschrauben.de/Schrauben/Senkkopf/Senkkopfschrauben-DIN-7991/Senkkopfschrauben-M4x10-mit-Innensechskant-DIN-7991-Edelstahl-A2 | 08.10.2026 |  | ✔ günstigste
10 | M4×10 | Reichelt | Flach-Senkkopfschrauben PZD M4×10 (50 Stk) | 50 Stk | 50 | 1.85 € | 0.037 € | 2 | 1.85 € | 5,95 € DHL | 1–2 Tage | https://www.reichelt.de/de/de/shop/produkt/flach-senkkopfschrauben_kreuzschlitz_pzd_m4_10_mm_50_stueck-65750 | 08.10.2026 | nur M4 – M3/M5 dort nicht gefunden
11 | M5×12 | alleschrauben.de | Senkkopfschraube M5×12 Innensechskant DIN 7991 A2 | Stück | 1 | 0.62 € | 0.620 € | 2 | 1.24 € | nicht lesbar (erst im Warenkorb), frei ab 79 € | 1–3 Tage | https://alleschrauben.de/Schrauben/Senkkopf/Senkkopfschrauben-DIN-7991/Senkkopfschrauben-M5x12-mit-Innensechskant-DIN-7991-Edelstahl-A2 | 08.10.2026 |  | ✔ günstigste
12 | Füße | Berrybase | FIX&FASTEN Fuß rund Ø10 × 4,5 mm Gummi | Stück | 1 | 0.15 € | 0.150 € | 4 | 0.60 € | 4,95 € DHL, frei ab 150 € | 1–3 Tage | https://www.berrybase.de/fix-fasten-selbstklebender-fuss-rund-oben-9-5mm-unten-10mm-hoehe-4-5mm-gummi-schwarz | 08.10.2026 | passt in Ø13-Tasche | ✔ günstigste
12 | Füße | Amazon | InLine Gummifüße Ø12 × 3,6 mm (20 Stk) | 20 Stk | 20 | 5.45 € | 0.273 € | 4 | 5.45 € | frei ab 49 € (Versand durch Amazon), sonst 3,99 € | 1–3 Tage | https://www.amazon.de/dp/B09LDCTQGY | 08.10.2026
13 | Silikonmatte | Amazon | FICOFISE Silikonmatte 40×30 cm, 1,2 mm | 1 Stk | 1 | 7.59 € | 7.590 € | 1 | 7.59 € | frei ab 49 € (Versand durch Amazon), sonst 3,99 € | 1–3 Tage | https://www.amazon.de/dp/B0GVNMS4DZ | 08.10.2026 | Silikon klebt kaum → einlegen oder Silikonkleber | ✔ günstigste
14 | Widerstand | Reichelt | Metallschicht 100 kΩ 0207 0,6 W 1 % | Stück | 1 | 0.09 € | 0.090 € | 2 | 0.18 € | 5,95 € DHL | 1–2 Tage | https://www.reichelt.de/de/de/shop/produkt/widerstand_metallschicht_100_kohm_0207_0_6_w_1_-11458 | 08.10.2026 | Original-Wert; lohnt nur mit anderer Reichelt-Bestellung
14 | Widerstand | Berrybase | Metallschicht 100 kΩ 1/4 W | Stück | 1 | 0.05 € | 0.050 € | 2 | 0.10 € | 4,95 € DHL, frei ab 150 € | — | https://www.berrybase.de/metallschichtwiderstand-100-0-kohm-1-4w-1-0207-axial-durchsteckmontage | 08.10.2026 | nicht lieferbar
14 | Widerstand | Berrybase | Metallschicht 10 kΩ 1/4 W (Ersatz) | Stück | 1 | 0.05 € | 0.050 € | 2 | 0.10 € | 4,95 € DHL, frei ab 150 € | 1–3 Tage | https://www.berrybase.de/metallschichtwiderstand-10-0-kohm-1-4w-1-0207-axial-durchsteckmontage | 08.10.2026 | ERSATZ 2×10k: gleiches Verhältnis 1:2 (Firmware unverändert), aber ~0,2 mA Dauerstrom | ✔ günstigste
15 | Litze | Berrybase | Vierlingslitze 4×0,14 mm², 5 m | 5 m | 1 | 3.50 € | 3.500 € | 1 | 3.50 € | 4,95 € DHL, frei ab 150 € | 1–3 Tage | https://www.berrybase.de/vierlingslitze-isoliert-4x0-14mm-5m-farbe-blau-gelb-rot-gruen | 08.10.2026 | reicht für Signale + kurze 5-V-Leitungen
15 | Litze | Berrybase | Vierlingslitze 4×0,25 mm², 5 m | 5 m | 1 | 4.90 € | 4.900 € | 1 | 4.90 € | 4,95 € DHL, frei ab 150 € | 1–3 Tage | https://www.berrybase.de/vierlingslitze-isoliert-4x0-25mm-fuer-rgb-led-stripes-5m | 08.10.2026 | dicker, für LED-Strom
15 | Litze | AliExpress | Silikonlitze 30–20 AWG (Variante) | Variante | 1 | 1.09 € | 1.090 € | 1 | 1.09 € | nicht lesbar | 1–3 Wochen | https://de.aliexpress.com/item/1005008607415668.html | 08.10.2026 | ab-Preis = günstigste Variante; Länge/AWG im Warenkorb prüfen | ✔ günstigste
16 | JST 1,25 4-pol. | AliExpress | Micro JST 1,25 mm Stecker+Buchse mit Kabel 2–6P (20 Stk) | Set (Variante) | 1 | 1.49 € | 1.490 € | 1 | 1.49 € | nicht lesbar | 1–3 Wochen | https://de.aliexpress.com/item/4001171710583.html | 08.10.2026 | ab-Preis; 4P-Variante wählen; DE-Shops: kein passendes 4-pol. 1,25-mm-Kabel lieferbar gefunden | ✔ günstigste
17 | microSD-Sniffer | AliExpress | Micro SD Sniffer TF-Adapter (1–3 Stk) | 1 Stk | 1 | 2.39 € | 2.390 € | 1 | 2.39 € | nicht lesbar | 1–3 Wochen | https://de.aliexpress.com/item/1005009886368149.html | 08.10.2026 | ab-Preis lt. Suchliste; DE: Preis nicht ermittelt (Berrybase: kein Treffer) | ✔ günstigste
18 | Schrumpfschlauch | Berrybase | Schrumpfschlauch-Set 100-tlg. schwarz | Set | 1 | 2.80 € | 2.800 € | 1 | 2.80 € | 4,95 € DHL, frei ab 150 € | 1–3 Tage | https://www.berrybase.de/schrumpfschlauch-set-100-teilig-in-sortimentsbox-schwarz | 08.10.2026 |  | ✔ günstigste
19 | Klebeband | Berrybase | TESA doppelseitig 10 m × 12 mm | Rolle | 1 | 2.90 € | 2.900 € | 1 | 2.90 € | 4,95 € DHL, frei ab 150 € | 1–3 Tage | https://www.berrybase.de/tesa-doppelseitiges-klebeband-10m-x-12mm-transparent-pp-traeger-loesungsmittelfrei | 08.10.2026 | nur 1 Stk auf Lager | ✔ günstigste
20 | Kabelbinder | Berrybase | Kabelbinder UV-beständig 100×2,5 (100 Stk) | 100 Stk | 1 | 0.60 € | 0.600 € | 1 | 0.60 € | 4,95 € DHL, frei ab 150 € | 1–3 Tage | https://www.berrybase.de/kabelbinder-uv-bestaendig-nylon-100-stueck/farbe-transparent/masse-100x2-5mm | 08.10.2026 |  | ✔ günstigste
21 | JST-PH-Verl. (opt.) | Berrybase | Verlängerung 2-pol. JST-PH 2.0 Stecker/Buchse 50 cm | 1 Stk | 1 | 0.90 € | 0.900 € | 1 | 0.90 € | 4,95 € DHL, frei ab 150 € | 1–3 Tage | https://www.berrybase.de/verlaengerungskabel-2-pin-jst-ph-2.0mm-stecker-buchse-awg24-50cm | 08.10.2026 | optional | ✔ günstigste
22 | PLA (opt.) | Amazon | SUNLU PLA 1,75 mm 1 kg weiß | 1 kg | 1000 | 14.99 € | 0.015 € | 128 | 14.99 € | frei ab 49 € (Versand durch Amazon), sonst 3,99 € | 1–3 Tage | https://www.amazon.de/dp/B0BTHSVQ89 | 08.10.2026 | optional; ca. 128 g (inkl. Diffusor ca. 4 g weiß); früher 11,29 € – jetzt 14,99 € (anderer Händler auf Seite 13,99 €) | ✔ günstigste
23 | Jumper (opt.) | Amazon | ELEGOO 120 Jumper-Kabel 20 cm | 120 Stk | 1 | 6.99 € | 6.990 € | 1 | 6.99 € | frei ab 49 € (Versand durch Amazon), sonst 3,99 € | 1–3 Tage | https://www.amazon.de/dp/B01EV70C78 | 08.10.2026 | optional, nur Prototyp | ✔ günstigste
5 | P-MOSFET | Reichelt | Alpha & Omega AO3401A, P-Kanal −30 V −4 A, SOT-23 | Stück | 1 | 0.17 € | 0.170 € | 2 | 0.34 € | Versandkosten ab 5,95 € | 1–2 Tage | https://www.reichelt.de/de/de/shop/produkt/mosfet_p-ch_-30v_-4a_0_041r_sot-23-166486 | 09.10.2026 | ab Lager; Berrybase führt keinen P-MOSFET (Suche 09.10.2026) → eigener Reichelt-Versand | ✔ günstigste
24 | Treiber-Transistor | Berrybase | BC547B, NPN, 45 V, 100 mA, TO-92 | Stück | 1 | 0.17 € | 0.170 € | 1 | 0.17 € | 4,95 € DHL, frei ab 150 € | 1–3 Tage | https://www.berrybase.de/bc547b-bipolarer-transistor-npn-45v-100ma-to-92-3-pin | 09.10.2026 | schaltet das Gate von Q1 (GPIO18 → 4,7 kΩ → Basis) | ✔ günstigste
25 | Widerstand 470 Ω | Berrybase | Metallschicht 470 Ω 1/4 W 1 % | Stück | 1 | 0.05 € | 0.050 € | 1 | 0.05 € | 4,95 € DHL, frei ab 150 € | 1–3 Tage | https://www.berrybase.de/metallschichtwiderstand-470-0-ohm-1-4w-1-0207-axial-durchsteckmontage | 09.10.2026 | in DIN direkt am LED-Streifen | ✔ günstigste
26 | Widerstand 4,7 kΩ | Berrybase | Metallschicht 4,7 kΩ 1/4 W 1 % | Stück | 1 | 0.06 € | 0.060 € | 1 | 0.06 € | 4,95 € DHL, frei ab 150 € | 1–3 Tage | https://www.berrybase.de/metallschichtwiderstand-4-7-kohm-1-4w-1-0207-axial-durchsteckmontage | 09.10.2026 | GPIO18 → Basis BC547B | ✔ günstigste
27 | Widerstand 47 kΩ | Berrybase | Metallschicht 47 kΩ 1/4 W 1 % | Stück | 1 | 0.05 € | 0.050 € | 2 | 0.10 € | 4,95 € DHL, frei ab 150 € | 1–3 Tage | https://www.berrybase.de/metallschichtwiderstand-47-0-kohm-1-4w-1-0207-axial-durchsteckmontage | 09.10.2026 | Basis→GND und Gate→Source Q2 | ✔ günstigste
28 | Widerstand 10 kΩ (Gate Q1) | Berrybase | Metallschicht 10 kΩ 1/4 W 1 % | Stück | 1 | 0.05 € | 0.050 € | 1 | 0.05 € | 4,95 € DHL, frei ab 150 € | 1–3 Tage | https://www.berrybase.de/metallschichtwiderstand-10-0-kohm-1-4w-1-0207-axial-durchsteckmontage | 09.10.2026 | Gate→Source Q1; zusätzlich zu den 2 Stk. für den Akku-Teiler | ✔ günstigste
29 | SOT-23-Adapter | Berrybase | SMD Breakout Adapter SOT23 / SSOP10 / MSOP10, 12,7 × 10,2 mm | Stück | 1 | 0.32 € | 0.320 € | 2 | 0.64 € | 4,95 € DHL, frei ab 150 € | 1–3 Tage | https://www.berrybase.de/smd-breakout-adapter-fuer-sot23-ssop10-msop10-10-pin-0-50mm-0-95mm | 09.10.2026 | je ein AO3401A darauf löten; ohne Stiftleiste geliefert | ✔ günstigste
30 | Stiftleiste | Berrybase | Stiftleiste 1× 20-polig, RM 2,54, gerade | Stück | 1 | 0.20 € | 0.200 € | 1 | 0.20 € | 4,95 € DHL, frei ab 150 € | 1–3 Tage | https://www.berrybase.de/stiftleiste-1x-20-polig-rm-2-54-gerade | 09.10.2026 | für die 2 SOT-23-Adapter | ✔ günstigste
31 | Elko 470 µF | Berrybase | Elektrolytkondensator 470 µF, 25 V, 105 °C, Ø 10 × 16 mm | Stück | 1 | 0.10 € | 0.100 € | 1 | 0.10 € | 4,95 € DHL, frei ab 150 € | 1–3 Tage | https://www.berrybase.de/elektrolytkondensator-470-f-25v-1050c-1-radial-tht | 09.10.2026 | 5 V → GND vor Q1, liegt auf der FET-Platine | ✔ günstigste
32 | Lochrasterplatine | Berrybase | Lochrasterplatine „9 × 15 cm“ einseitig Kupfer (laut Daten 70,5 × 50,4 mm) | Stück | 1 | 1.10 € | 1.100 € | 1 | 1.10 € | 4,95 € DHL, frei ab 150 € | 1–3 Tage | https://www.berrybase.de/lochrasterplatine-9x15cm-mit-einseitiger-kupferauflage | 09.10.2026 | auf 30 × 24,5 mm zuschneiden; 5 × 7 cm (0,30 €) nicht lieferbar | ✔ günstigste
33 | Ein/Aus-Schalter | Berrybase | Schiebeschalter Printmontage ON-ON, 8,6 × 4,3 × 4 mm, gerade (C&K OS102011MS2QN1) | Stück | 1 | 0.70 € | 0.700 € | 1 | 0.70 € | 4,95 € DHL, frei ab 150 € | 1–3 Tage | https://www.berrybase.de/schiebeschalter-printmontage-on-on-2-stellig-8.6x4.3x4mm-gerade | 09.10.2026 | schaltet nur das Gate von Q2 (ca. 0,08 mA, Schalter 0,1 A) | ✔ günstigste
Legende: grün = günstigstes geeignetes Angebot (Kosten für Bedarf); rot = nicht lieferbar / passt nicht. AliExpress-Preise = 'ab'-Preis der günstigsten Variante laut Suchliste (EUR inkl. 19 % MwSt.); Produktseiten sind nicht maschinell lesbar → Preis der benötigten Variante im Warenkorb prüfen.
Versand: Amazon frei ab 49 € (nur Artikel mit Versand durch Amazon), sonst 3,99 €; Berrybase 4,95 € (frei ab 150 €); Reichelt ab 5,95 € (AO3401A-Seite, 09.10.2026); alleschrauben.de: Versandkosten erst im Warenkorb sichtbar (frei ab 79 €). Mindestbestellwerte: auf den gelesenen Seiten nicht angegeben.
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

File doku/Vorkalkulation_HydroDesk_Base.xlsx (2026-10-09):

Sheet: Vorkalkulation
Vorkalkulation HydroDesk Base (Rechteck-Version, ESP32 mit Touch-Display)
Stand 09.10.2026 (V4: Stromsparen H1/H2, Preise der neuen Teile am 09.10.2026 auf den Shopseiten abgelesen und geprüft; übrige Preise 08.10.2026): Preise inkl. MwSt. ohne Anmeldung abgelesen auf Amazon.de, Berrybase.de, Reichelt.de, alleschrauben.de und AliExpress (nur ab-Preis laut Suchliste). Basis: Korb „Schnell (DE-Shops, 1–3 Tage)“ aus Einkaufsliste_HydroDesk_guenstig.xlsx. Preise können sich ändern.
Pos. | Bauteil | Produkt | Inhalt Packung | Status | Preis (€) | Link | Hinweis
1 | ESP32 + Touch-Display | Fastsaw ESP32 mit 2,8" ILI9341 Touch (320×240), USB-C, TF-Slot | 1 Stk. | übernommen | 17.99 € | https://www.amazon.de/dp/B0G1N16Q16 | Amazon. Board-Typ ESP32-2432S028R („Cheap Yellow Display“). Prüfen, ob JST-1,25-Kabel beiliegt (sonst Pos. 19)
2 | Wägezelle + Verstärker | DIYmalls Wägezelle 5 kg + HX711 | 1 Set | übernommen | 8.97 € | https://www.amazon.de/dp/B0B9H3YMT2 | Amazon. Keine Schrauben dabei (→ Pos. 12/13); HX711-Stiftleiste selbst löten
3 | LED-Streifen (COB) | BTF-LIGHTING WS2812B FCOB, 1 m, 160 LED/m, 5 V, 5 mm, jede LED einzeln adressierbar | 1 m | ersetzt (Design-Änderung) | 16.99 € | https://www.amazon.de/dp/B0H41MCVSW | Amazon, Preis abgelesen 08.10.2026; Variante „1M 160LEDs/m 5mm“ wählen. 13 Segmente à 12,5 mm = 162,5 mm = 26 LEDs, hinter der gedruckten Diffusor-Leiste (Pos. 23) → durchgehende Lichtlinie. 330–470 Ω in DIN. Günstigste Alternative: AliExpress ab 7,59 € (https://de.aliexpress.com/item/1005006422072860.html, Preis der Variante nicht lesbar)
4 | Feuchtigkeitssensor | Regensensor LM393 mit digitalem und analogem Ausgang | 1 Set | ersetzt (günstiger) | 1.80 € | https://www.berrybase.de/regensensor-mit-digitalem-und-analogem-ausgang | Berrybase. Gleiches Bauteil wie vorher, statt Aihasd 2er-Pack 5,99 €
5 | LED-Strom + Ein/Aus (P-MOSFET) | Alpha & Omega AO3401A, P-Kanal, −30 V, −4 A, SOT-23 | 2 Stk. | ersetzt (Design-Änderung V4) | 0.34 € | https://www.reichelt.de/de/de/shop/produkt/mosfet_p-ch_-30v_-4a_0_041r_sot-23-166486 | Reichelt, 2 × 0,17 €, ab Lager. Q1 schaltet die 5 V des LED-Streifens (High-Side, GPIO18 über BC547B), Q2 den Akku (Ein/Aus-Schalter). Ersetzt das GERUI-Modul (Low-Side, 3,3-V-Ansteuerung kritisch). Bei Berrybase kein P-MOSFET im Sortiment → eigener Reichelt-Versand (Zeile Versand Reichelt). Tipp: 1 Stück Ersatz mitbestellen (+0,17 €)
6 | Akku | EEMB LiPo 3,7 V 2000 mAh (LP103454), mit Schutzschaltung | 1 Stk. | übernommen | 10.99 € | https://www.amazon.de/dp/B08214DJLJ | Amazon. 34,5 × 56 × 10,6 mm passt ins Fach; Polarität am JST-PH-Stecker vor dem Anstecken messen
7 | Lademodul | TC4056 USB-C Lademodul mit Schutz (10er-Pack) | 10 Stk. | übernommen | 6.99 € | https://www.amazon.de/dp/B0F67KYB4F | Amazon. Länge vor dem Einbau messen (Fach 26 mm); billige Module laden evtl. nur mit USB-A→C-Kabel
8 | 5-V-Wandler | Pololu S13V10F5, 5 V 1 A Step-Up/Step-Down | 1 Stk. | neu | 9.95 € | https://www.berrybase.de/pololu-s13v10f5-5v-1a-step-up-step-down-converter | Berrybase. Fest 5 V, Unterspannungs-Abschaltung; kleiner als das 37 × 17 mm Fach → mit Klebeband fixieren. Statt MT3608
9 | Gummifüße | FIX&FASTEN Fuß rund Ø10 mm, 4,5 mm hoch, selbstklebend | 4 Stk. | ersetzt (günstiger) | 0.60 € | https://www.berrybase.de/fix-fasten-selbstklebender-fuss-rund-oben-9-5mm-unten-10mm-hoehe-4-5mm-gummi-schwarz | Berrybase. 4 × 0,15 €; passt in die Ø13-mm-Vertiefung. Statt InLine 20 Stk. 5,45 €
10 | Flaschen-Pad | FICOFISE Silikonmatte 40 × 30 cm, 1,2 mm, rutschfest | 1 Stk. | übernommen | 7.59 € | https://www.amazon.de/dp/B0GVNMS4DZ | Amazon. Auf 86 × 86 mm zuschneiden; Silikon klebt kaum → Silikonkleber oder nur einlegen
11 | Schrauben M3 | Senkkopfschraube M3×12 Innensechskant DIN 7991, Edelstahl A2 | 10 Stk. | neu | 2.50 € | https://alleschrauben.de/Schrauben/Senkkopf/Senkkopfschrauben-DIN-7991/Senkkopfschrauben-M3x12-mit-Innensechskant-DIN-7991-Edelstahl-A2 | alleschrauben.de. 10 × 0,25 €, 8 werden gebraucht (Deckel, schneiden selbst ins 2,5-mm-Loch)
12 | Schrauben M4 | Senkkopfschraube M4×10 Innensechskant DIN 7991, Edelstahl A2 | 2 Stk. | neu | 1.12 € | https://alleschrauben.de/Schrauben/Senkkopf/Senkkopfschrauben-DIN-7991/Senkkopfschrauben-M4x10-mit-Innensechskant-DIN-7991-Edelstahl-A2 | alleschrauben.de. 2 × 0,56 €; Wägezelle, M4-Seite
13 | Schrauben M5 | Senkkopfschraube M5×12 Innensechskant DIN 7991, Edelstahl A2 | 2 Stk. | neu | 1.24 € | https://alleschrauben.de/Schrauben/Senkkopf/Senkkopfschrauben-DIN-7991/Senkkopfschrauben-M5x12-mit-Innensechskant-DIN-7991-Edelstahl-A2 | alleschrauben.de. 2 × 0,62 €; Wägezelle, M5-Seite
14 | Widerstände | Metallschichtwiderstand 10 kΩ, 1/4 W, 1 % | 2 Stk. | neu | 0.10 € | https://www.berrybase.de/metallschichtwiderstand-10-0-kohm-1-4w-1-0207-axial-durchsteckmontage | Berrybase. Spannungsteiler Akku → GPIO35. 100 kΩ dort nicht lieferbar; 2 × 10 kΩ = gleiches Verhältnis (Firmware gleich), ca. 0,2 mA Dauerstrom
15 | Litze | Vierlingslitze 4 × 0,14 mm², 5 m (blau/gelb/rot/grün) | 5 m | neu | 3.50 € | https://www.berrybase.de/vierlingslitze-isoliert-4x0-14mm-5m-farbe-blau-gelb-rot-gruen | Berrybase. Verdrahtung im Gehäuse (gelötet)
16 | Schrumpfschlauch | Schrumpfschlauch-Set 100-teilig, schwarz | 100 Stk. | neu | 2.80 € | https://www.berrybase.de/schrumpfschlauch-set-100-teilig-in-sortimentsbox-schwarz | Berrybase. Lötstellen isolieren
17 | Klebeband | TESA doppelseitiges Klebeband 10 m × 12 mm | 1 Rolle | neu | 2.90 € | https://www.berrybase.de/tesa-doppelseitiges-klebeband-10m-x-12mm-transparent-pp-traeger-loesungsmittelfrei | Berrybase. Module fixieren; nur 1 Stk. auf Lager (Alternative: Heißkleber)
18 | Kabelbinder | Kabelbinder UV-beständig 100 × 2,5 mm | 100 Stk. | neu | 0.60 € | https://www.berrybase.de/kabelbinder-uv-bestaendig-nylon-100-stueck/farbe-transparent/masse-100x2-5mm | Berrybase. Kabel ordnen
19 | JST-Kabel CYD | Micro JST 1,25 mm Stecker + Buchse mit Kabel (4-polig wählen) | Set | nur AliExpress | 1.49 € | https://de.aliexpress.com/item/4001171710583.html | NUR ALIEXPRESS, ab-Preis laut Suchliste, 1–3 Wochen. Für CN1/P3/P1. Entfällt, wenn Kabel beim CYD dabei sind oder direkt angelötet wird
20 | microSD-Sniffer | Micro SD Sniffer TF-Adapterplatine | 1 Stk. | nur AliExpress | 2.39 € | https://de.aliexpress.com/item/1005009886368149.html | NUR ALIEXPRESS, ab-Preis laut Suchliste, 1–3 Wochen. Für GPIO 18/19/23 am SD-Slot; entfällt, wenn an die Lötpunkte gelötet wird
21 | Gehäuse-Material | SUNLU PLA 1,75 mm, 1 kg | 1 kg | Preis aktualisiert | 14.99 € | https://www.amazon.de/dp/B0BTHSVQ89 | Amazon. Angebot 11,29 € abgelaufen. Ca. 128 g nötig (Unterschale ca. 80, Deckel 16, Pad 27, Kappe 1, Diffusor ca. 4, Klemmkeile unter 1); entfällt, wenn die Schule Filament stellt
22 | Abdeckkappe | Steckbare Kappe für die CYD-USB-Öffnung (3D-Druck) | 1 Stk. | neu | 0.00 € |  | Aus dem PLA von oben gedruckt (ca. 1 g), keine Extrakosten
23 | Diffusor-Leiste | Gedruckte Diffusor-Leiste vor dem LED-Streifen (3D-Druck, 166,7 × 16,7 × 1 mm) | 1 Stk. | neu | 0.00 € |  | Aus weißem PLA oder naturfarbenem PETG gedruckt (ca. 4 g, 1 mm, 100 % Füllung, flach). Keine Extrakosten, wenn das PLA von Pos. 21 weiß ist oder die Schule weißes Filament stellt
24 | Treiber-Transistor | BC547B, NPN, 45 V, 100 mA, TO-92 | 1 Stk. | neu (V4) | 0.17 € | https://www.berrybase.de/bc547b-bipolarer-transistor-npn-45v-100ma-to-92-3-pin | Berrybase. Schaltet das Gate von Q1 (GPIO18 → 4,7 kΩ → Basis)
25 | Widerstand 470 Ω | Metallschichtwiderstand 470 Ω, 1/4 W, 1 % | 1 Stk. | neu (V4) | 0.05 € | https://www.berrybase.de/metallschichtwiderstand-470-0-ohm-1-4w-1-0207-axial-durchsteckmontage | Berrybase. In die Datenleitung DIN direkt am LED-Streifen
26 | Widerstand 4,7 kΩ | Metallschichtwiderstand 4,7 kΩ, 1/4 W, 1 % | 1 Stk. | neu (V4) | 0.06 € | https://www.berrybase.de/metallschichtwiderstand-4-7-kohm-1-4w-1-0207-axial-durchsteckmontage | Berrybase. GPIO18 → Basis BC547B
27 | Widerstand 47 kΩ | Metallschichtwiderstand 47 kΩ, 1/4 W, 1 % | 2 Stk. | neu (V4) | 0.10 € | https://www.berrybase.de/metallschichtwiderstand-47-0-kohm-1-4w-1-0207-axial-durchsteckmontage | Berrybase. 2 × 0,05 €: Basis→GND (BC547B) und Gate→Source Q2 (Akku-Schalter)
28 | Widerstand 10 kΩ | Metallschichtwiderstand 10 kΩ, 1/4 W, 1 % | 1 Stk. | neu (V4) | 0.05 € | https://www.berrybase.de/metallschichtwiderstand-10-0-kohm-1-4w-1-0207-axial-durchsteckmontage | Berrybase. Gate→Source Q1 (LED-Strom standardmäßig aus); zusätzlich zu den 2 Stk. aus Pos. 14
29 | SOT-23-Adapter | SMD-Breakout-Adapter SOT23 / SSOP10 / MSOP10, 10 Pin | 2 Stk. | neu (V4) | 0.64 € | https://www.berrybase.de/smd-breakout-adapter-fuer-sot23-ssop10-msop10-10-pin-0-50mm-0-95mm | Berrybase. 2 × 0,32 €; je ein AO3401A darauf löten (SOT-23 ist zu klein für Lochraster). Stiftleiste: Pos. 34
30 | Elko | Elektrolytkondensator 470 µF, 25 V, 105 °C, radial (Ø 10 × 16 mm) | 1 Stk. | neu (V4) | 0.10 € | https://www.berrybase.de/elektrolytkondensator-470-f-25v-1050c-1-radial-tht | Berrybase. 5 V → GND vor Q1 (fängt Lastsprünge des Streifens ab); liegt auf der FET-Platine
31 | Lochrasterplatine | Lochrasterplatine 9 × 15 cm, einseitig Kupfer | 1 Stk. | neu (V4) | 1.10 € | https://www.berrybase.de/lochrasterplatine-9x15cm-mit-einseitiger-kupferauflage | Berrybase. Auf 30 × 24,5 mm zuschneiden (FET-Platine). Achtung: Titel „9 × 15 cm“, laut technischen Daten aber 70,5 × 50,4 × 1 mm – reicht in beiden Fällen. 5 × 7 cm (0,30 €) ist aktuell nicht lieferbar
32 | Ein/Aus-Schalter | Schiebeschalter C&K OS102011MS2QN1, 1× Um (ON-ON), 8,6 × 4,3 × 4 mm, Printmontage | 1 Stk. | neu (V4) | 0.70 € | https://www.berrybase.de/schiebeschalter-printmontage-on-on-2-stellig-8.6x4.3x4mm-gerade | Berrybase. Schaltet nur das Gate von Q2 (ca. 0,08 mA; Schalter verträgt 0,1 A) → Akku wirklich aus. Sitzt in der linken Wand, Schieber oben = AN
33 | Klemmkeile Schalter | 2 gedruckte Klemmkeile für den Ein/Aus-Schalter (3D-Druck) | 2 Stk. | neu (V4) | 0.00 € |  | Aus dem PLA von Pos. 21 gedruckt (unter 1 g), keine Extrakosten
34 | Stiftleiste | Stiftleiste 1× 20-polig, RM 2,54 mm, gerade | 1 Stk. | neu (V4) | 0.20 € | https://www.berrybase.de/stiftleiste-1x-20-polig-rm-2-54-gerade | Berrybase. Für die 2 SOT-23-Adapter (Pos. 29), die ohne Stiftleiste geliefert werden; je Adapter 3–5 Stifte abbrechen
 | Summe Bauteile |  |  |  | 119.01 €
 | Versand
 | Versand Amazon |  |  |  | 0.00 € |  | Frei ab 49 € (nur Artikel mit „Versand durch Amazon“), sonst 3,99 € – im Warenkorb prüfen
 | Versand Berrybase |  |  |  | 4.95 € |  | DHL 4,95 €, frei ab 150 €
 | Versand Reichelt |  |  |  | 5.95 € |  | Reichelt: Versandkosten ab 5,95 € (Produktseite AO3401A, 09.10.2026); nur für Pos. 5
 | Versand alleschrauben.de |  |  |  |  |  | Nicht lesbar – wird erst im Warenkorb angezeigt (frei ab 79 €), im Warenkorb prüfen
 | Versand AliExpress (Pos. 19/20) |  |  |  |  |  | Nicht lesbar – im Warenkorb prüfen (Choice-Artikel meist frei ab 10 €)
 | Summe Versand (bekannt) |  |  |  | 10.90 €
 | Puffer 10 % (Verschnitt, Ersatz, unbekannter Versand) |  |  |  | 11.90 €
 | Gesamt geplant |  |  |  | 141.81 €
 | Gesamt ohne PLA (falls die Schule druckt) |  |  |  | 125.32 € |  | Amazon bleibt auch ohne PLA über 49 € → Versand unverändert
 | Optional (nicht in der Summe)
 | Kabel (Test) | Elegoo Jumperkabel-Set | 1 Set | optional | 6.99 € | https://www.amazon.de/dp/B01EV70C78 | Amazon. Nur für einen Breadboard-Testaufbau; im fertigen Gerät wird mit Litze gelötet
 | Akku-Verlängerung | Verlängerungskabel 2-polig JST-PH 2.0, Stecker/Buchse, 50 cm | 1 Stk. | optional | 0.90 € | https://www.berrybase.de/verlaengerungskabel-2-pin-jst-ph-2.0mm-stecker-buchse-awg24-50cm | Berrybase. Damit der Akku-Stecker nicht abgeschnitten werden muss

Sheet: Gestrichen
Gestrichenes Teil | Grund
AZDelivery ESP32 DevKit 3er-Pack (B074RGW2VQ), 21,99 € | ESP32 ist jetzt im Display-Board eingebaut
Fasizi 2,8" ILI9341 Touch-Display (B09Z29CGY1), 10,99 € | Ersetzt durch Fastsaw ESP32-Display-Board
Rundes GC9A01-Display (B0DB5MR27T) | Rechteckiges Design
WS2812 LED-Ring (B0GYF2PHV1) | Ersetzt durch LED-Leiste an der Vorderkante
Blumtal Trinkflasche (B09FDZX7LC) | Keine eigene Flasche mehr, jede Flasche passt
O-Ringe (B0DC69DWRT) | Waren für die Flaschen-Abdichtung, nicht mehr nötig
Aihasd Regensensor LM393 2er-Pack (B017M1NJR0), 5,99 € | Ersetzt durch gleichwertigen Regensensor von Berrybase (1,80 €)
InLine Gummipuffer 12 mm, 20 Stk. (B09LDCTQGY), 5,45 € | Ersetzt durch Berrybase FIX&FASTEN Ø10 mm, 4 Stk. (0,60 €); nur 4 Stück nötig
MT3608 Step-up-Wandler (z. B. AZDelivery B07YWKN9NW) | Nicht genommen: Spannung per Poti, bei 3,7 → 5 V laut Rezensionen nur ca. 0,5 A; Angebot derzeit nicht verfügbar → Pololu S13V10F5
BTF-LIGHTING WS2812 ECO LED-Streifen 1 m, 60 LED/m, 10 mm (B088BRY2SH), 9,49 € | Ersetzt durch COB-Streifen BTF-LIGHTING WS2812B FCOB (B0H41MCVSW): einzelne LEDs als Punkte sichtbar und 10 mm breit; der COB-Streifen ist 5 mm schmal und gibt hinter der Diffusor-Leiste eine gleichmäßige Lichtlinie (26 statt 10 LEDs)
GERUI FET-Schaltmodul DC 5–36 V, 8er-Pack (B0DG8B58PM), 6,49 € | Ersetzt am 09.10.2026 (V4, Stromsparplan H1): schaltet nur Low-Side (GND) und ist mit 3,3 V am Gate unsicher. Jetzt P-MOSFET AO3401A (High-Side, Reichelt) mit Treiber BC547B; ein zweiter AO3401A schaltet mit dem Ein/Aus-Schalter den Akku (H2)

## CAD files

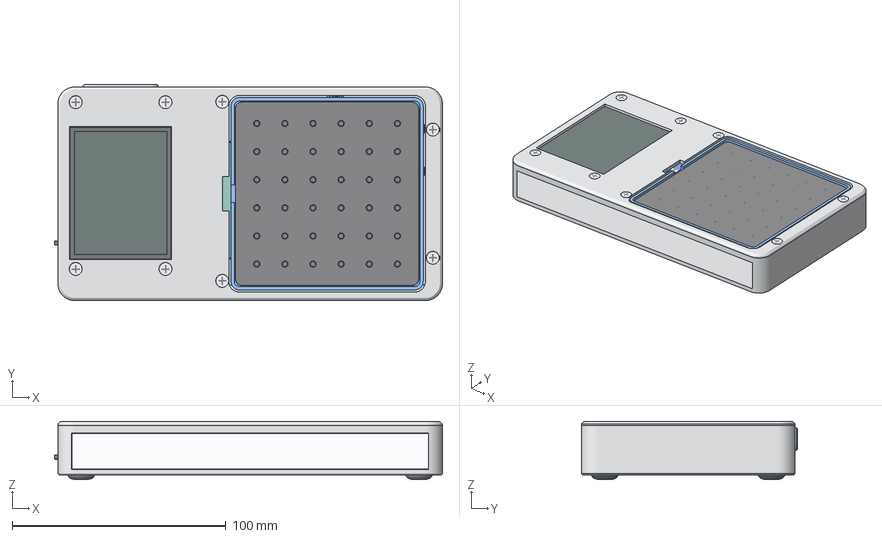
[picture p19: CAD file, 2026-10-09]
design/3d_modell/hydrodesk_komplett.3mf
181.6 x 101.2 x 27.2 mm
Gummifuesse
Schrauben_M5
Schrauben_M4
Schrauben_M3
Diffusor
COB-LED-Streifen
Waegezelle
Regensensor
HX711
Klemmkeile
Ein-Aus-Schalter
LM393
FET-Platine
TC4056
Pololu-5V-Wandler
Akku
Display-Board
Silikonmatte
Abdeckkappe_USB
Flaschenplatte
Deckel
Unterschale

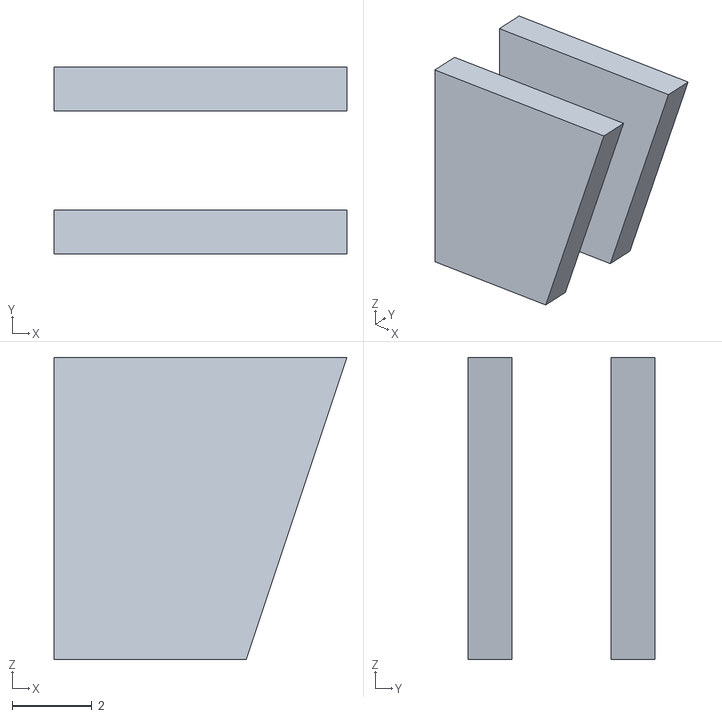
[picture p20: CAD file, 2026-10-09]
design/visualisierung/src/stl/keil.stl
7.36 x 4.70 x 7.60

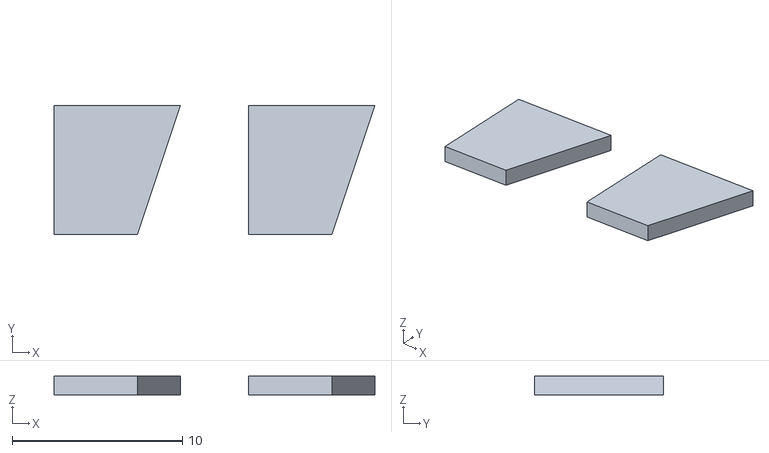
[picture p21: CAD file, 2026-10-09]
gehaeuse/stl/schalter_keile.stl
18.9 x 7.60 x 1.10

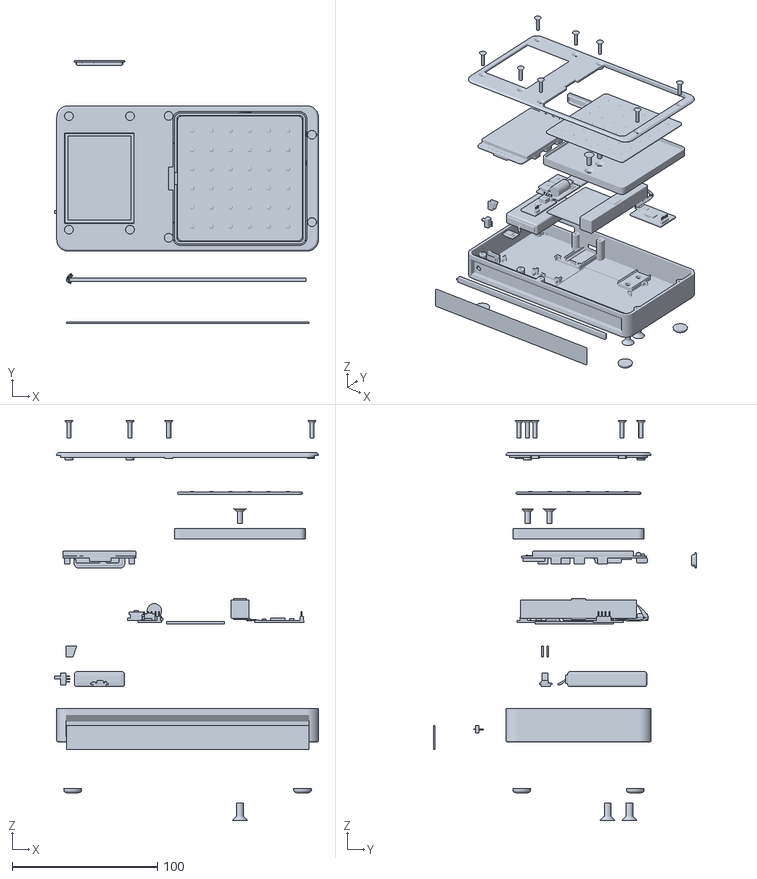
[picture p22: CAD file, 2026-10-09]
design/3d_modell/hydrodesk_explosion.stl
181.6 x 181.0 x 275.0

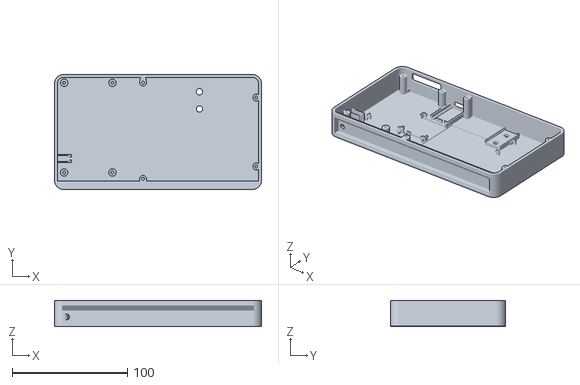
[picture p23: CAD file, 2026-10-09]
design/visualisierung/src/stl/base.stl
180.0 x 100.0 x 23.0

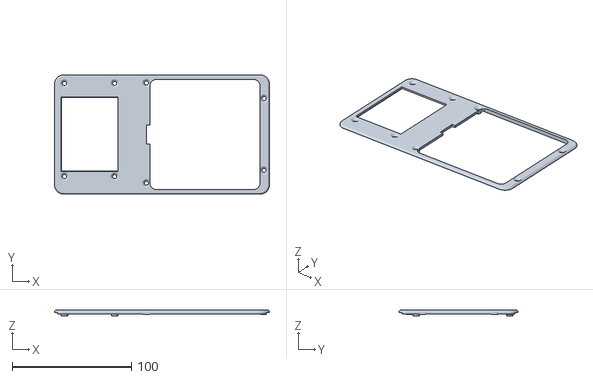
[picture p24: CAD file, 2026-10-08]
design/visualisierung/src/stl/cover.stl
180.0 x 100.0 x 5.10

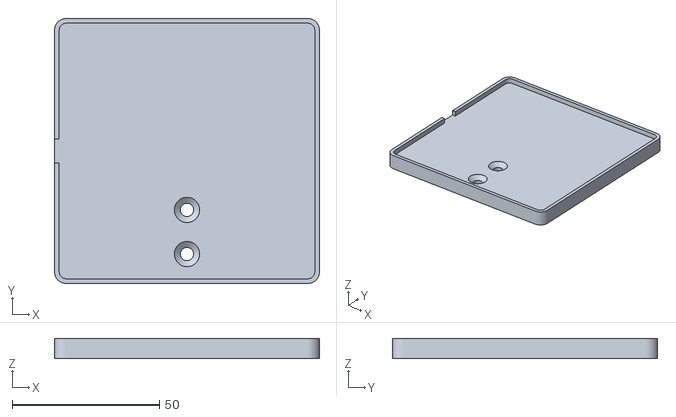
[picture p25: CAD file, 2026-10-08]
gehaeuse/stl/pad.stl
90.0 x 90.0 x 6.90

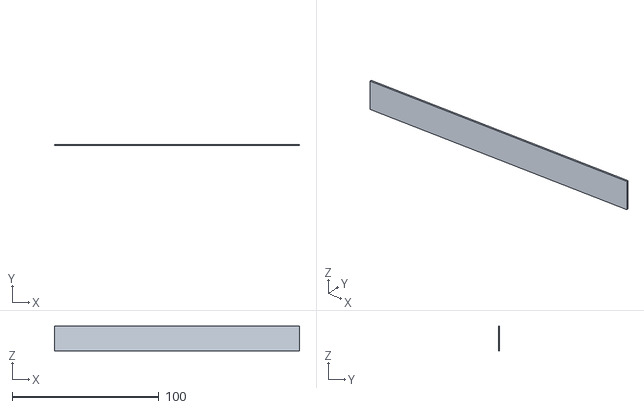
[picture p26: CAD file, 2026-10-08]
design/visualisierung/src/stl/diff.stl
166.7 x 1.00 x 16.7

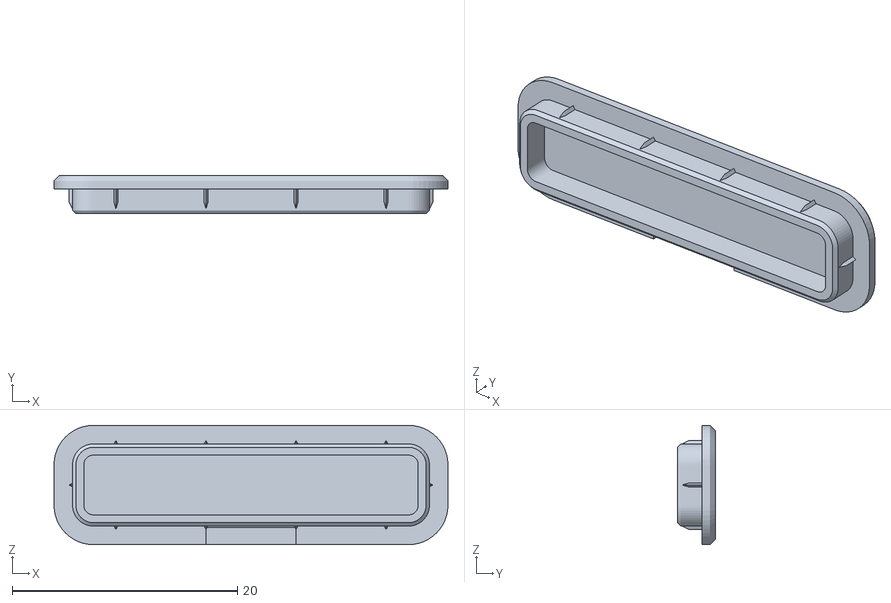
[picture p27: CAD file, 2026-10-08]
design/visualisierung/src/stl/cap.stl
35.0 x 3.40 x 10.6

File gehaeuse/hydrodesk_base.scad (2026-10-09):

// =====================================================================
//  SPDX-License-Identifier: CC-BY-NC-SA-4.0
//  Copyright (c) 2026 bekuz007 (https://github.com/bekuz007/hydrodesk-base) - siehe LICENSE
//  HydroDesk Base  -  parametrisches 3D-Druck-Gehaeuse (OpenSCAD)
//  Teile:  part = "base" | "cover" | "pad" | "cap" | "diffusor" | "keil" | "assembly" | "exploded"
//                 | "inside" (Boden + Bauteile, ohne Deckel/Pad) | "section" | "led_section"
//                 | "cap_check_cyd" / "cap_check_base" (Kollisionstests der Abdeckkappe)
//                 | "parts_check" / "diff_check" (Kollisionstests Bauteile / Diffusor, muessen LEER sein)
//                 | "keil_check" (Klemmkeile gegen Bodenwanne + Bauteile, muss LEER sein)
//                 | "sw_section" (Schnitt durch die Schalter-Tasche) | "sw_detail" / "sw_detail_offen" (Tasche + FET-Platine)
//  Koordinaten: X = Breite (links->rechts), Y = Tiefe (vorne=0 -> hinten),
//               Z = Hoehe (Tischflaeche = 0).  Alle Masse in mm.
//  Drucker: FDM, PLA, 0,4-mm-Duese.  Alle Teile ohne Stuetzmaterial.
// =====================================================================

part = "assembly";

$fn = 48;
e   = 0.01;          // kleiner Ueberstand fuer saubere Boolean-Schnitte

/* ===================== AUSSENMASSE ===================== */
W        = 180;      // Breite X
D        = 100;      // Tiefe Y  (95 gewuenscht -> 100 noetig, damit 90er Pad + 1 mm Spalt + 4 mm Rahmen passt)
H        = 25;       // Gesamthoehe inkl. Deckel (20 unmoeglich: Waegezelle 12,7 + Boden + Abstandshalter + Pad)
R_corner = 8;        // senkrechter Eckradius
wall     = 2.4;      // Wandstaerke (6 Bahnen a 0,4)
floor_t  = 2.0;      // Bodenstaerke
cover_t  = 2.0;      // Deckelplatte
top_chamfer = 1.2;   // weiche Oberkante (45-Grad-Fase am Deckel)
bot_chamfer = 0.6;   // kleine Fase unten (gegen "Elefantenfuss")
clr      = 0.3;      // allgemeines Spiel
base_h   = H - cover_t;   // Hoehe der Bodenwanne (Oberkante Wand) = 23

/* ===================== CYD  ESP32-2432S028R ===================== */
// Quelle: github.com/witnessmenow/ESP32-Cheap-Yellow-Display
//   OriginalDocumentation/3-Structure_Diagram/Dimensions.png  (50x86, Loecher 42x78, R1.6)
//   3dModels/Havenview_CYD_CAD/*.step (Gesamtdicke 9,8: Bauteile 4,7 | PCB 1,5 | LCD+Touch 3,6)
cyd_w        = 50;     // PCB Breite  (hier in X, Hochformat)
cyd_l        = 86;     // PCB Laenge  (hier in Y)
cyd_pcb_t    = 1.5;
cyd_hole_in  = 4.0;    // Lochmitte vom PCB-Rand (Lochabstand 42 x 78)
cyd_hole_d   = 3.2;    // M3
cyd_front_h  = 3.6;    // LCD + Touch ueber PCB-Oberseite
cyd_back_h   = 4.7;    // hoechste Bauteile auf der PCB-Rueckseite
cyd_tp_w     = 50;     // Touchpanel / LCD-Glas
cyd_tp_l     = 69.2;
cyd_aa_w     = 43.2;   // sichtbare Flaeche (active area)
cyd_aa_l     = 57.6;
cyd_aa_shift = 3.5;    // AA-Mitte liegt ca. 2,9-4,3 mm vom PCB-Zentrum weg vom USB-Ende (aus Zeichnung abgeleitet)
cyd_tp_shift = 0.7;    // LCD-Glas-Mitte ca. 0-1,4 mm weg vom USB-Ende
win_margin   = 1.5;    // Fenster = AA + 1,5 mm je Seite (deckt Toleranz der AA-Lage ab)
cyd_x        = 4.4;    // linke PCB-Kante
cyd_back_gap = 0.8;    // Abstand PCB-Hinterkante (USB-Seite) zur Innenwand
cyd_y        = D - wall - cyd_back_gap - cyd_l;     // vordere PCB-Kante (=10.8)
cyd_cx       = cyd_x + cyd_w/2;
cyd_cy       = cyd_y + cyd_l/2;
lcd_gap      = 0.3;    // Luft LCD-Oberseite <-> Deckel
lcd_recess   = 0.8;    // Tasche in der Deckel-Unterseite ueber dem LCD (Deckel dort nur 1,2 mm)
lcd_top_z    = base_h + lcd_recess - lcd_gap;          // 23.5
cyd_pcb_z    = lcd_top_z - cyd_front_h - cyd_pcb_t;    // PCB-Unterseite = 18.4
cyd_holes    = [ for (ix=[0,1]) for (iy=[0,1])
                 [cyd_x + cyd_hole_in + ix*(cyd_w-2*cyd_hole_in),
                  cyd_y + cyd_hole_in + iy*(cyd_l-2*cyd_hole_in)] ];
// USB-Ausschnitt hinten: breit genug fuer Micro-USB UND USB-C (2-USB-Variante) inkl. Stecker-Tuelle
cyd_usb_w    = 32;
cyd_usb_h    = 7.6;
cyd_usb_zc   = cyd_pcb_z - 1.6;
cyd_usb_r    = 2;      // Eckradius des USB-Ausschnitts

/* ===================== Abdeckkappe fuer den CYD-USB-Ausschnitt ===================== */
// Steckbare Kappe: verschliesst den grossen Programmier-Ausschnitt hinten (Kunde sieht ein
// geschlossenes Geraet). Der USB-C-Ladeanschluss des TC4056 bleibt offen.
cap_clr      = 0.15;   // Spiel Stopfen <-> Ausschnitt je Seite
cap_rand     = 1.5;    // Flansch steht je Seite so weit ueber den Ausschnitt
cap_flange_t = 1.2;    // Flanschdicke (steht aussen 1,2 mm vor)
cap_chamfer  = 0.5;    // Fase an der sichtbaren Flanschkante
cap_gap_in   = 0.2;    // Stopfen endet 0,2 mm VOR der Wand-Innenseite (USB-Buchse sitzt nur 0,8 mm dahinter)
cap_plug_d   = wall - cap_gap_in;   // Stopfentiefe = 2,2 mm
cap_shell    = 1.0;    // Wandstaerke des hohlen Stopfens (federt beim Einstecken etwas)
cap_rib_h    = 0.30;   // Quetschrippen: Hoehe ueber Stopfenflaeche -> 0,15 mm Uebermass je Seite
cap_rib_w    = 0.8;    // Rippenbreite an der Basis (Dreieckprofil)
cap_rib_x    = [-12, -4, 4, 12];    // Rippenlagen oben/unten (vom Ausschnitt-Mittelpunkt)
cap_notch_w  = 8;      // Fingernagel-Kerbe unten mittig im Flansch (Wandseite)
cap_notch_d  = 0.6;    // Kerbentiefe in die Flanschrueckseite
cap_pull     = 0;      // nur Vorschau: Kappe um so viele mm nach hinten herausgezogen
cap_fw = cyd_usb_w + 2*cap_rand;    // Flansch 35 x 10,6 mm
cap_fh = cyd_usb_h + 2*cap_rand;

/* ===================== LED-Linie vorne: COB-Streifen + Diffusor ===================== */
// BTF-LIGHTING WS2812B FCOB, 5 V, 160 LED/m, 5 mm breit, jede LED mit eigenem IC,
// teilbar alle 12,5 mm (2 LEDs).  13 Segmente = 162,5 mm = 26 LEDs.
// Aufbau von hinten nach vorne: Streifen auf der Kammer-Rueckwand -> Luftspalt (Licht mischt sich)
// -> Diffusor-Leiste (1 mm, weisses PLA / natur PETG, 100 % Infill) im Falz der Frontoeffnung.
cob_seg   = 12.5;  cob_n_seg = 13;
cob_len   = cob_seg * cob_n_seg;          // 162,5 mm
cob_leds  = 2 * cob_n_seg;                // 26 LEDs
cob_w     = 5;                            // Streifenbreite
cob_t     = 2.5;                          // Dicke inkl. Klebeband: nach Lieferung nachmessen! (typ. 1,5-2,5, hier ungünstigster Fall)
led_mix   = 2.0;                          // Luftspalt LED-Oberflaeche -> Diffusor-Rueckseite
diff_t    = 1.0;                          // Diffusor-Dicke
diff_clr  = 0.15;                         // Spiel Diffusor <-> Falz je Seite (Klebepunkte / leicht einpressen)
falz_t    = diff_t + 0.2;                 // Falztiefe 1,2: Diffusor liegt 0,2 mm hinter der Frontflaeche
falz_rand = 1.0;                          // Falz oben/unten breiter als die Lichtoeffnung (Auflage + Klebepunkte)
led_x0 = 6.5; led_x1 = 173.5;             // Lichtkammer 167 mm lang (Streifen 162,5 + je 2,25 mm Luft)
led_z0 = 3.5; led_hb = 10.5;              // Kammerboden, Hoehe der Rueckwand (Streifen mittig)
led_d  = falz_t + led_mix + cob_t;        // Kammertiefe ab Frontflaeche = 5,7 (vorher 3,5)
led_win_top = led_z0 + led_hb + (led_d - falz_t);   // Oberkante Lichtoeffnung (45-Grad-Dach) = 18,5
falz_z0 = led_z0 - falz_rand;             // Falz unten  = 2,5
falz_z1 = led_win_top + falz_rand;        // Falz oben   = 19,5
diff_l = led_x1 - led_x0 - 2*diff_clr;    // Diffusor 166,7 mm lang
diff_h = falz_z1 - falz_z0 - 2*diff_clr;  // Diffusor 16,7 mm hoch
cob_x0 = (led_x0 + led_x1 - cob_len)/2;   // Streifen mittig in der Kammer
cob_z  = led_z0 + led_hb/2;               // Streifenmitte (z = 8,75)
front_in = led_d + 1.6;                   // Innenseite der verdickten Frontwand = 7,3
// Oberkante der Verdickung: das 45-Grad-Dach der Kammer bleibt ueberall >= 1,6 mm dick
front_thick_top = ceil(led_z0 + led_hb + led_d - wall + 1.6*sqrt(2));   // = 20
cov_front_y = led_d + 2.25 + screw_pilot_d()/2;   // vordere Deckel-Schraubdome: 2,25 mm Wand zur Lichtkammer
function screw_pilot_d() = 2.5;
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

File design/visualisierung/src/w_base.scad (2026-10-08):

use <../../../gehaeuse/hydrodesk_base.scad>
base();

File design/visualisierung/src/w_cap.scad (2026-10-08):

use <../../../gehaeuse/hydrodesk_base.scad>
cap();

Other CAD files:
gehaeuse/stl/base.stl
gehaeuse/stl/diffusor_led.stl
design/visualisierung/src/stl/pad.stl
gehaeuse/stl/cover.stl
gehaeuse/stl/kappe_usb.stl
design/visualisierung/src/w_cover.scad
design/3d_modell/hydrodesk_komplett.stl
design/visualisierung/src/w_diff.scad
design/visualisierung/src/w_keil.scad
design/visualisierung/src/w_pad.scad

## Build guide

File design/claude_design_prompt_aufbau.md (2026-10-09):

# Claude Design Prompt – Aufbau & Einzelteile (HydroDesk Base)

Diesen Block komplett in Claude Design einfügen.

```
Create a technical product presentation (multiple boards/pages) that explains HOW the device "HydroDesk Base" is built and assembled. Style: clean technical illustration like an IKEA/Apple teardown manual, light grey background, isometric and top views, every part labeled with a thin leader line. All labels and texts in GERMAN.

HARD RULES (do not break):
- The housing is a RECTANGLE, landscape: 180 mm wide × 100 mm deep × 25 mm high, corner radius 8 mm. NOT round, NOT square.
- The touch display is on the LEFT side, portrait orientation.
- The bottle pad (90 × 90 mm, blue) is on the RIGHT side, next to the display. The bottle stands on the pad, never on the display.
- No bottle is part of the product. Show any generic bottle only as a transparent ghost on the pad.

TOP VIEW LAYOUT:
+----------------------------------------------------------+
|  [ DISPLAY  ]  |  middle  |  [                       ]   |
|  [ portrait ]  |  strip   |  [   BOTTLE PAD 90x90    ]   |
|  [  ~80 mm  ]  |          |  [   (blue, floating)    ]   |
|  [   zone   ]  |          |  [                       ]   |
+----------------------------------------------------------+
|  Light line along the FRONT edge: COB LED strip (26 LEDs)|
|  behind a milky printed diffuser – one even glowing line |
USB openings are on the BACK edge (left half): the wide programming opening of the display board is closed by a small removable plug-in cap, the USB-C charging opening stays open.

PARTS (show each one separately on a "Teileübersicht" board, with name, size and one-line function):
1. Unterschale (base): 3D-printed PLA tub, 180×100×23 mm, internal standoffs, pockets for all modules, 4 rubber-feet recesses underneath.
2. Deckel (cover): thin 5 mm frame, display window on the left, large opening on the right for the pad, 8 countersunk M3 screws.
3. Flaschenplatte (pad): 90×90×7 mm, blue, small drip rim, rests ONLY on the load cell (1 mm gap all around, it floats).
4. Silikonmatte: 86×86 mm, dark grey, glued on top of the pad.
5. ESP32-Touch-Display-Board ("Cheap Yellow Display", 2.8", 50×86 mm, yellow PCB, screen on top): brain + touchscreen in one, mounted portrait on 4 standoffs in the LEFT zone, USB end facing the back.
6. LiPo-Akku 3.7 V 2000 mAh (34×55×10 mm): lies UNDER the display board.
7. 5-V-Wandler Pololu S13V10F5 (tiny board 12×9 mm): in a 37×17 mm bay next to the battery under the display.
8. TC4056 USB-C-Lademodul (26×17 mm): middle strip, against the back wall at the USB-C opening.
9. FET-Platine (small self-soldered perfboard 30×24.5 mm, green, with 2 tiny MOSFETs AO3401A on purple adapter boards, a black transistor BC547B, resistors and a blue lying capacitor 470 µF): middle strip, partly under the display board – switches the LED strip's 5 V (off when dark or when water is detected) and, together with the on/off switch, the battery.
10. Regensensor (LM393 comparator board + sensor plate 40×54 mm): sensor plate in a floor pocket under a 3 mm slit next to the pad; overflow from the pad's drip notch drips onto it.
11. Wägezelle 5 kg (aluminium bar 80×12.7×12.7 mm, silver): centred under the pad, fixed at the BACK end to the base (2× M5 from below), the pad is screwed to the FRONT free end (2× M4) – cantilever, so it can bend.
12. HX711 (34×21 mm, green): next to the load cell under the pad.
13. COB-LED-Streifen WS2812B (26 LEDs, 162.5 × 5 mm, continuous light, no visible single dots): glued onto the back wall of the light chamber along the front edge.
14. Gummifüße ×4, Schrauben (8× M3×12, 2× M5×12, 2× M4×10).
15. Abdeckkappe USB (cap): small 3D-printed PLA plug-in cap, 35×10.6×3.4 mm, same colour as the housing, pressed into the wide USB opening at the back (covers the display board's programming port), pull notch at the bottom.
16. Diffusor-Leiste: 3D-printed white PLA strip, 166.7 × 16.7 × 1 mm, sits almost flush in a rebate at the front, in front of the LED strip, and turns it into one even line of light.
17. Ein/Aus-Schalter (tiny slide switch C&K OS102011MS2QN1, 8.6×4.3×4 mm, silver with black slider): in a pocket in the LEFT side wall near the front; only the slider (2 mm) shows through a small slot, engraved "AN" above and "AUS" below (slider up = on).
18. Klemmkeile ×2: two tiny 3D-printed PLA wedges (7.6 × 7.4 × 1.1 mm) pushed in behind the switch to hold it.

BOARDS TO CREATE:
A) "Produkt" – hero isometric of the closed device: display on the left showing "1.250 / 2.000 ml" with a progress bar, ghost bottle on the right pad, the front light line glowing evenly blue through the milky diffuser (one smooth line, no dots).
B) "Teileübersicht" – all 18 parts laid out flat, labeled, roughly to scale.
C) "Explosionsansicht" – vertical exploded view in this order from bottom to top: Gummifüße, Diffusor-Leiste + COB-LED-Streifen (pulled out to the front) → Unterschale → Akku + Pololu-5-V-Wandler → Display-Board / Wägezelle + HX711 / Lademodul + FET-Platine + Regensensor / Ein/Aus-Schalter + 2 Klemmkeile (left wall) → Flaschenplatte → Silikonmatte → Deckel. Dashed lines show where each part goes.
D) "Innenansicht" – top view of the open base WITHOUT cover: where every module sits (color code: display yellow, load cell silver, HX711 green, charger blue, FET-Platine green with purple adapters, on/off switch silver in the left wall, rain sensor teal, battery dark grey), cable paths as thin colored lines.
E) "Aufbau in 6 Schritten" – six numbered small isometric panels:
   1. Gummifüße unten aufkleben
   2. Wägezelle hinten mit 2× M5 an der Unterschale festschrauben, HX711 daneben
   3. Akku, 5-V-Wandler, Lademodul, FET-Platine und Regensensor einsetzen, Ein/Aus-Schalter links in die Wand-Tasche schieben und mit 2 Klemmkeilen sichern
   4. Display-Board auf die Abstandshalter links legen, Kabel anstecken
   5. Flaschenplatte vorne mit 2× M4 auf die Wägezelle schrauben, Silikonmatte aufkleben, COB-LED-Streifen in die Lichtkammer kleben und Diffusor-Leiste vorne einsetzen
   6. Deckel auflegen und mit 8× M3 verschrauben (4 Schrauben halten gleichzeitig das Display-Board), Abdeckkappe hinten einstecken
F) "Schnitt" – side cross-section through the pad showing: floor → load cell (fixed back, free front) → pad floating with 1 mm gap → silicone mat; and through the display zone: battery under the display board under the cover window.
G) "Verkabelung" – simple block diagram: ESP32-Display-Board in the centre, connected to HX711 (→ Wägezelle), COB-LED-Streifen WS2812B (26 LEDs, 330–470 Ω in der Datenleitung), Regensensor, FET-Platine (GPIO18 → BC547B → P-MOSFET Q1 → 5 V des LED-Streifens), Akku → TC4056 → P-MOSFET Q2 (Gate am Ein/Aus-Schalter) → Pololu-5-V-Wandler → Board + (über Q1) LED-Streifen. Use arrows and short German labels.
H) "Bedienung" – three display screens in portrait: (1) Flaschengröße wählen: Leer / 300 / 500 / 750 / 1000 / 1500 ml / Voll; (2) Tagesfortschritt with ml and goal; (3) red warning screen "WASSER ERKANNT · STROM AUS". Plus an LED color legend: blau = trinken, grün = Ziel erreicht, rot = Akku/Fehler, Wasser erkannt = Streifen aus (stromlos), Warnung nur auf dem Display.

SELF-CHECK before finishing: Is the body a 180×100 rectangle? Is the display on the LEFT? Is the pad on the RIGHT next to it? Is the load cell under the pad only? Are all labels German? If any answer is no, fix it.
```

Korrektur-Satz, falls es wieder rund wird:
`Wrong: the body must be a 180 × 100 mm rectangle, display LEFT, bottle pad RIGHT – redo all boards.`

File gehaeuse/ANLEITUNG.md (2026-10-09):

# HydroDesk Base – Gehäuse zum 3D-Drucken

Diese Anleitung erklärt alles, was du brauchst, um das Gehäuse drucken zu lassen und zusammenzubauen.
Du musst **nichts konstruieren**: Die STL-Dateien sind fertig zum Drucken.

---

## 1. Was ist was? (Dateien)

| Datei | Was ist das? | Wie oft drucken? |
|---|---|---|
| `stl/base.stl` | **Bodenwanne**: Boden mit allen Haltern, Lichtkammer für den LED-Streifen vorne (mit Falz für den Diffusor), USB-Öffnungen hinten, Mulden für die Gummifüße | **1×** |
| `stl/cover.stl` | **Deckel**: mit Display-Fenster und Öffnung für das Pad | **1×** |
| `stl/pad.stl` | **Flaschen-Pad**: 90 × 90 mm Platte, liegt nur auf der Wägezelle | **1×** |
| `stl/kappe_usb.stl` | **Abdeckkappe**: steckbarer Deckel für die breite USB-Öffnung des Displays hinten (Programmier-Anschluss) | **1×** (am besten 2×, falls eine verloren geht) |
| `stl/diffusor_led.stl` | **Diffusor-Leiste**: 166,7 × 16,7 × 1 mm, wird vorne in den Falz vor den LED-Streifen gesetzt und macht aus den einzelnen LEDs eine gleichmäßige Lichtlinie | **1×** (weißes PLA oder naturfarbenes PETG, siehe Abschnitt 3) |
| `stl/schalter_keile.stl` | **2 Klemmkeile** (je 7,6 mm lang, 1,1 mm dick) für den Ein/Aus-Schalter: werden von oben hinter den Schalter gedrückt und halten ihn in seiner Tasche (Abschnitt 7b) | **1×** (= 2 Keile; am besten 2× drucken, dann hast du Ersatz) |
| `hydrodesk_base.scad` | Die „Bauzeichnung“ für OpenSCAD. Hier stehen alle Maße oben als Zahlen. Nur nötig, wenn etwas geändert werden muss. | – |
| `preview/*.png` | Vorschaubilder (Zusammenbau, Explosionsansicht, Draufsicht, Einzelteile, Abdeckkappe `kappe_eingesteckt.png` / `kappe_offen.png`, Diffusor `17_teil_diffusor_druckLage.png`, `diffusor_eingesetzt.png`, `diffusor_offen.png`, Schnitt durch die Lichtkammer `18_led_kammer_schnitt.png`, Klemmkeile `19_teil_keile_druckLage.png`, Ein/Aus-Schalter von außen `20_schalter_links_aussen.png`, Schnitt durch die Schaltertasche `21_schalter_tasche_schnitt.png`, Tasche mit Schalter und Keilen `22_schalter_tasche_innen.png`, Einsetzen `23_schalter_einsetzen.png`, FET-Platine `24_fet_platine.png`) | – |
| `quellen/` | Maßzeichnungen, die für die Konstruktion benutzt wurden (CYD, Wägezelle) | – |
| `render.sh` | Skript, das die Vorschaubilder neu erzeugt (nur für Fortgeschrittene) | – |

**Abstandshalter für die Wägezelle musst du nicht extra drucken** – sie sind schon eingebaut
(Sockel im Boden + Sockel unter dem Pad).

---

## 2. Maße des fertigen Geräts

* **180 mm breit × 100 mm tief × 25 mm hoch** (mit Gummifüßen ca. 3 mm höher)
* Links: Display (Hochformat), rechts: Flaschen-Pad 90 × 90 mm
* Höhe 25 mm statt 20 mm, weil die Wägezelle allein schon 12,7 mm hoch ist:
  Boden 2 + Sockel 3 + Wägezelle 12,7 + Pad 4,6 + Tropfrand 2,3 = 24,6 mm.
  Mit 20 mm geht es nicht.
* Tiefe 100 mm statt 95 mm, weil das Pad 90 mm groß ist und rundherum 1 mm Luft
  und ein Deckelrand von 4 mm gebraucht werden (90 + 2 + 8 = 100).

---

## 3. Druckeinstellungen (für dich oder für die Druckerei)

Für alle Teile gilt (Ausnahme Diffusor, siehe unten):

| Einstellung | Wert |
|---|---|
| Material | **PLA** |
| Düse | 0,4 mm |
| Schichthöhe | **0,2 mm** |
| Füllung (Infill) | **20 %** |
| Wände (Perimeter) | **3** |
| Stützmaterial (Supports) | **Nein** – bei keinem Teil nötig |
| Druckbett-Haftung | normal (kein Brim nötig; bei Problemen Brim 5 mm) |

Wie die Teile auf dem Druckbett liegen – **die STL-Dateien sind schon richtig gedreht**, einfach so lassen:

| Teil | Lage auf dem Druckbett | Supports | Geschätzte Druckzeit* | Filament* |
|---|---|---|---|---|
| base | Boden nach unten (offene Seite oben) | nein | ca. 5 h 20 min*** | ca. 80 g*** |
| cover | **Oberseite nach unten** (schöne glatte Sichtfläche) | nein | ca. 1 h 06 min | ca. 16 g |
| pad | flache Unterseite nach unten, Rand oben | nein | ca. 1 h 26 min | ca. 27 g |
| kappe_usb | **Sichtseite (Flansch) nach unten**, Stopfen zeigt nach oben | nein | ca. 10 min** | ca. 1 g** |
| diffusor_led | **flach** liegend (1 mm dünne Platte) | nein | ca. 15 min** | ca. 4 g** |
| schalter_keile | **flach** liegend (die Keilform ist von oben zu sehen) | nein | ca. 5 min** | unter 1 g** |

\* Schätzung von PrusaSlicer 2.9 mit einem allgemeinen PLA-Profil (0,2 mm, 20 %, 3 Wände).
Dein Drucker kann schneller oder langsamer sein.
\*\* Kappe und Diffusor: grob aus dem Volumen geschätzt (Kappe 0,57 cm³, Diffusor 2,78 cm³ bei 100 % Füllung), nicht gesliced.
\*\*\* Bodenwanne mit der neuen Lichtkammer: aus dem Volumen hochgerechnet (+4,5 % gegenüber der gesliceten Version), nicht neu gesliced.
Die Schaltertasche (V4) macht die Bodenwanne noch einmal um 0,51 cm³ (+0,7 %) schwerer – das ändert an Zeit und Gewicht praktisch nichts.
Keile: 0,1 cm³ zusammen, ebenfalls nur aus dem Volumen geschätzt.

**Klemmkeile – Hinweise:** Die Teile sind sehr klein. Am besten zusammen mit der Abdeckkappe drucken,
Füllung egal (sie sind so dünn, dass sie ohnehin massiv werden). Falls sie sich vom Bett lösen: Brim 3 mm.

**Diffusor-Leiste – andere Einstellungen:**
* Material **weißes PLA** oder **naturfarbenes (milchiges) PETG** – kein farbiges oder schwarzes Filament, sonst kommt kein Licht durch.
* **1,0 mm dick, 100 % Füllung** (Infill 100 %), damit das Licht gleichmäßig durchscheint und keine Wabenmuster zu sehen sind.
* Flach auf das Druckbett legen (die STL liegt schon richtig). Die Seite, die auf dem Druckbett lag, ist glatter → sie zeigt später nach außen.

Hinweise:
* Der Boden ist 180 × 100 mm groß → das Druckbett muss mindestens ca. 190 × 110 mm haben (fast alle Drucker schaffen das).
* Unter dem Pad gibt es einen 15 mm breiten Kanal (über der Wägezelle). Das ist eine kurze „Brücke“ und
  druckt ohne Stützen. Falls ein Slicer davor warnt: ignorieren.

---

## 4. Einkaufsliste (Schrauben und Kleinteile)

| Anzahl | Teil | Wofür |
|---|---|---|
| 8 | **M3 × 12 Senkkopfschraube** (DIN 965 / ISO 7046, Kreuz oder Torx) | Deckel festschrauben. 4 davon gehen durch die Ecklöcher des Displays in die Abstandshalter und halten das Display gleich mit fest. |
| 2 | **M5 × 12 Senkkopfschraube** (DIN 7991, Innensechskant) | Wägezelle von **unten** am Boden festschrauben (feste Seite, M5-Löcher) |
| 2 | **M4 × 10 Senkkopfschraube** (DIN 7991, Innensechskant) | Pad von **oben** an der Wägezelle festschrauben (freie Seite, M4-Löcher) |
| 4 | **Gummifüße selbstklebend, Ø 12 mm** (max. 13 mm) | in die runden Mulden unten kleben |
| 1 | Silikonmatte, **auf 86 × 86 mm zuschneiden** (1–1,5 mm dick) | oben in das Pad kleben (innerhalb des Rands) |
| – | Doppelseitiges Klebeband (Schaumstoff) und/oder Heißkleber | Akku, Module, LED-Streifen festkleben; 2–4 kleine Klebepunkte (Glue Dots) für den Diffusor |
| – | Kabelbinder (klein), dünne Litze | Kabel ordnen |
| 1 | **Widerstand 470 Ω** (330–470 Ω geht) | in die Datenleitung direkt am Streifen-Eingang (DIN) löten |
| 1 | **Schiebeschalter C&K OS102011MS2QN1** (1× Um, 8,6 × 4,3 mm, Raster 2 mm) | Ein/Aus-Schalter in der linken Wand (Abschnitt 7b) |
| 1 | **Lochrasterplatine** (zuschneiden auf 30 × 24,5 mm) + Bauteile der Schaltung aus Abschnitt 7c | FET-Platine: LED-Strom-Schalter (H1) und Akku-Schalter (H2) |

Die M3-Schrauben drehen sich selbst ein Gewinde in den Kunststoff (Löcher 2,5 mm).
**Nicht zu fest anziehen**, sonst dreht das Gewinde im PLA durch.
(Wer lieber Gewindeeinsätze zum Einschmelzen benutzt: in der .scad-Datei `screw_pilot = 4.0` setzen
und neu exportieren – oder den Assistenten darum bitten.)

---

## 5. VOR dem Drucken: Bauteile nachmessen!

Händler-Angaben stimmen nicht immer. Bitte mit einem **Messschieber** nachmessen und mit dieser Tabelle vergleichen.
Wenn etwas um mehr als ca. 0,5 mm abweicht: die Zahl oben in `hydrodesk_base.scad` ändern
(oder dem Assistenten die gemessenen Werte schicken – er passt es an).

| Bauteil | Benutzte Maße | Parameter in der .scad |
|---|---|---|
| CYD ESP32-2432S028R (Platine) | 50 × 86 mm, 4 Löcher Ø 3,2 mm im Abstand **42 × 78 mm** (4 mm vom Rand) | `cyd_w`, `cyd_l`, `cyd_hole_in` |
| CYD Dicke | Bauteile hinten 4,7 mm + Platine 1,5 mm + Display/Touch 3,6 mm = 9,8 mm | `cyd_back_h`, `cyd_pcb_t`, `cyd_front_h` |
| CYD sichtbare Fläche | 43,2 × 57,6 mm, Mitte ca. 3,5 mm vom Platinen-Mittelpunkt weg vom USB-Ende | `cyd_aa_*`, `cyd_aa_shift` |
| CYD USB-Buchse(n) | an der kurzen Seite; Öffnung hinten 32 × 7,6 mm (passt für Micro-USB **und** USB-C) | `cyd_usb_w`, `cyd_usb_h` |
| Akku EEMB 2000 mAh (LP103454) | 34,5 × 56 × 10,3 mm (Datenblatt: 34,5 × 55 × 10,3, mit Kabelende 56) | `bat_w`, `bat_l`, `bat_h` |
| TC4056 USB-C Lader | 17 × 26 mm, USB-C mittig an der kurzen Kante | `tc_w`, `tc_l` |
| Wägezelle 5 kg | 80 × 12,7 × 12,7 mm; Löcher 5 mm und 20 mm von jedem Ende; 2× M4 an einem Ende, 2× M5 am anderen | `lc_*` |
| HX711 | 34 × 21 mm (kleinere Versionen passen auch) | `hx_w`, `hx_l` |
| FET-Platine (Lochraster, selbst gelötet) | **30 × 24,5 mm**, 1,6 mm dick, liegt auf 1,5 mm hohen Leisten; höchstes Bauteil der stehende SOT-23-Adapter / BC547B, der Elko (Ø 10 × 16 mm) liegt | `mos_w`, `mos_l`, `fb_*`, `elko_*` |
| Ein/Aus-Schalter C&K OS102011MS2QN1 | Gehäuse 8,6 × 4,3 mm, **Höhe 4,0 mm angenommen** (Datenblatt-Zeichnung unklar: 3,5–4,7 mm, Händler: 4 mm), Schieber 2,0 × 2,0 mm, 4,0 mm hoch, Weg 2,0 mm | `sw_l`, `sw_w`, `sw_h`, `sw_act*` |
| 5-V-Wandler Pololu S13V10F5 | 12,1 × 8,9 × 4,2 mm (das Fach ist 37 × 17 mm groß, der Wandler wird darin mit Klebeband fixiert) | `pol_w`, `pol_l`, `pol_h` (Fach: `boost_w`, `boost_l`) |
| Regensensor FC-37 / YL-83 | 40 × 54 mm | `rs_w`, `rs_l` |
| Regensensor-Auswertemodul (LM393) | 16 × 30 mm | `cmp_w`, `cmp_l` |
| COB-LED-Streifen BTF-LIGHTING WS2812B FCOB (5 V, 160 LEDs/m) | **5 mm breit**, 13 Segmente à 12,5 mm = **162,5 mm lang, 26 LEDs**; Dicke mit Klebeband **2,5 mm angenommen** | `cob_w`, `cob_len`, `cob_t` |
| Diffusor-Leiste (gedruckt) | 1,0 mm dick; Falz in der Lichtkammer 1,2 mm tief | `diff_t`, `falz_t` |

**Besonders wichtig beim CYD:** Prüfe, wo genau die USB-Buchse(n) sitzen und wie tief die Bauteile auf der
Rückseite sind. Die Öffnung hinten ist absichtlich breit, damit beide bekannten Varianten passen.

**Besonders wichtig beim COB-Streifen:** Die Dicke `cob_t` (Streifen + Klebeband) ist mit 2,5 mm als ungünstigster Fall
angenommen – **nach Lieferung nachmessen!** Aus `cob_t` wird die Tiefe der Lichtkammer berechnet
(`led_d` = Falz 1,2 + Mischabstand 2,0 + `cob_t` = 5,7 mm). Ist der Streifen dünner, wird der Abstand zum Diffusor
etwas größer – das schadet nicht, das Licht wird nur noch gleichmäßiger.

**Besonders wichtig beim Ein/Aus-Schalter:** Die Gehäusehöhe `sw_h` (Wand → Rückseite mit den Pins) **nachmessen**.
Die Keile gleichen bis ca. 0,5 mm Unterschied aus (bei 3,5 mm sitzen sie 1,5 mm tiefer, bei mehr als 4,3 mm passen sie nicht
mehr) – bei größerer Abweichung `sw_h` ändern und Bodenwanne + Keile neu exportieren.

---

## 6. Wo sitzt was? (Innen, von oben gesehen)

* **Linke Zone:** CYD-Display auf 4 Abstandshaltern, USB-Buchse zeigt **nach hinten** (zum Programmieren erreichbar).
  **Unter** dem Display: der Akku (hinten) und der 5-V-Wandler Pololu S13V10F5 (vorne, im Fach 37 × 17 mm).
* **Streifen zwischen Display und Pad:** TC4056-Lader an der Rückwand (USB-C zum Laden zeigt nach hinten),
  davor die **FET-Platine** (30 × 24,5 mm, Elko rechts liegend), ganz vorne das Auswertemodul des Regensensors.
* **Linke Wand vorne (Y = 27 mm, zwischen den Anschlägen des Wandler-Fachs):** der **Ein/Aus-Schalter** in seiner Tasche.
  Außen sieht man nur den Schieber im Schlitz 2,6 × 4,6 mm, darüber eingraviert **„AN“**, darunter **„AUS“**.
  Schieber **oben = AN**. Er sitzt weit weg vom Pad, damit kein Wasser hinkommt.
* **Rechte Zone (unter dem Pad):** Wägezelle längs (von vorne nach hinten) in der Mitte,
  rechts daneben der HX711, links daneben der Regensensor in einer flachen Mulde.
* **Vorne über die ganze Breite:** die Lichtkammer (167 mm lang, 5,7 mm tief). Der COB-LED-Streifen klebt an ihrer
  Rückwand, vorne sitzt die Diffusor-Leiste im Falz. Alle Module halten dazu Abstand (in OpenSCAD geprüft:
  `part = "parts_check"`, `part = "diff_check"` und `part = "keil_check"` sind leer).
* Zwischen den Zonen gibt es keine Trennwand → Kabel können frei verlegt werden.
* Hinten gibt es also **zwei** Öffnungen: links die breite für das CYD (Programmieren),
  rechts daneben die kleine USB-C-Öffnung für den Lader.
  Die kleine Öffnung hat außen eine Mulde, damit auch dicke Stecker ganz hineinpassen.
* Die breite CYD-Öffnung wird im fertigen Gerät mit der **Abdeckkappe** verschlossen (siehe Abschnitt 7a).
  Zum Programmieren Kappe abziehen, danach wieder einstecken. Die USB-C-Ladebuchse bleibt immer offen.

**Wasser-Erkennung (einfache Lösung):** Das Pad hat einen Tropfrand. Auf der linken Seite (zum Display hin)
hat der Rand eine kleine **Kerbe**. Läuft Wasser auf dem Pad über, läuft es dort ab, tropft durch den
**3-mm-Schlitz** im Deckel direkt auf den **Regensensor**, der darunter in einer Mulde im Boden liegt.
Der Sensor meldet „nass“ → das ESP32 kann warnen. Danach Sensor und Mulde trocken wischen.
Tipp: Beim Regensensor die Stiftleiste abgewinkelt lassen oder Kabel direkt anlöten (nicht höher als ca. 12 mm).

---

## 7. Zusammenbau – Schritt für Schritt

1. **Drucken** und Teile säubern (Fäden entfernen).
2. **Gummifüße** unten in die 4 runden Mulden kleben.
3. **Wägezelle einbauen:** Die Seite mit dem **Kabel und den M5-Löchern** kommt **hinten** auf den Sockel im Boden.
   Von **unten** mit 2× M5 × 12 Senkkopf festschrauben. Der Pfeil auf der Wägezelle muss **nach unten** zeigen.
   Die vordere Hälfte der Zelle darf den Boden nicht berühren (ca. 3 mm Luft).
4. **HX711** rechts neben die Wägezelle kleben (Anschläge im Boden zeigen den Platz), Kabel anlöten.
5. **Regensensor** in die flache Mulde links neben der Wägezelle legen und mit wenig Heißkleber an den Ecken fixieren.
   Das LM393-Modul vorne in den Streifen kleben.
6. **TC4056** von vorne zwischen die beiden Leisten an der Rückwand schieben, bis die USB-C-Buchse in der Öffnung sitzt.
   Mit einem Tropfen Heißkleber sichern. Die fertig gelötete **FET-Platine** (Abschnitt 7c) davor auf die zwei Leisten legen
   und mit doppelseitigem Klebeband fixieren (der liegende Elko zeigt nach rechts, weg vom Display).
   **Ein/Aus-Schalter** mit angelöteten Litzen einsetzen und mit den 2 Klemmkeilen sichern (Abschnitt 7b).
7. **Akku** hinten links in die Anschläge legen (doppelseitiges Klebeband), den **5-V-Wandler (Pololu S13V10F5)** davor ins Fach kleben.
   Akku-Kabel zum TC4056 führen. Achtung Polarität!
8. **COB-LED-Streifen** (26 LEDs = 13 Segmente, 162,5 mm; nur an den markierten Schnittstellen alle 12,5 mm schneiden)
   vorbereiten: 3 Litzen (5 V, GND, Daten) an den **Eingang** (Pfeil zeigt vom Kabel weg) löten,
   in die Datenleitung direkt am Streifen einen **Widerstand 470 Ω** setzen.
   Die 5-V-Litze kommt später an den **Drain von Q1** auf der FET-Platine (nicht direkt an den Wandler), siehe 7c.
   Den Streifen mit seinem Klebeband an die **Rückwand der Lichtkammer** kleben, mittig (links und rechts je ca. 2 mm Platz),
   die LEDs zeigen nach vorne.
   Die Kabel gehen **um das linke Streifenende herum** durch das kleine Loch (Ø 5 mm) nach innen –
   das Loch liegt direkt hinter dem Streifenanfang, deshalb die Litzen vor dem Aufkleben durchstecken.
9. **Diffusor-Leiste** vorne in den Falz setzen (glatte Seite nach außen): 2–4 kleine Klebepunkte (Glue Dots) oder
   ein Hauch Kleber an den Rand, dann leicht andrücken. Sie liegt 0,2 mm vertieft in der Front.
   Wenn sie ohne Kleber stramm sitzt, reicht leichtes Eindrücken.
10. Alle Kabel an das **CYD** anstecken (Stecker P3, CN1, P1 usw. sitzen auf der Rückseite an den Längskanten –
   neben dem Akku ist dafür Platz). Kabel mit Kabelbindern ordnen.
11. **CYD** mit dem Bildschirm nach oben und der USB-Buchse nach hinten auf die 4 Abstandshalter legen.
12. **Deckel** auflegen (der Rand innen zentriert ihn). Mit 8× M3 × 12 Senkkopf festschrauben:
    4 Schrauben gehen durch die Ecklöcher des CYD in die Abstandshalter, 4 in die Dome im Boden.
    **Gefühlvoll anziehen.**
13. **Pad** von oben in die Öffnung legen. Die zwei Senklöcher müssen vorne über den M4-Löchern der Wägezelle liegen.
    Mit 2× M4 × 10 Senkkopf festschrauben. Prüfen: Das Pad darf **nirgends** den Deckel berühren
    (rundherum ca. 1 mm Spalt) – sonst misst die Waage falsch.
14. **Silikonmatte** auf 86 × 86 mm zuschneiden und innen in das Pad kleben (deckt die Schraubenköpfe ab).
15. **Abdeckkappe** hinten in die breite USB-Öffnung drücken, bis der Flansch an der Wand anliegt
    (die Kerbe im Flansch zeigt nach **unten**).
16. Fertig! Waage in der Software tarieren und kalibrieren (z. B. mit einer vollen 0,5-l-Flasche = ca. 500 g Wasser + Flasche).

### 7a. Abdeckkappe für den USB-Anschluss

| Maß | Wert |
|---|---|
| Flansch (außen sichtbar) | 35 × 10,6 mm, 1,2 mm dick, Ecken R 3,5, Kante 0,5 mm gefast – steht 1,2 mm über die Rückwand |
| Stopfen (steckt in der Wand) | 31,7 × 7,3 mm, 2,2 mm tief, hohl mit 1 mm Wand |
| Spiel Stopfen ↔ Öffnung (32 × 7,6 mm) | **0,15 mm je Seite** |
| Halt | 10 Quetschrippen (4 oben, 4 unten, je 1 links/rechts), 0,3 mm hoch → **0,15 mm Übermaß** je Seite; die Rippen drücken sich beim ersten Einstecken etwas zusammen und klemmen die Kappe |
| Abziehen | Kerbe 8 mm breit unten in der Flansch-Rückseite: Fingernagel hineinstecken und Kappe heraushebeln |
| Abstand zur USB-Buchse | Der Stopfen endet 0,2 mm **vor** der Wand-Innenseite und ist hohl. Die Buchse(n) liegen in der Höhe innerhalb des Hohlraums → keine Berührung (in OpenSCAD geprüft: `part = "cap_check_cyd"` ist leer) |

**Erst eine Kappe zur Probe drucken!** Jeder Drucker druckt etwas anders.
* Kappe zu locker → in der .scad `cap_rib_h` auf 0.35–0.4 erhöhen (mehr Übermaß).
* Kappe zu stramm → `cap_rib_h` auf 0.2 senken oder `cap_clr` auf 0.2 erhöhen.
* Eine Außenmulde für einen bündigen Flansch gibt es absichtlich nicht: Die Rückwand ist nur 2,4 mm dick,
  daneben blieben bei der breiten Öffnung nur ca. 1 mm Material stehen.

### 7b. Ein/Aus-Schalter einsetzen

Warum ein Schalter? Der 5-V-Wandler (Pololu S13V10F5) hat **keinen Enable-Eingang** und braucht auch ohne Last ca. 9–10 mA.
Ohne Schalter wäre der Akku auch im „Tiefschlaf“ nach einigen Tagen leer. Der kleine Schiebeschalter schaltet aber
**nicht** den Akku-Strom selbst (er verträgt nur 0,1 A), sondern nur das Gate eines P-MOSFET (Q2, Abschnitt 7c).
Durch den Schalter fließen nur ca. 0,08 mA.

| Maß | Wert |
|---|---|
| Position | linke Wand, 27 mm von der Vorderkante (Mitte), Unterkante Schalter 3 mm über dem Boden |
| Schlitz außen | 2,6 × 4,6 mm (Schieber 2,0 mm + 2 × 0,3 mm Spiel, Weg 2,0 mm), Ecken R 0,6 |
| Beschriftung | „AN“ über, „AUS“ unter dem Schlitz, 2,8 mm hoch, 0,5 mm tief eingraviert |
| Tasche | Seitenwangen 1,2 mm, Stufe 1 mm (Schalter liegt darauf), 0,3 mm Spiel je Seite; 2 Pfosten mit Gegenschräge 1 : 3 |
| Halt | 2 Klemmkeile (Steigung 1 : 3) zwischen Schalter-Rückseite und Pfosten; Mitte (Pins, Litzen) bleibt frei |

Schritte:
1. **Mit dem Durchgangsprüfer** (Multimeter) herausfinden, welcher äußere Pin mit dem mittleren verbunden ist,
   wenn der Schieber **oben** steht (= später „AN“). Diesen Pin markieren.
2. 3 Litzen (ca. 8 cm) anlöten, Lötstellen mit Schrumpfschlauch isolieren. Die zwei Befestigungslaschen nicht abbrechen.
3. Schalter mit dem Schieber **zur Wand** von oben in die Tasche setzen (ca. 4,4 mm vor der Wand auf die Stufe),
   dann **zur Wand schieben**, bis der Schieber außen durch den Schlitz schaut. Der Schieber muss **oben** bei „AN“
   und **unten** bei „AUS“ einrasten. Die Litzen zeigen nach innen (zwischen den beiden Pfosten durch).
4. Die 2 Klemmkeile von oben zwischen Schalter-Rückseite und Pfosten drücken (dünnes Ende nach unten, schräge Seite
   zum Pfosten), bis sie stramm sitzen. Sie halten den Schalter gegen die Wand; nach oben halten ihn Stufe und Schlitz
   (0,3 mm Spiel). Kein Kleber nötig – so kann der Schalter getauscht werden (Keile mit einer Pinzette herausziehen).
5. Schalter wackelt noch → Keile mit einem Tropfen Sekundenkleber an den Pfosten sichern, oder `k_k`/`k_z0` im .scad anpassen.

Alle Wege sind in OpenSCAD geprüft (Einsetzen, Schieben, Keile eindrücken, Schieber in Stellung „AUS“: keine Berührung).
Die Gehäusehöhe des Schalters ist aber nur angenommen (4,0 mm) → **vorher nachmessen** (Abschnitt 5).

### 7c. Schaltung FET-Platine (LED-Strom H1 + Ein/Aus H2)

Gelötet auf ein Stück Lochraster (30 × 24,5 mm). Die zwei AO3401A sind sehr klein (SOT-23) → jeweils auf einen
**SOT-23-Adapter** löten, dann wie ein normales Bauteil einstecken. Anschlüsse AO3401A (SOT-23): **1 = Gate, 2 = Source,
3 = Drain**. BC547B (TO-92, flache Seite zu dir, Beine unten): **C – B – E**.

**H2 – Ein/Aus (Akku → Rest des Geräts):**

| Von | Nach |
|---|---|
| TC4056 **OUT+** | **Source Q2** (AO3401A) |
| **Drain Q2** | Pololu **VIN** und oberer Widerstand des Akku-Teilers (2 × 10 kΩ, Mitte → GPIO35) |
| 47 kΩ | zwischen **Gate Q2** und **Source Q2** (hält Q2 aus, solange der Schalter umschaltet) |
| Schalter **Mitte** | **Gate Q2** |
| Schalter Außenpin „**AN**“ (Schieber oben) | **GND** (TC4056 OUT−) → Gate auf GND → Q2 leitet |
| Schalter Außenpin „**AUS**“ (Schieber unten) | **Source Q2** → Gate = Source → Q2 sperrt sicher |
| TC4056 **OUT−** | gemeinsames GND (Pololu, CYD, HX711, Streifen, Regensensor) |

* AUS: Wandler, CYD **und der Akku-Teiler** sind stromlos. Die Body-Diode von Q2 zeigt vom Gerät zum Akku und sperrt.
* Laden geht in beiden Stellungen (der TC4056 sitzt vor dem Schalter).
* Strom durch Schalter + 47 kΩ bei AN: ca. 79–89 µA (3,7–4,2 V / 47 kΩ).

**H1 – LED-Strom (5 V → Streifen):**

| Von | Nach |
|---|---|
| Pololu **VOUT** (5 V) | **Source Q1** (AO3401A) und **Elko 470 µF/25 V** (+), Elko (−) an GND – der Elko sitzt **vor** dem FET |
| **Drain Q1** | Streifen **5 V / +** |
| 10 kΩ | zwischen **Gate Q1** und **Source Q1** (Streifen standardmäßig aus) |
| BC547B **Kollektor** | **Gate Q1** |
| BC547B **Emitter** | GND |
| BC547B **Basis** | 4,7 kΩ → **GPIO18**; 47 kΩ Basis → GND |
| GPIO23 | 470 Ω **direkt am Streifen** → DIN |

* GPIO18 HIGH → BC547B zieht das Gate auf GND → Streifen hat 5 V. LOW oder hochohmig (Reset, Booten, Flashen) → aus.
* Die Firmware sendet vor dem Ausschalten Schwarz und lässt DIN danach LOW (kein Strom über die Datenleitung in den
  stromlosen Streifen).
* Warum GPIO18? Laut CYD-Schaltplan (macsbug, ESP32-2432S028) haben am SD-Slot CS (GPIO5), MOSI (GPIO23), MISO (GPIO19)
  und DAT1 je einen **10-kΩ-Pull-up** (Widerstandsnetz RN2), **CLK (GPIO18) aber nicht**. Darum hält der 47-kΩ-Widerstand
  Basis→GND den Streifen beim Booten sicher aus. GPIO18 erreichst du über den microSD-Sniffer (Pin CLK/SCK) oder den
  CLK-Lötpunkt am SD-Slot; keine SD-Karte einstecken.
* Folge des Pull-ups an GPIO23 (DIN): Solange die Firmware DIN auf LOW hält, fließen ca. 0,33 mA (3,3 V / 10 kΩ) –
  im Vergleich zu den 33–66 mA Durchschnitt vernachlässigbar.

**Zum Programmieren über die USB-Buchse des CYD:** Schalter auf **AUS**. Dann versorgt nur USB das CYD, und der Akku ist
über Q2 abgetrennt. Bei **AN** und eingestecktem USB liegen Pololu-Ausgang und USB-5 V parallel am 5-V-Netz – das war
auch in V3 schon so und ist **nicht geprüft**. Einmal messen: Schalter AUS, USB an → an Pololu VIN müssen ca. 0 V liegen
(keine Rückspeisung über den Wandler).

**Datenblattwerte (geprüft):**

| Bauteil | Wert | Was heißt das hier? |
|---|---|---|
| AO3401A (Alpha & Omega, Datenblatt Rev 3.1, Dez. 2023) | U_DS −30 V, I_D −4 A (25 °C), U_GS max ±12 V, U_GS(th) −0,5 … −1,3 V, R_DS(on) ≤ 60 mΩ bei −4,5 V, ≤ 85 mΩ bei −2,5 V, I_DSS ≤ 1 µA | Q1 (U_GS = −5 V): bei 0,12 A ca. 7 mV Verlust. Q2 (U_GS = −3,3 … −4,2 V): bei 0,5 A Spitze ca. 43 mV / 21 mW – kein Kühlkörper nötig |
| BC547B | I_C max 100 mA, Stromverstärkung 200–450 | Basisstrom ca. 0,54 mA, Kollektorstrom nur 0,5 mA (5 V / 10 kΩ) → sicher durchgeschaltet |
| C&K OS102011MS2QN1 | 1× Um, 0,1 A bei 12 V DC, Kontaktwiderstand ≤ 20 mΩ, 10 000 Schaltzyklen | schaltet nur die 0,08 mA des Gates – weit unter der Grenze |

**Vor dem ersten Einschalten prüfen (ohne CYD):** Akku an, Schalter AUS → an Pololu VIN 0 V. Schalter AN → VIN ≈ Akkuspannung.
GPIO18-Draht kurz an 3,3 V halten → Streifen-Plus hat 5 V; offen → 0 V.

---

## 8. Drucken lassen – so geht’s

**Möglichkeit A – Schule / FabLab / Makerspace (meist am günstigsten):**
Die sechs Dateien `base.stl`, `cover.stl`, `pad.stl`, `kappe_usb.stl`, `diffusor_led.stl`, `schalter_keile.stl` auf einen USB-Stick kopieren und diese Anleitung
(Abschnitt 3 Druckeinstellungen) zeigen. Material: PLA (Diffusor: weißes PLA oder naturfarbenes PETG, 100 % Füllung).

**Möglichkeit B – Craftcloud (craftcloud3d.com):**
1. Webseite öffnen → „Upload“ und die sechs STL-Dateien hochladen.
2. Material wählen: **PLA** (Verfahren FDM). Farbe nach Wunsch (z. B. Hellgrau / Weiß, Pad Blau). **Diffusor: Weiß**, Füllung 100 %.
3. Anzahl jeweils **1**.
4. Die Seite zeigt nun Angebote verschiedener Druckereien mit Preis und Lieferzeit → vergleichen und bestellen.

**Möglichkeit C – JLC3DP (jlc3dp.com):**
1. „Upload“ / „Instant Quote“ → STL-Dateien hochladen.
2. Verfahren **FDM**, Material **PLA** wählen.
3. Der Preis wird nach dem Hochladen angezeigt. Versandkosten und Lieferzeit (aus China) beachten.

Preise werden erst **nach dem Hochladen** angezeigt – sie hängen von Material, Farbe, Anbieter und Versand ab.

---

## 9. Etwas ändern? (nur bei Bedarf)

1. OpenSCAD installieren (kostenlos, openscad.org).
2. `hydrodesk_base.scad` öffnen. Oben stehen alle Maße mit Kommentaren.
3. Zahl ändern → **F6** (Rendern) → `Datei > Exportieren > STL`.
4. Ganz oben `part = "base";` (oder `"cover"`, `"pad"`, `"cap"`, `"diffusor"`) einstellen, um das jeweilige Teil zu exportieren.
   `"assembly"` zeigt alles zusammengebaut, `"exploded"` die Explosionsansicht, `"inside"` das Innere ohne Deckel,
   `"section"` einen Schnitt. `cap_pull = 14` zieht die Abdeckkappe in der Vorschau heraus, `diff_pull = 16` den Diffusor.
   `"led_section"` zeigt einen Schnitt durch die Lichtkammer.
   `"keil"` exportiert die 2 Klemmkeile (Druck-Lage), `"sw_detail"` / `"sw_detail_offen"` zeigen die Schaltertasche
   (fertig / beim Einsetzen), `"sw_section"` einen Schnitt durch die Tasche, `"keil_check"` muss leer sein.

Oder einfach dem Assistenten die gemessenen Werte schicken – er erzeugt neue STL-Dateien.

---

## 10. Quellen der Maße

* CYD-Maßzeichnung und 3D-Modell: github.com/witnessmenow/ESP32-Cheap-Yellow-Display
  (`OriginalDocumentation/3-Structure_Diagram/Dimensions.png`, `3dModels/Havenview_CYD_CAD/Cheap Yellow Display v16.step`)
* Wägezelle: Datenblatt TAL220 (SparkFun, HTC Sensor) – 80 × 12,7 × 12,7 mm, Löcher bei 5/20 mm, 2× M4 + 2× M5
* Akku: Datenblatt EEMB LP103454 (2000 mAh): 34,5 × 55 (56) × 10,3 mm
* Schiebeschalter: Datenblatt C&K OS-Serie (OS102011MS2QN1): Gehäuse 8,6 × 4,3 mm, Schieber 2,0 mm, Weg 2,0 mm, Raster 2,0 mm
* P-MOSFET: Datenblatt Alpha & Omega AO3401A Rev 3.1 (aosmd.com)

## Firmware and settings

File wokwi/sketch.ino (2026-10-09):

/*
 * ============================================================================
 *  HydroDesk Base – Wokwi-Simulation (ESP32, Arduino)          Version 4
 * ============================================================================
 *  SPDX-License-Identifier: PolyForm-Noncommercial-1.0.0
 *  Copyright (c) 2026 bekuz007 (https://github.com/bekuz007/hydrodesk-base) - siehe LICENSE
 * ============================================================================
 *  Schulprojekt FI-AE: Trink-Tracker für den Schreibtisch.
 *  Eine Flasche steht auf einem Pad über einer Wägezelle (HX711). Das Display
 *  zeigt Uhrzeit, Akku, heute getrunkene Menge, Tagesziel und Flascheninhalt.
 *  Touch-Tasten „Leer“ und „Voll“ auf dem Hauptbildschirm (Flaschen-Kalibrierung);
 *  Trinken/Nachfüllen wird weiter aus dem Gewicht abgeleitet.
 *  LED-Linie (COB-Streifen WS2812B, 26 LEDs hinter einer Diffusor-Leiste)
 *  leuchtet nur bei Ereignissen (Dauerlicht). Blinken NUR bei:
 *  Akku-Warnung (rot), Bluetooth sucht (weiß), Handy verbunden (2x lila).
 *  Oben rechts: Bluetooth-Symbol links neben dem Akku (neu in V3).
 *  Antippen des Symbols macht das Gerät 2 min für das Handy sichtbar (neu in V4).
 *  Ein Nässe-Sensor schaltet bei Wasser den Strom des LED-Streifens ab.
 *
 *  NEU IN V4 – STROMSPAREN (README Kapitel 18):
 *   - Display: hell -> nach 30 s gedimmt -> nach 2 min aus (RUHE), nachts nach 15 s aus
 *   - WLAN nur zum Uhr-Abgleich (Start, alle 6 h, Befehl "sync"), danach aus
 *   - Bluetooth nur in Fenstern (Start 2 min, Symbol antippen 2 min, 60 s nach dem Trinken)
 *   - CPU 80 MHz, auf dem echten CYD Light-Sleep in RUHE (Wecken alle 100 ms + Touch + Nässe)
 *   - LED-Streifen bekommt nur Strom, wenn er leuchtet (FET an GPIO18)
 *   - Akku-Prozent per LiPo-Tabelle, Schutzabschaltung bei leerem Akku
 *   - "stromsparen 0" = Verhalten wie Version 3 (zum Vergleichen)
 *
 *  Simulation (Wokwi)                      | Echte Hardware
 *  ----------------------------------------+---------------------------------
 *  ILI9341 + kapazitiver Touch FT6206 (I2C)| CYD ESP32-2432S028R:
 *                                          | ILI9341 + resistiver Touch XPT2046
 *  HX711-Schieberegler (0–5 kg)            | HX711 + 5-kg-Wägezelle
 *  Schiebeschalter "NÄSSE"                 | LM393-Regensensor, Ausgang DO
 *  Potentiometer "AKKU"                    | Akku über Spannungsteiler am ADC
 *  LED "LAST"                              | LED-Strom: P-MOSFET AO3401A (High-Side)
 *  LED "LICHT" an GPIO21 (PWM)             | Hintergrundlicht des Displays (PWM)
 *  LED-Streifen 26 Pixel                   | BTF-LIGHTING WS2812B FCOB, 26 LEDs
 *  WLAN "Wokwi-GUEST" + NTP                | Heim-/Schul-WLAN (secrets.h) + NTP
 *  Telegram: nur Serial-Ausgabe (Stub)     | Telegram-Bot über WLAN
 *  Bluetooth: per Serial-Befehl simuliert   | BLE (NimBLE), HYDRO_BLE 1
 *
 *  Sichtbare Touch-Tasten „Leer“ / „Voll“ (Haupt- und Kalibrier-Bildschirm).
 *  Optional: 3 s Langdruck oder Serial „kalib“ öffnet den Kalibrier-Bildschirm.
 *  Serieller Monitor (115200 Baud): "hilfe", "status", "reset",
 *  "gewicht 75", "groesse 180", "zeit 23:59",
 *  "kalib", "leer", "voll",
 *  "bt suchen", "bt verbunden", "bt getrennt", "bt aus",
 *  "sync" (Uhr-Abgleich per WLAN), "stromsparen 0" / "stromsparen 1"
 * ============================================================================
 */

// ----------------------------------------------------------------------------
//  HARDWARE-AUSWAHL
//  0 = Wokwi-Simulation (ILI9341 + FT6206, Adafruit-Bibliotheken)  <- Standard
//  1 = echtes CYD ESP32-2432S028R (TFT_eSPI + XPT2046_Touchscreen)
// ----------------------------------------------------------------------------
#ifndef HYDRO_CYD
  #define HYDRO_CYD 0
#endif

// ----------------------------------------------------------------------------
//  BLUETOOTH-AUSWAHL
//  0 = Bluetooth nur simuliert (Serial-Befehle "bt ...")  <- Standard für Wokwi
//      (Wokwi kann kein Bluetooth simulieren)
//  1 = echtes BLE mit der Bibliothek NimBLE-Arduino (Gerät heißt "HydroDesk")
//      Echtes Gerät: HYDRO_CYD 1 UND HYDRO_BLE 1. Speicher: siehe README Kapitel 16
//      Ab V4 Partition "Huge APP (3MB No OTA/1MB SPIFFS)" PFLICHT (Default 1,25 MB ist zu klein).
// ----------------------------------------------------------------------------
#ifndef HYDRO_BLE
  #define HYDRO_BLE 0
#endif

// ----------------------------------------------------------------------------
//  STROMSPAREN (neu in V4, README Kapitel 18, Stromsparplan)
//  1 = Energie-Automat AKTIV -> GEDIMMT -> RUHE, WLAN nur zum Uhr-Abgleich,
//      Bluetooth nur in Fenstern, CPU 80 MHz, Sparblau, LED-Strom nur bei Bedarf  <- Standard
//  0 = Verhalten wie Version 3 (zum Vergleichen und für die Fehlersuche).
//      Umschalten geht auch zur Laufzeit: Serial "stromsparen 0" / "stromsparen 1".
// ----------------------------------------------------------------------------
#ifndef STROMSPAREN
  #define STROMSPAREN 1
#endif
// Echter Light-Sleep nur auf dem echten CYD. Wokwi simuliert Light-Sleep und
// GPIO-Wecken nicht verlässlich -> dort läuft derselbe Energie-Automat ohne Schlaf.
#ifndef HYDRO_LIGHTSLEEP
  #define HYDRO_LIGHTSLEEP HYDRO_CYD
#endif
#if HYDRO_LIGHTSLEEP && !HYDRO_CYD
  #error "HYDRO_LIGHTSLEEP 1 geht nur zusammen mit HYDRO_CYD 1"
#endif

#include <Arduino.h>
#include <SPI.h>
#include <WiFi.h>               // WLAN (im ESP32-Kern enthalten)
#include <time.h>               // Uhrzeit / Datum
#include <sys/time.h>           // settimeofday() für die Ersatzuhr
#include <esp_sntp.h>           // Meldung "NTP-Zeit empfangen"
#include <Preferences.h>        // Einstellungen dauerhaft im Flash (NVS)
#include <HX711.h>              // Wägezellen-Verstärker
#include <Adafruit_NeoPixel.h>  // LED-Streifen WS2812
#include <esp_sleep.h>          // Light-Sleep / Deep-Sleep (im ESP32-Kern enthalten)
#include <driver/gpio.h>        // gpio_hold_en(): Pin-Pegel im Schlaf festhalten

#if HYDRO_BLE
  #include <NimBLEDevice.h>        // Bibliothek "NimBLE-Arduino" (h2zero), nur für echtes BLE
#endif

#if HYDRO_CYD
  #include <TFT_eSPI.h>            // Display-Pins stehen in User_Setup.h der Bibliothek
  #include <XPT2046_Touchscreen.h> // resistiver Touch des CYD
#else
  #include <Wire.h>
  #include <Adafruit_GFX.h>
  #include <Adafruit_ILI9341.h>
  #include <Adafruit_FT6206.h>
#endif

// ============================================================================
//  EINSTELLUNGEN (hier dürfen die Azubis Werte ändern)
// ============================================================================
// --- Profil für das Tagesziel (auch per Serial: "gewicht 75", "groesse 180")
const float    KOERPERGEWICHT_KG    = 70.0f;
const int      KOERPERGROESSE_CM    = 175;
const float    ML_PRO_M2            = 1500.0f; // Trinkmenge pro m² Körperoberfläche
const int      ZIEL_MIN_ML          = 1500;
const int      ZIEL_MAX_ML          = 3500;

// --- Erinnerung (Trink-Plan + Pause nach echtem Schluck)
// WOKWI_DEMO_ERINNERUNG 1 = kurze Zeiten für die Simulation (README).
// Auf dem echten Gerät: #define WOKWI_DEMO_ERINNERUNG 0 (oder vor dem Compile setzen).
#ifndef WOKWI_DEMO_ERINNERUNG
  #define WOKWI_DEMO_ERINNERUNG 1
#endif
#if WOKWI_DEMO_ERINNERUNG
  const uint32_t ERINNERUNG_PAUSE_MS       = 90UL * 1000UL;          // Demo: 90 s Pause nach ≥100 ml
  const uint32_t ERINNERUNG_MIN_ABSTAND_MS = 60UL * 1000UL;          // Demo: frühestens alle 60 s
  const uint32_t TRUNK_FENSTER_MS          = 20UL * 1000UL;          // Demo: 20 s für ≥100 ml-Fenster
#else
  const uint32_t ERINNERUNG_PAUSE_MS       = 75UL * 60UL * 1000UL;   // 75 min Pause nach ≥100 ml
  const uint32_t ERINNERUNG_MIN_ABSTAND_MS = 90UL * 60UL * 1000UL;   // frühestens alle 90 min
  const uint32_t TRUNK_FENSTER_MS          = 10UL * 60UL * 1000UL;   // ~10 min Trinkfenster
#endif
const float    TRUNK_RESET_MIN_ML         = 100.0f;  // ab so viel im Fenster: Pause starten
const float    SCHLUCK_OHNE_PAUSE_ML      = 40.0f;   // darunter: zählt, setzt Pause NICHT
const uint8_t  ERINNERUNG_MAX_PRO_TAG     = 6;       // höchstens so viele Erinnerungen/Tag
const int      RUHE_START_STUNDE          = 22;      // Ruhezeit 22:00 ...
const int      RUHE_ENDE_STUNDE           = 7;       // ... bis 07:00 (keine Erinnerungen)
// Zeitplan (Soll-Anteil am Tagesziel): 12:00 → 40 %, 16:00 → 70 %, 20:00 → 100 %
// (20:00 = ca. 2 h vor Ruhezeit). Erinnerung nur, wenn hinter diesem Plan.

// --- WLAN + Uhrzeit
// Wokwi: offenes Gast-WLAN "Wokwi-GUEST" auf Kanal 6 (ohne Passwort).
// Echtes Gerät: Zugangsdaten NICHT hier eintragen, sondern in eine Datei
// secrets.h auslagern (die nicht ins Git kommt), z. B.
//   #define WLAN_SSID_GEHEIM "MeinWLAN"
//   #define WLAN_PASS_GEHEIM "geheim"
const char*    WLAN_SSID            = "Wokwi-GUEST";
const char*    WLAN_PASS            = "";
const int      WLAN_KANAL           = 6;
const char*    ZEITZONE             = "CET-1CEST,M3.5.0,M10.5.0/3"; // Deutschland inkl. Sommerzeit
const char*    NTP_SERVER           = "pool.ntp.org";
const uint32_t NTP_WARTEZEIT_MS     = 10000;  // danach Ersatzuhr ab 12:00

// --- Waage (1 g Wasser ~ 1 ml)
const float    WOKWI_FAKTOR         = 0.42f;  // Rohwert pro Gramm im Wokwi-HX711 "5kg" (5 kg = 2100)
const float    KALIBRIER_GEWICHT_G  = 500.0f; // Referenzgewicht für die Kalibrierung
const float    FLASCHE_DA_G         = 40.0f;  // ab hier gilt "Flasche steht auf dem Pad"
const float    FLASCHE_WEG_G        = 25.0f;  // darunter gilt "Flasche abgehoben" (Hysterese)
const float    STABIL_TOLERANZ_G    = 6.0f;   // so viel darf das Gewicht schwanken und gilt trotzdem als ruhig
const uint32_t STABIL_MS            = 1500;   // so lange muss das Gewicht ruhig sein (Trinken)
const uint32_t KALIB_STABIL_MS      = 1000;   // Kalibrierung: ~1 s ruhiges Gewicht vor Übernahme
const float    MIN_SCHLUCK_G        = 15.0f;  // kleinere Abnahmen werden ignoriert (Rauschen)
const float    MIN_NACHFUELL_G      = 20.0f;  // ab dieser Zunahme gilt "nachgefüllt"
const float    NEGATIV_FEHLER_G     = -30.0f; // deutlich negatives Gewicht = Tara falsch

// --- Leergewicht der Flasche (wird automatisch gelernt, siehe leergewichtLernen())
const float    LEERGEWICHT_START_G  = 150.0f; // Startwert; übliche Flaschen wiegen leer 100–400 g
const uint32_t PAD_LEER_RESET_MS    = 60000;  // Pad so lange leer + deutlich anderes Gewicht ...
const float    ANDERE_FLASCHE_G     = 250.0f; // ... (mind. so viel Unterschied) = andere Flasche

// --- Nässe
const uint32_t TROCKEN_FREIGABE_MS  = 5000;   // so lange trocken -> Sperre hebt sich selbst auf

// --- Akku (in Wokwi: Potentiometer). Simulation: 0..4095 -> 3,0..4,2 V
const float    AKKU_LEER_V          = 3.0f;   // nur Wokwi: Poti ganz links
const float    AKKU_VOLL_V          = 4.2f;   // nur Wokwi: Poti ganz rechts
const float    AKKU_TEILER          = 2.0f;   // echt: Spannungsteiler 2 x 10 kΩ -> ADC sieht die halbe Akkuspannung
// Akku-Prozent aus der Spannung (neu in V4, statt linear 3,0..4,2 V):
// TYPISCHE Ruhespannungs-Kurve einer LiPo-Zelle (Literaturwert, Quelle: README Kapitel 18),
// NICHT am eigenen Akku gemessen. Nach dem Entladetest (Stromsparplan, Test H5) ersetzen.
const float    AKKU_TABELLE_V[]     = { 3.27f, 3.61f, 3.69f, 3.71f, 3.73f, 3.75f, 3.77f, 3.79f, 3.80f, 3.82f, 3.84f,
                                        3.85f, 3.87f, 3.91f, 3.95f, 3.98f, 4.02f, 4.08f, 4.11f, 4.15f, 4.20f };
const uint8_t  AKKU_TABELLE_P[]     = { 0, 5, 10, 15, 20, 25, 30, 35, 40, 45, 50,
                                        55, 60, 65, 70, 75, 80, 85, 90, 95, 100 };
const uint8_t  AKKU_TABELLE_N       = sizeof(AKKU_TABELLE_P) / sizeof(AKKU_TABELLE_P[0]);
static_assert(sizeof(AKKU_TABELLE_V) / sizeof(AKKU_TABELLE_V[0]) == sizeof(AKKU_TABELLE_P), "Akku-Tabelle: gleich viele Werte");
// Schutz bei leerem Akku: so lange unter AKKU_ABSCHALT_V -> Meldung, dann Tiefschlaf mit Timer
const float    AKKU_ABSCHALT_V      = 3.30f;  // Schätzwert, nach der Entlademessung anpassen
const uint32_t AKKU_ABSCHALT_MS     = 60000;  // 60 s lang darunter (kurze Einbrüche zählen nicht)
const uint32_t AKKU_LEER_MELDUNG_MS = 10000;  // "Akku leer - bitte laden" so lange zeigen
const uint32_t AKKU_LEER_SCHLAF_MIN = 15;     // im Tiefschlaf alle 15 min prüfen, ob geladen wird
const float    AKKU_WIEDERANLAUF_V  = 3.60f;  // erst ab dieser Spannung wieder normal starten (Erholung im Leerlauf)
const int      AKKU_WARN_PROZENT    = 20;     // darunter: Hinweis + 2x rot blinken
const int      AKKU_KRITISCH_PROZENT = 10;    // darunter: Balken "Bitte laden" + 4x rot blinken
const int      AKKU_HYSTERESE_PROZENT = 2;    // erst bei Schwelle + 2 % gilt die Warnung als vorbei
const uint8_t  AKKU_BLINK_WARN      = 2;      // Anzahl Blitze unter 20 %
const uint8_t  AKKU_BLINK_KRITISCH  = 4;      // Anzahl Blitze unter 10 %
const uint32_t AKKU_BLINK_AN_MS     = 300;    // Warnung <20 %: kurz blitzen
const uint32_t AKKU_BLINK_AUS_MS    = 300;
const uint32_t AKKU_BLINK_KRITISCH_AN_MS  = 650; // kritisch <10 %: normaler Takt (langsamer)
const uint32_t AKKU_BLINK_KRITISCH_AUS_MS = 650;
const uint32_t AKKU_WIEDERHOLUNG_MS = 10UL * 60UL * 1000UL; // Blinkmuster alle 10 min wiederholen (0 = nie)
const uint32_t AKKU_HINWEIS_MS      = 5000;   // Hinweis "Akku unter 20 %" so lange im Statusfeld

// --- LED-Streifen: leuchtet NUR bei Ereignissen, sonst Dauerlicht.
//     Blinken gibt es NUR bei: Akku-Warnung (rot), Bluetooth sucht (weiß),
//     Handy verbunden (2x lila). Alles andere leuchtet ruhig.
// --- Echte Hardware: BTF-LIGHTING WS2812B FCOB (COB-Streifen), 5 V, 160 LED/m, 5 mm breit,
//     jede LED mit eigenem IC, teilbar alle 12,5 mm (2 LEDs). Verbaut: 13 Segmente = 162,5 mm
//     = 26 LEDs hinter der Diffusor-Leiste vorne -> die ganze Frontlinie leuchtet gleichmäßig.
const uint8_t  LED_ANZAHL           = 26;
// Strombudget (5-V-Wandler Pololu S13V10F5, max. 1 A):
//   26 LEDs voll weiß (255)           ca. 0,49 A  (ungünstigster Fall, kommt im Programm nicht vor)
//   mit LED_HELLIGKEIT 60 (= 60/255)  höchstens ca. 0,12 A
//   + CYD (Display + ESP32 + WLAN/BLE) ca. 0,25–0,35 A  -> zusammen unter 0,5 A, genug Reserve.
//   LED_HELLIGKEIT darum höchstens 80 einstellen (ca. 0,15 A für die LEDs).
const uint8_t  LED_HELLIGKEIT       = 60;     // 0..255 (mittel), höchstens 80 (Strombudget, siehe oben)
static_assert(LED_HELLIGKEIT <= 80, "LED_HELLIGKEIT höchstens 80 (Strombudget 5-V-Wandler)");
const uint32_t LED_GRUEN_MS         = 10000;  // "Ziel erreicht" 10 s grün
const uint32_t LED_ROT_MS           = 5000;   // Waagen-Fehler: 5 s rot
// Erinnerung (V4): erst LED_ERINNERUNG_HELL_MS voll blau, danach ruhiges "Sparblau" (Dauerlicht)
const uint32_t LED_ERINNERUNG_HELL_MS = 2UL * 60UL * 1000UL;
const uint8_t  LED_HELLIGKEIT_SPAR  = 15;     // wirksame Helligkeit 0..255 für Sparblau
static_assert(LED_HELLIGKEIT_SPAR <= LED_HELLIGKEIT, "Sparblau darf nicht heller sein als normal");
// Blau-Wert für Sparblau: LED_HELLIGKEIT wird zusätzlich angewendet -> 255 * 15 / 60 = 64
const uint8_t  LED_SPARBLAU_WERT    = (uint8_t)((255U * LED_HELLIGKEIT_SPAR + LED_HELLIGKEIT / 2) / LED_HELLIGKEIT);
// LED-Strom (FET an GPIO18): nach dem Einschalten kurz warten, bevor Daten gesendet werden
const uint32_t LED_STROM_EINSCHWING_MS = 10;

// --- Bluetooth (Symbol oben rechts + LED-Status)
const bool     BT_START_SUCHEN      = true;   // beim Einschalten gleich nach dem Handy suchen (Demo)
const uint32_t BT_SUCH_TIMEOUT_MS   = 2UL * 60UL * 1000UL; // Start + Symbol antippen: so lange suchen, dann "nicht verbunden"
const uint32_t BT_SYNC_FENSTER_MS   = 60UL * 1000UL;       // V4: nach jedem Trinken/Nachfüllen still sichtbar (ohne Blinken)
const uint32_t BT_WEISS_AN_MS       = 500;    // Suchen: weiß blinken 500 ms an ...
const uint32_t BT_WEISS_AUS_MS      = 500;    // ... 500 ms aus
const uint8_t  BT_WEISS_WERT        = 90;     // gedimmtes Weiß: 0..255 je Farbkanal (zusätzlich LED_HELLIGKEIT)
const uint8_t  BT_LILA_ANZAHL       = 2;      // verbunden: genau 2x lila blinken, dann normal
const uint32_t BT_LILA_AN_MS        = 300;
const uint32_t BT_LILA_AUS_MS       = 300;
const uint32_t BT_NOTIFY_MS         = 1000;   // nur echtes BLE: Werte höchstens 1x pro Sekunde senden
const char*    BT_NAME              = "HydroDesk"; // so heißt das Gerät in der Bluetooth-Liste des Handys
// Eigene 128-Bit-UUIDs (zufällig erzeugt) für den HydroDesk-Dienst
const char*    BT_SERVICE_UUID      = "4f9a0001-6c1e-4b8e-9d6a-2b7c1e0a4d10";
const char*    BT_WERTE_UUID        = "4f9a0002-6c1e-4b8e-9d6a-2b7c1e0a4d10"; // lesen + notify: "1250/2750 ml"

// --- Stromsparen (V4). Nur wirksam mit STROMSPAREN 1 bzw. nach "stromsparen 1"
const uint32_t ANZEIGE_DIMMEN_NACH_MS    = 30UL * 1000UL;   // 30 s ohne Aktivität -> GEDIMMT
const uint32_t ANZEIGE_AUS_NACH_MS       = 2UL * 60UL * 1000UL; // 2 min ohne Aktivität -> RUHE (Display aus)
const uint32_t ANZEIGE_AUS_NACH_MS_NACHT = 15UL * 1000UL;   // in der Ruhezeit 22-7 Uhr schon nach 15 s aus
const uint8_t  LCD_HELL             = 255;    // PWM-Wert Hintergrundlicht 0..255 (AKTIV)
const uint8_t  LCD_GEDIMMT          = 40;     // ca. 16 % (GEDIMMT)
const uint32_t LCD_PWM_FREQ_HZ      = 5000;   // LEDC an GPIO21
const uint8_t  LCD_PWM_BITS         = 8;
const uint32_t RUHE_WECKTAKT_MS     = 100;    // Light-Sleep: Wecken passend zu 10 Waagen-Messungen pro Sekunde
const uint32_t CPU_MHZ              = 80;     // statt 240 MHz (offizielle Option "80MHz (WiFi/BT)")
const uint32_t WLAN_ABGLEICH_ALLE_MS     = 6UL * 60UL * 60UL * 1000UL; // Uhr-Abgleich alle 6 h
const uint32_t WLAN_ABGLEICH_OHNE_NTP_MS = 30UL * 60UL * 1000UL;       // noch nie NTP: alle 30 min versuchen
const uint32_t WLAN_ABGLEICH_TIMEOUT_MS  = 20UL * 1000UL;  // so lange WLAN + NTP versuchen, dann aufgeben
const bool     RUHE_PINS_HALTEN     = true;   // Light-Sleep: Pegel von GPIO18/21/22/23 festhalten (Test H8)
const bool     TOUCH_IRQ_NUTZEN     = true;   // CYD: PENIRQ (GPIO36) als Hinweis + Weckquelle

// --- Versteckter Service-Modus
const uint32_t LANGDRUCK_MS         = 3000;   // 3 s drücken -> Kalibrierung

// ============================================================================
//  PINS  (Tabelle mit CYD-Vorschlag: README.md)
// ============================================================================
const int PIN_TFT_SCK   = 14;
const int PIN_TFT_MISO  = 12;
const int PIN_TFT_MOSI  = 13;
const int PIN_TFT_CS    = 15;
const int PIN_TFT_DC    = 2;
const int PIN_TFT_RST   = 4;   // CYD: RST hängt an EN -> dort -1
const int PIN_TFT_LED   = 21;  // Hintergrundbeleuchtung (CYD: GPIO21)
const int PIN_TOUCH_SDA = 32;  // nur Wokwi: FT6206 über I2C
const int PIN_TOUCH_SCL = 33;
const int PIN_HX711_DT  = 27;  // CYD: Stecker CN1
const int PIN_HX711_SCK = 22;  // CYD: Stecker CN1 / P3
const int PIN_AKKU_ADC  = 35;  // nur Eingang, ADC1 (funktioniert auch mit WLAN)
const int PIN_NAESSE    = 19;  // LOW = nass (wie LM393-Modul DO)
const int PIN_LED_DATA  = 23;  // WS2812B Daten (DIN); echt: 330–470 Ω in Reihe direkt am Streifen-DIN
const int PIN_LAST      = 18;  // HIGH = Strom für den LED-Streifen an (NPN BC547B -> P-MOSFET AO3401A, High-Side)
const int PIN_TOUCH_IRQ = 36;  // nur CYD: XPT2046 PENIRQ (LOW = berührt), nur Eingang
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
void loop() {
  naesseLesen();          // 1. Sicherheit zuerst
  akkuLesen();
  waageLesen();
  uhrVerwalten();
  btVerwalten();
  touchAuswerten();       // 2. versteckte Bedienung
  zustandAktualisieren(); // 3. Zustandsautomat
  energieVerwalten();     //    V4: Display hell / gedimmt / aus
  ledsAktualisieren();    // 4. Ausgaben
  drawUI();
  serielleBefehle();
  wlanVerwalten();        //    V4: Uhr-Abgleich per WLAN
#if HYDRO_LIGHTSLEEP
  if (schlafErlaubt()) {  // V4: in RUHE bis zur nächsten Waagen-Messung schlafen
    leichtSchlafen();
    return;
  }
#endif
  delay(5);
}

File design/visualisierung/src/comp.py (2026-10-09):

# SPDX-License-Identifier: PolyForm-Noncommercial-1.0.0
# Copyright (c) 2026 bekuz007 (https://github.com/bekuz007/hydrodesk-base) - siehe LICENSE
import sys
from PIL import Image
def bg(w,h,c0=(196,199,203),c1=(150,154,160)):
    import numpy as np
    y,x=np.mgrid[0:h,0:w]; r=np.sqrt(((x-w*0.5)/(w*0.75))**2+((y-h*0.45)/(h*0.85))**2); r=np.clip(r,0,1)**1.4
    a=np.array(c0)[None,None,:]*(1-r[...,None])+np.array(c1)[None,None,:]*r[...,None]
    return Image.fromarray(a.astype('uint8'),'RGB')
if __name__=='__main__':
    im=Image.open(sys.argv[1]).convert('RGBA'); b=bg(*im.size).convert('RGBA'); b.alpha_composite(im); b.convert('RGB').save(sys.argv[2])

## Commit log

2026-10-06 Erster Stand HydroDesk Base: Doku, Gehäuse-CAD und Projektstruktur
    - doku/: Steckbrief und Vorkalkulation
    - design/: Prompt für Aufbau-/Teile-Illustrationen
    - gehaeuse/: OpenSCAD-Modell, STL-Dateien, Vorschaubilder, Anleitung, Quellen
    - firmware/ und wokwi/: Platzhalter (folgen)
    - README, MIT-Lizenz, .gitignore inkl. secrets.h
    [Vorkalkulation_HydroDesk_Base.xlsx, base.stl, cover.stl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]
2026-10-06 Wokwi V2: tastenloser Hauptbildschirm, Tagesziel aus Körperdaten, NTP-Uhr
    - Hauptbildschirm ohne Tasten: Flascheninhalt = Gewicht - automatisch
    gelerntes Leergewicht (Start 150 g, Nachfüll-Kandidat, Untergrenze,
    Reset bei anderer Flasche nach >60 s leerem Pad)
    - Service-Modus (Kalibrierung) nur per 3-s-Langdruck
    - Wasser-Sperre hebt sich nach 5 s trocken selbst auf
    - Tagesziel nach Mosteller: KOF x 1500 ml/m², auf 50 ml gerundet,
    1500-3500 ml; Serial "gewicht", "groesse", "reset", "zeit" (Preferences)
    - Neues Hochformat-Layout (Uhrzeit, Datum, Akku, Menge, Balken, Flasche,
    Erinnerung), nur geänderte Bereiche werden neu gezeichnet
    - WLAN Wokwi-GUEST + NTP (CET/CEST), Ersatzuhr nac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
    [sketch.ino]
2026-10-06 Wokwi V3: Bluetooth-Symbol und LED-Status
    - Bluetooth-Symbol oben rechts links neben dem Akku (aus/sucht/verbunden/nicht verbunden)
    - LEDs: weiß blinken beim Suchen (2-min-Timeout), 2x lila beim Verbinden; Akku-Rot und Bernstein haben Vorrang
    - Simulation per Serial: bt suchen | bt verbunden | bt getrennt | bt aus (auch in hilfe/status)
    - Echtes BLE mit NimBLE-Arduino hinter HYDRO_BLE 1 (Name HydroDesk, Notify heute/Ziel), Partition Huge APP empfohlen
    - README: Abschnitt Bluetooth, Tests T25-T36, Speicher aller Varianten; Mockup mit BT-Symbol
2026-10-06 Android-App: Login, BLE, Room, Supabase
    - app-android/: Kotlin + Jetpack Compose (Material 3), MVVM, manuelle DI
    - Login/Registrierung mit Supabase Auth, Sitzung bleibt gespeichert
    - BLE (HydroDesk-Dienst 4f9a0001-...), Schluck-Erkennung aus dem Tagesstand
    - Room (offline-first) + WorkManager-Sync nach Supabase
    - Bildschirme: Heute, Verlauf (7-Tage-Diagramm), Profil, Admin; Demo-Modus
    - supabase/schema.sql mit RLS, is_admin(), Profil-Trigger, Views
    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
2026-10-06 Wokwi: Erinnerungslogik (Pause/Plan/Ruhezeit) und Flaschen-Kalibrierung
    Nach ≥100 ml im Trinkfenster 75-min-Pause (Demo kürzer via WOKWI_DEMO_ERINNERUNG).
    Erinnerung nur hinter Tagesplan, mit Mindestabstand, max. 6/Tag, Ruhe 22–07 Uhr.
    Service-Modus: leere/volle Flasche kalibrieren (Serial kalib/leer/voll), Kapazität speichern.
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2026-10-08 Visualisierung: Explosionsansicht, Innenansicht, Teile, Produkt
    [base.stl, cover.stl, pad.stl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]
2026-10-08 3D-Modell: komplettes Gerät (GLB/STL/3MF) und Explosionsmodell
    [hydrodesk_explosion.stl, hydrodesk_komplett.3mf, hydrodesk_komplett.stl]
2026-10-08 Gehäuse: steckbare Abdeckkappe für die CYD-USB-Öffnung + alle abgeleiteten Dateien aktualisiert
    - hydrodesk_base.scad: Teil 'cap' (Flansch 35x10,6, Stopfen mit 0,15 mm Spiel + 10 Quetschrippen, Griffkerbe),
    in assembly/exploded/section, Kollisionstests cap_check_cyd / cap_check_base
    - stl/kappe_usb.stl neu, base/cover/pad neu exportiert (Geometrie unverändert)
    - Vorschaubilder neu (kappe_eingesteckt, kappe_offen, 15_, 16_)
    - Visualisierung: alle 4 Bilder neu, Kappe beschriftet, Hinweislinien links ohne Überschneidung
    - 3d_modell: GLB/STL/3MF mit Objekt Abdeckkappe_USB (19 Teile), Vorschau neu
    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
    [base.stl, cap.stl, cover.stl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]
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2026-10-08 Vorkalkulation aktualisiert (Stand 08.10.2026): 5-V-Wandler, Schrauben, Kleinteile, Versand; Einkaufsliste mit Preisvergleich
    [Einkaufsliste_HydroDesk_guenstig.xlsx, Vorkalkulation_HydroDesk_Base.xlsx]
2026-10-08 LED: COB-Streifen WS2812B FCOB (26 LEDs) + gedruckte Diffusor-Leiste statt WS2812-ECO-Streifen; alle abgeleiteten Dateien aktualisiert
    - Gehäuse: Lichtkammer aus Parametern (cob_t = 2,5 mm, nachmessen), Falz für 1-mm-Diffusor, neues Teil diffusor_led.stl,
    Module/Deckeldom nach hinten verschoben, Kollisionsprüfungen parts_check/diff_check, Pololu S13V10F5 statt MT3608-Kommentar
    - Vorschaubilder (21), STL, Renderbilder, 3D-Modell (20 Teile inkl. COB-LED-Streifen und Diffusor) neu erzeugt
    - Firmware: LED_ANZAHL 26, LED_HELLIGKEIT max. 80 (static_assert, Strombudget), diagram.json 26 Pixel, Builds 08.10.2026
    - Vorkalkulation, Einkaufsliste, Steckbrief, README, Anleitung, Design-Prompt aktua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
    [Einkaufsliste_HydroDesk_guenstig.xlsx, Vorkalkulation_HydroDesk_Base.xlsx, base.stl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]
2026-10-08 Einkaufsliste: günstiger Korb mit Pololu S13V10F5 (Berrybase 9,95 €) statt MT3608 – MT3608 liefert bei 3,7 V nur ca. 0,5 A; Korb 84,10 € -> 92,01 €
    [Einkaufsliste_HydroDesk_guenstig.xlsx]
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2026-10-09 Gehäuse V4: Ein/Aus-Schalter C&K OS102011MS2QN1 in der linken Wand (AN/AUS-Gravur, Tasche + 2 Klemmkeile), FET-Platine mit 2× AO3401A (LED-Strom H1, Akku-Schalter H2) statt GERUI-Modul; STLs (neu: sc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
    [base.stl, hydrodesk_base.scad, hydrodesk_explosion.stl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]
2026-10-09 Doku V4: Vorkalkulation 141,81 € (ohne PLA 125,32 €) mit AO3401A von Reichelt + FET-Platine/Schalter-Teilen (Preise 09.10.2026), Einkaufsliste beide Körbe (111,04 € / 94,98 €), Steckbrief (Ein/Aus-Sc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
    [Einkaufsliste_HydroDesk_guenstig.xlsx, Vorkalkulation_HydroDesk_Base.xlsx]
2026-10-09 Lizenz: MIT ersetzt durch PolyForm Noncommercial 1.0.0 (Code) + CC BY-NC-SA 4.0 (Hardware/Design/Doku); LICENSE-Übersicht DE/EN, LICENSE-CODE.md und LICENSE-HARDWARE-DOCS.md (offizielle Texte unverän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
    [hydrodesk_base.scad]
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2026-10-16 Doku: microSD-Sniffer gestrichen (passt nicht ins Gehäuse)
    SD-Slot zeigt zur Frontwand (ca. 3,5 mm Luft); Sniffer würde ~35–40 mm
    herausstehen. GPIO18/19/23 direkt an den SD-Slot löten. Bestellsumme
    Empfohlen auf 119,27 € + Versand alleschrauben korrigiert.
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2026-11-09 Fix: kein Akku-Abschalten wenn GPIO35 noch offen floatet
    AKKU_ANGESCHLOSSEN=false überspringt Unterspannungs-Tiefschlaf und
    Akku-Warnungen; Anzeige/Log „USB (kein Akku)“. Unter 2,8 V gilt auch
    bei angeschlossenem Teiler „Messung offen“.
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

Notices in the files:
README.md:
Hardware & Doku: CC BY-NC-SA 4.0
